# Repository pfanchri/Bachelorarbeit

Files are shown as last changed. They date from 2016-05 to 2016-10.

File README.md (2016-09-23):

# Bachelorarbeit

* DVD Basisstation
* |
* +-Altium										
* | +-Box\
* | +-Libraries\
* | +-mobile Basisstation\
* | | +-Project Outputs for mobile Basisstation\
* | | +-Basisstation.SchDoc
* | | +-TDA5340.SchDoc
* | | +-XMC4500.SchDoc
* | | +-Ethernet.SchDoc
* | | +-Power Supply.SchDoc
* | | +-mobile Basisstation.PrjPcb
* | | +-mobile Basisstation.pdf
* | | +-PCB_Testplatine.PcbDoc
* | | +-PCB_Testplatine - GND mit Tracks.PcbDoc
* | | +-…
* | |
* | +-PCB\
* | +-TDA Layout von Stefan Erhard\
* | 
* |
* +-Datenblätter
* | +-allgemein\
* |
* |
* +Dave
* | +-Basisstation\
* | | +-Basisstation
* | | +-Simple_Main_Projekt
* | | +-TDA_XMC4500_PMA_testtrans
* | | +-USBLIB_VIRTUALSERIAL_XMC45
* | | +…
* | | 
* | +-Hilfen\
* | +-Libraries\
* | +-Registerberechnungen\
* | +-Treiber\
* | +-Seriennummer verwendete TDAs.txt
* |
* |
* +Latex
* | +-Bachelorarbeit\
* | | +-Abbildungen\
* | | | +-Aufnahmen\
* | | | | +-Bilder\
* | | | | +-Empfangene Daten\
* | | | | +-Logic Analyser\
* | | | | +-SmartPDF\
* | | | +-…
* | | |
* | | +-Abschnitte\
* | | +-Quellen\
* | | +-bibliography.bib
* | | +-Thesis.pdf
* | | +-Thesis.tex
* | | +-…
* | |
* | +-circuitikz-master\
* | +-auszug_din_1338.pdf
* | +-Latex Vorlage.zip
* 
*

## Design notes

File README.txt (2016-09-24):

#################### Lehrstuhl für Technische Elektronik ####################
 Prof. Dr.-Ing. Dr.-Ing. habil. Robert Weigel, Prof. Dr.-Ing. Georg Fischer
####################### Bachelorarbeit im Studiengang #######################
          „Elektrotechnik, Elektronik und Informationstechnik (EEI)“
#################### von Christof Pfannenmüller zum Thema ###################
Aufbau und Inbetriebnahme einer mobilen Basisstation für feldstärkebasierte
Lokalisierung

                  Betreuer: Dipl.-Ing. Felix Pflaum
                  Beginn: 25.04.2016 Abgabe: 26.09.2016
#############################################################################
Die folgende Übersicht zeigt die enthaltenen Dateien und Verzeichnisse:

* DVD Basisstation
* |
* +-Altium										
* | +-Box\						-Daten zum erstellten Gehäuse in SolidWorks
* | +-Libraries\					-importierte und eigene Altium Bibliotheken
* | +-mobile Basisstation\				-Projektordner Altium
* | | +-Project Outputs for mobile Basisstation\	-enthält Output-Jobfiles (Gerber, Schaltplan etc.)
* | | +-Basisstation.SchDoc				-Schaltplan Modulübersicht Basisstation
* | | +-TDA5340.SchDoc					-Schaltplan Transceiver TDA5340
* | | +-XMC4500.SchDoc					-Schaltplan Mikrocontroller XMC4500
* | | +-Ethernet.SchDoc					-Schaltplan Ethernet
* | | +-Power Supply.SchDoc				-Schaltplan für Power Supply
* | | +-mobile Basisstation.PrjPcb			-Hauptdatei für Altium Designer
* | | +-mobile Basisstation.pdf				-Layout als PDF
* | | +-PCB_Testplatine.PcbDoc				-PCB-Datei Altium Original
* | | +-PCB_Testplatine - GND mit Tracks.PcbDoc		-PCB-Datei Altium vor eingefügten Masseflächen
* | | +-…
* | |
* | +-PCB\						-Dateien über den Platinenhersteller
* | +-TDA Layout von Stefan Erhard\			-Layout des Aufsteckboards für den „XMC 2Go“
* | 
* |
* +-Datenblätter					-Datenblätter der verwendeten Bauteile
* | +-allgemein\					-Application Notes und Informationen zu Infineon
* |
* |
* +Dave
* | +-Basisstation\
* | | +-Basisstation\					-DAVE Projektordner
* | | +-Simple_Main_Projekt\				-Testprojekt zur Einführung in DAVE
* | | +-TDA_XMC4500_PMA_testtrans\			-Projekt für das im Feldtest verwendete Relax Kit
* | | +-USBLIB_VIRTUALSERIAL_XMC45\			-Beispielprojekt für virtuellen seriellen Port
* | | +…
* | | 
* | +-Hilfen\						-Hilfen zur Programmiersprache C
* | +-Libraries\					-verwendete Bibliotheken (Originale ohne Änderungen)
* | +-Registerberechnungen\				-enthält Berechnungen für Sende-/Empfangsfrequenzen
* | +-Treiber\						-Treiber für virtuellen COM-Port am Hostcomputer
* | +-Seriennummer verwendete TDAs.txt			-Seriennummern der verwendeten Transceiver
* |
* |
* +Latex
* | +-Bachelorarbeit\					-Latex Hauptordner
* | | +-Abbildungen\					-Bilder/Daten für Latex (enthält auch nicht verwendete)
* | | | +-Aufnahmen\					
* | | | | +-Bilder\					-Screenshots der verwendeten Programme
* | | | | +-Empfangene Daten\				-Aufgezeichnete Daten der Übertragungen
* | | | | +-Logic Analyser\				-Daten Logic Analyser
* | | | | +-SmartPDF\					-PDFs der Altium-Projekte mit Verlinkungen
* | | | +-…
* | | |
* | | +-Abschnitte\					-Kapitel des Latex-Dokuments
* | | +-Quellen\					-gespeicherte verwendete Quellen
* | | +-bibliography.bib				-Bibliografie-Datei für Latex
* | | +-Thesis.pdf					-erstellte Ausarbeitung als PDF-Datei
* | | +-Thesis.tex					-Latex-Date der erstellten Ausarbeitung
* | | +-…
* | |
* | +-circuitikz-master\				-Dateien für circuitikz
* | +-auszug_din_1338.pdf				-Auszug DIN 1338 zur Formatierung
* | +-Latex Vorlage.zip					-Latex-Vorlage LTE
* |
* |
* +Bilder						-aufgenommene Bilder der Bestückung/des Feldtests
* | 
* | 
*
*

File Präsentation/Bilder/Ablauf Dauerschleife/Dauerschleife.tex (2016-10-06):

% EPC flow charts
% Author: Fabian Schuh
\documentclass{minimal}

\usepackage{pgf}
\usepackage{tikz}
\usepackage[utf8]{inputenc}
\usetikzlibrary{arrows,automata}
\usetikzlibrary{positioning}

\tikzset{
    state/.style={
           rectangle,
           rounded corners,
           draw=black, very thick,
           minimum height=2em,
           inner sep=2pt,
           text centered,
           },
}

\begin{document}

\begin{tikzpicture}[->,>=stealth']

 \node[state, text width=4.5cm] (Init1) 
 {Interrupt-Flagge gesetzt?};

  \node[state,    	% layout (defined above)
  text width=2.5cm, 	% max text width
  yshift=2.5cm, 		% move 2cm in y
  left of=Init1, 	% Position is to the right of QUERY
  node distance=1.5cm, 	% distance to QUERY
  anchor=center] (Start) 	% posistion relative to the center of the 'box'
  {Initialisierung};

 \node[state,    	% layout (defined above)
  text width=3cm, 	% max text width
  yshift=2cm, 		% move 2cm in y
  right of=Init1, 	% Position is to the right of QUERY
  node distance=1.7cm, 	% distance to QUERY
  anchor=center] (Wait) 	% posistion relative to the center of the 'box'
 {Warte auf Eingabe des Benutzers};

  \node[state,    	% layout (defined above)
  text width=4.5cm, 	% max text width
  yshift=-2cm, 		% move 2cm in y
  right of=Wait, 	% Position is to the right of QUERY
  node distance=3cm, 	% distance to QUERY
  anchor=center] (Init2) 	% posistion relative to the center of the 'box'
  {Schalte alle Transceiver an,\\
  	Initialisiere XMC-Pins für Interrupts,\\
  	Initialisiere SPI-Modul};
  
%  warte, bestätige durch LED Blinken
 
  \node[state,    	% layout (defined above)
  text width=2cm, 	% max text width
  yshift=2cm, 		% move 2cm in y
  right of=Init2, 	% Position is to the right of QUERY
  node distance=2.5cm, 	% distance to QUERY
  anchor=center] (InitTDA) 	% posistion relative to the center of the 'box'
  {Initialisiere Transceiver};
  
   \node[state,    	% layout (defined above)
   text width=3cm, 	% max text width
   yshift=-2cm, 		% move 2cm in y
   right of=InitTDA, 	% Position is to the right of QUERY
   node distance=2.5cm, 	% distance to QUERY
   anchor=center] (setvariables) 	% posistion relative to the center of the 'box'
   {Löschen der Datenspeicher,\\
   	Interrupt-Status-Flaggen zu Null setzen};

 %ausgabe Warte auf Übertragungen

  \node[state,    	% layout (defined above)
  text width=2.3cm, 	% max text width
  yshift=2cm, 		% move 2cm in y
  right of=setvariables, 	% Position is to the right of QUERY
  node distance=1.7cm, 	% distance to QUERY
  anchor=center] (Dauer) 	% posistion relative to the center of the 'box'
  {Dauerschleife};

 % draw the paths and and print some Text below/above the graph

 \path 
 (Start)     	edge[bend right=20] node[anchor=south,above]{} (Init1)
 (Init1)     	edge[bend right=20] node[anchor=south,above]{} (Wait)
  (Wait)     	edge[bend right=20] node[anchor=south,above]{} (Init2)
   (Init2)     	edge[bend left=20] node[anchor=north,above]{Warten~~~~~~~~~} (InitTDA)
 (InitTDA)  	edge[loop above]    node[anchor=north,above]{für alle Transceiver} (InitTDA)
   (InitTDA)     	edge[bend right=20] node[anchor=south,above]{} (setvariables)   
   (setvariables)     	edge[bend right=20] node[anchor=south,above]{} (Dauer);

\end{tikzpicture}

\end{document}

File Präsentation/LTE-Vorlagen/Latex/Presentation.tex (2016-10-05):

% -----------------------------------------------------------------------------
% LaTeX 4Beamer Slide Template Institute for technical electrics
% -----------------------------------------------------------------------------

% -------------Preamble--------------------------------------------------------

\documentclass{beamer}
% include usepackages
\input{input/use}

% set the path for figures (save Pictures in /graphics and call it directly
\graphicspath{{graphics/}}

% ---------Data for Titlepage--------------------------------------------------

% Title of Presentation
\title[Kurzform Titel]{Hier steht der Titel}
% Subtitle of Presentation
\subtitle{Untertitel}
% Authors
\author[Kurzform der Autoren]{Hier die Autoren}
% Affiliation
\institute[Kurzform]{Zugehörigkeit}
% Date (not in use)
%\date{13. April 2016}

% Titlepage at the beginning and end of the presentation
\AtBeginDocument{\titleframe}
\AtEndDocument{\titleframe}

% -----------------------------------------------------------------------------
% Beginn Document
% -----------------------------------------------------------------------------

\begin{document}

% Table of Contents
\begin{frame}
	\frametitle{Übersicht/Content}
	\tableofcontents[pausesections]
\end{frame}

% -------------Section 1------------------------------------------------------

\section{First Section}

\begin{frame}
\frametitle{Page with Title}
\end{frame}

\begin{frame}
Page without Title
\end{frame}

% -------------Section 2------------------------------------------------------

\section{Second Section}

% Subsection
\subsection{Minipage}

\begin{frame}
\frametitle{Minipage}
\begin{minipage}{0.45\textwidth}
	Left side
\end{minipage}	
\hfill
\begin{minipage}{0.49\textwidth}
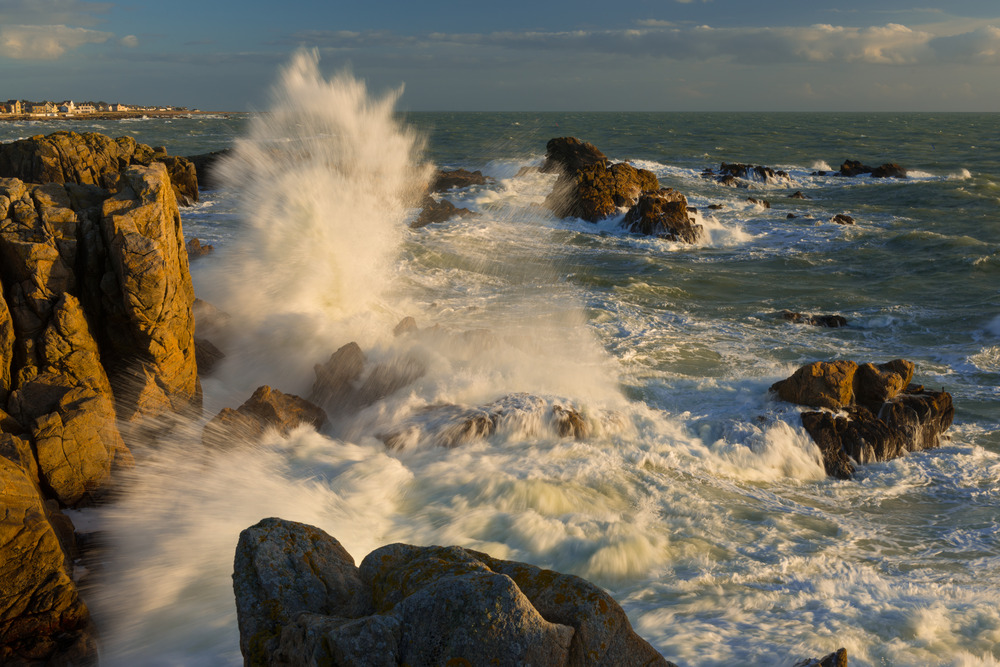
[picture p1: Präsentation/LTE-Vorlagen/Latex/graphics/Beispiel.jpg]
	
\end{minipage}
\end{frame}

% Subsection
\subsection{Columns}

\begin{frame}
\frametitle{Columns}
\begin{columns}	
	\begin{column}[c]{0.6\textwidth}

		\Large\textbf{Left side}\\
	
	\end{column}

	\begin{column}[c]{0.4\textwidth}

		\Large\textbf{Right side}\\
		
	\end{column}
\end{columns}
\vspace{1.5cm}
Below

Listing:
\begin{itemize}
	\item First item
	\item second item
\end{itemize}
\end{frame}

% -------------Section 3------------------------------------------------------

\section{Third Section}

\begin{frame}
	\begin{minipage}{0.45\textwidth}
	\textbf{Auflistung}
	\begin{enumerate}
		\item Punkt 1
		\item Punkt 2
		\item Punkt 3
	\end{enumerate}
\end{minipage}	
\hfill
\begin{minipage}{0.49\textwidth}
	
\end{minipage}
\end{frame}

\begin{frame}[plain]
\centering
\hfill
\hfill\\

\centering
\huge Vielen Dank für Ihre Aufmerksamkeit!
\end{frame}

\end{document}

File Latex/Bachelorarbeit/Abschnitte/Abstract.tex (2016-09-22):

% Abstract
\newpage
\chapter*{Abstract}
\label{sec:abstract}
\pagestyle{scrheadings}

Current localization measurements by magnitude and phase of electromagnetic waves have been complex and consume plenty of energy. However, almost every receiver has knowledge of the electrical field strength, correlating to distance from transmitter, this information is nearly unused. A multi transceiver base station should start communication with a mobile wireless sensor. The relative positioning to the base could be calculated by the received signal strength (RSSI) already provided from transceivers without additional components. Due to the permeability of walls, the possible range and the wavelength, associated to resolution of localization,   Sub-GHz frequency range is used.  Therefore six identical transceiver-ICs were arranged over all horizontal directions in space. By detachable design of the transceiver-modules a rearranging of the antennas was made feasible to provide different distances for best resolution of localization. The ICs were controlled by a XMC4500 microcontroller connected to the transceivers with SPI and IRQ line for finished transmission. Distribution of received data and signal strength measurements to a host computer is accomplished by the XMC4500 over Ethernet and USB.

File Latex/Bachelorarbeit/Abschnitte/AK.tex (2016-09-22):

%Abkürzungsverzeichnis
\newpage
\chapter*{Abkürzungsverzeichnis}
\label{sec:ak}
\pagestyle{scrheadings}

\begin{acronym}[CMSIS] %statt Bash die Längste Abkürzung einfügen
	\acro{PCB}{Printed Circuit Board}
	\acro{EDA}{Electronic Design Automation}
	\acro{CAD}{Computer-aided design}
	\acro{SMD}{Surface-mounted device}
	\acro{SPI}{Serial Peripheral Interface}
	\acro{DRC}{Design-Rule-Check}
	\acro{FIFO}{First In – First Out}
	\acro{NCS}{Non-Chip-Select}
	\acro{IC}{Integrierter Schaltkreis \acroextra{(integrated circuit)}}
	\acro{SMA}{Sub-Miniature-A}
	\acro{LQFP}{Low Profile Quad Flat Package}
	\acro{BGA}{Ball Grid Array}
	\acro{JTAG}{Joint Test Action Group}
	\acro{TVS}{Transient Voltage Suppressor}
	\acro{LDO}{Low Drop-Out}
	\acro{SOT}{Small Outline Transistor}
	\acro{STEP}{Standard for the Exchange of Product Model Data}
	\acro{NC}{Numerical Control}
	\acro{IDE}{Integrated Development Environment}
	\acro{GUI}{Graphical User Interface}
	\acro{SDK}{Software development kit}
	\acro{CPU}{Central Processing Unit}
	\acro{ETH}{Ethernet MAC \acroextra{(Ethernet Medium Access Control)}}
	\acro{USB}{Universal Serial Bus}
	\acro{GPIO}{General Purpose Input/Output}
	\acro{USIC}{Universal Serial Interface Channel}
	\acro{ISR}{Interrupt Service Routine}
	\acro{ERU}{Event Request Unit}
	\acro{ERS}{Event Request Select}
	\acro{ETL}{Event Trigger Logic}
	\acro{OGU}{Output Gating Unit}
	\acro{NVIC}{Nested Vectored Interrupt Controller}
	\acro{CMSIS}{Cortex Microcontroller Software Interface Standard}
	\acro{GND}{Masse \acroextra{(Ground)}}
	\acro{MISO}{Master-In Slave-Out}
	\acro{MOSI}{Master-Out Slave-In}
	\acro{ASCII}{American Standard Code for Information Interchange}
	\acro{IRQ}{Interrupt Request}
	\acro{PLL}{Phasenregelschleife \acroextra{(phase-locked loop)}}
	\acro{AGC}{Automatic Gain Control}
	\acro{RSSI}{Received Signal Strength Indication}

	%todo: ordnen nach auftrten
%	miso Mosi hinzufügen; GND??
\end{acronym}

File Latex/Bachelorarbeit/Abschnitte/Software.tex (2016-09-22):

\chapter{Software}
\label{sec:Software}
\pagestyle{scrheadings}
\section{DAVE Entwicklungsumgebung}

Das Programm DAVE (Digital Application Virtual Engineer) wird von Infineon Technologies AG entwickelt. Es basiert auf der Entwicklungsumgebung oder \ac{IDE} \enquote{eclipse}, die von der Eclipse Foundation entwickelt wird. Eine \ac{IDE} beschreibt dabei allgemein ein Programm zur Softwareentwicklung, welches die einzelnen dazu notwendigen Tools gesammelt zur Verfügung stellt. Dies sind vor allem der Compiler, der Linker, und der Debugger, auf die im folgenden noch eingegangen werden soll. DAVE stellt eine Möglichkeit zum Editieren von Quelltexten und Anordnen der einzelnen Programmdateien bereit. Über den enthaltenen GNU C-Compiler wird der erstellte Quellcode in vom XMC lesbare Maschinensprache übersetzt und anschließend durch den Linker zu einem ausführbaren Programm vereint. Durch den enthaltenen Debugger kann das Programm in den Speicher des XMC geladen werden. Dort kann der Programmablauf gestartet und gestoppt werden, außerdem können Werte einzelner Register und Variablen ausgelesen werden \cite{dausmann2011c}. 

DAVE greift bei der Programmierung von Mikrocontrollern der XMC-Serie auf die so genannten XMC Libraries zurück, die von Infineon ebenfalls zur Verfügung gestellt werden.  Auf diese soll ebenfalls im weiteren Verlauf  eingegangen werden. Ein weiteres Feature in der \ac{IDE} sind die sogenannten DAVE APPs. Mit diesen soll die Programmierung des Mikrocontrollers durch ein \ac{GUI} ermöglicht werden. Dazu werden für  mögliche von der Hardware zu verrichtende Teilaufgaben APPs von Infineon bereitgestellt. Durch das Einfügen der entsprechenden APPs in das Projekt können diese angepasst und miteinander grafisch verschalten werden. So wird der spätere Programmablauf im Mikrocontroller und dessen Aufgaben festgelegt. Nachdem vom Programmierer noch die Pins ebenfalls grafisch den Aufgaben zugeordnet werden, generiert  DAVE  den Programmcode mit den in den APPs enthaltenen Informationen \cite{DAVEQuickStart}.
Mithilfe des DAVE \ac{SDK} können nicht nur die Parameter der APPs beim Programmieren, sondern auch diese selbst grundlegend angepasst werden und das Entwickeln eigener APPs ist möglich \cite{DAVE-Version-4}.

Im Verlauf dieser Arbeit wurden DAVE  APPs jedoch nur in einem bereits existierenden Softwareprojekt für ein Relax Kit genutzt, mit welchem  Signale zum Testen der Empfänger an die Basisstation gesendet wurden. In der Basisstation selbst wurden die APPs nicht benutzt.

\section{Verwendete Peripherie des XMC4500}

Der XMC4500-Baustein enthält diverse funktionelle Blöcke, die mit einer Bus Matrix an die ARM Cortex-M4 \ac{CPU} angebunden sind. Dieser Aufbau soll den Prozessor entlasten und im Programmablauf Ressourcen für andere Operationen freihalten.
Für die Basisstation waren vor allem der \acs{USIC}, der \ac{USB} sowie der \ac{ETH} die bedeutenden Peripherien. Von besonderer Bedeutung sind jedoch die \acp{GPIO}.
\begin{figure}[h]
\centering

\caption{Blockdiagramm zur Peripherie des XMC4500 Mikrocontroller und die Anbindung an den Cortex-M4 Kern \cite{XMC-DataSheet}}
\label{fig:xmcblockdiagram}
\end{figure}

\subsection{GPIO}
Die \acp{GPIO} werden im sogenannten PORTS-Modul der XMC-Architektur gesteuert. In dieser lassen sich die Treiberstufen für die entsprechenden Pins des Mikrocontrollers regeln. Dieses Modul ist über die Peripheriebrücke PBA1 ebenfalls an die Bus Matrix \index{Bus Matrix} und somit an den Cortex-M4 Kern angebunden.  %Programmable port driver control module (PORTS) Abkürzung richtg?dann einfügen
%Bild StructureDigitalPin einbinden
%beschreiben wie pins belegt sind, wann GPIO bzw wann module (s. Pinbelegung) auf Pins liegen ( bei POSIF Kapitel beschreiben

Das Modul stellt für jeden Pin die erste Funktionsauswahl bereit und legt so die Datenrichtung fest. Im \enquote{Port Input/Output Control Register} des Moduls wird für jeden Pin festgelegt, ob er als Eingang oder Ausgang verwendet wird. Das momentane elektrische Potential am Eingang wird bei letzterer Konfiguration mit einem Schmitt-Trigger in ein binäres logisches Signal übersetzt. Ist der Pin ein Eingang, so kann das logische Eingangssignal dort zusätzlich invertiert werden. Wird ein Pin des XMC als Ausgang konfiguriert, so kann gesteuert werden, ob es sich um einen \ac{GPIO}-Pin handelt, dessen Status von der Software direkt festgelegt wird. Dabei kann ausgewählt werden, ob das logische Ausgangssignal durch einen Treiber in Open-Drain-Konfiguration oder durch Push-Pull erzeugt werden soll. 

Zur Nutzung eines Ausgangs durch die im Mikrocontroller verfügbare Peripherie sind diese direkt mit den entsprechenden Modulen verbunden. Dadurch kann das Modul selbst den elektrischen Zustand am Eingang auslesen und verwerten oder festlegen, ob es sich um einen Ausgang handelt \cite{XMC-Reference}. 
Auch das weitere Verhalten von Pins, wie etwa  beim Anschalten, bevor die Versorgungsspannung ein gültiges Level erreicht hat, lässt sich im PORTS-Modul anpassen.
\begin{figure}[h]
	\centering
	
	\caption{Struktur eines Digitalpins des XMC Mikrocontrollers \cite{XMC-Reference}}
	\label{fig:structuredigitalpin}
\end{figure}

\subsection{USIC}
Die \acp{IC} der XMC-Familie verfügen über ein Modul zur Kommunikation über diverse serielle Protokolle, den \acf{USIC}. Dieses ist programmierbar und erlaubt damit eine individuelle Verwendung, kann aber gleichzeitig die notwendigen Arbeiten für den Prozessor übernehmen. Der XMC4500 verfügt über insgesamt sechs \ac{USIC}-Kanäle und kann somit mehrere Protokolle gleichzeitig verwenden. Die Mikrocontroller unterstützen die  Protokolle UART, I$^{2}$C, IIS, LIN und das für die Basisstation verwendete SPI in einfacher, doppelter und quad-Ausführung. Für diese Arbeit wurde die gesamte Kommunikation mit einem gemeinsamen \acs{USIC}-Kanal umgesetzt. Da die einzelnen \acp{USIC} und deren Kanäle verschieden viele Slave-Select-Leitungen besitzen, wurde der Kanal $0$ des \ac{USIC} $0$ ausgewählt. Den nur dieser verfügt über die benötigten sechs Select-Leitungen. Eine Umsetzung mit einem anderen USIC wäre ebenfalls möglich gewesen. Die Wahl des Transceivers hätte dann aber manuell erfolgen müssen und hätte nicht vom Modul geregelt werden können.
%beschreiben Funktion
%wo SPI allgmein beschreiben
\begin{table}
	\centering
	\begin{tabular}{cc}
		
		Signal & Port/Pin des XMC \\ 
		\hline 
		MISO & 1.5 \\  
		MOSI &  1.7\\ 
		SCK (Clock) & 1.6 \\ 
		Select TDA1 & 1.11 \\  
		Select TDA2 &1.8  \\ 
		Select TDA3& 4.6 \\  
		Select TDA4& 4.5 \\  
		Select TDA5& 4.4 \\ 
		Select TDA6& 4.3 \\ 
	\end{tabular} 
	\caption[Zuordnung der SPI-Signale an die Pins des Mikrocontrollers]{Zuordnung der für die SPI-Kommunikation notwendigen Signale an die Pins des Mikrocontrollers. Alle Leitungen sind mit dem Kanal $0$ der USIC $0$ verbunden}
	\label{tab:SPI}
\end{table}

\subsection{ERU}
Von zentraler Bedeutung für die Funktion der Basisstation war die Behandlung von Interrupts durch den  \ac{IC}. Der XMC4500 besitzt dafür zwei entsprechende \ac{ERU}-Module, die einen solchen erkennen können und den Prozessor zum Aufrufen einer \ac{ISR} auffordern können. Jedes Modul verfügt über vier Kanäle, auf denen  bei einem Interrupt ein vierstufiger Prozess durchlaufen wird: In der ersten Stufe der \ac{ERU}, der sogenannten \ac{ERS}, lassen sich aus zwei Eingängen mit jeweils vier Signalen die gewünschten Eingänge wählen. In der \ac{ETL} generiert der \ac{IC} aus dem Signalstatus ein Trigger-Event, indem Veränderungen erkannt werden. So kann eine fallende oder steigende Flanke, die einen Interrupt auslösen soll, erkannt werden. In der Cross Connection Matrix können Signale der verschiedenen \acp{ETL} zu den vier \acp{OGU} weitergeleitet und somit dort untereinander und mit Triggersignalen von anderen Peripherie-Modulen des XMC kombiniert werden.  In der \ac{OGU} wird durch Vergleich der verschiedenen aufgetretenen Trigger und Muster entschieden, ob ein kompletter Interrupt aufgetreten ist, worauf diese Information entsprechend weitergeleitet wird, oder ob etwa nur ein gewähltes Muster erkannt wurde, was für andere Module wichtig sein kann. Auch diese Informationen werden entsprechend an die Peripherie weitergeleitet, sind aber für die Funktion der Basisstation nicht weiter von Bedeutung. 
Bei Vorliegen aller Bedingungen für einen Interrupt wird diese Information an den \ac{NVIC} im Cortex-M4 weitergeleitet. Dieser Teil des Prozessorkerns erkennt die Interruptaufforderung und sorgt dafür, dass der aktuelle Prozessorstatus gespeichert wird. Nach Ablauf der \ac{ISR} wird der Prozessorstatus wieder hergestellt.
%wo falsche wahl der Pins einbringen?
%Interrupt Request, IRQ im gegensatz zu isr https://de.wikipedia.org/wiki/Interrupt

\subsection{USB}
Das \ac{USB}-Modul des XMC4500 arbeitet nach den  Spezifikationen für USB 2.0 und den \enquote{On-The-Go}-Spezifikationen der Version 1.3. Der Mikrocontroller könnte durch das \ac{USB}-Modul entweder als Host oder als USB-Slave  arbeiten. In diesem Fall wurde der \ac{IC} als Slave betrieben. Das \ac{USB}-Modul verfügt über eine eigene Interruptsteuerung und ist damit eine der oben erwähnten Peripherien des XMC, deren Steuerung auch über Interrupts gelöst ist. Die gesamte Übertragung wird durch den \ac{USB}-Kern gesteuert und empfangene oder zu sendende Pakete werden in einem \ac{FIFO}-Puffer gespeichert. Für die Kommunikation der Basisstation mit dem Host-Computer wird ein virtueller COM-Port durch das \ac{USB}-Interface emuliert.

\subsection{Ethernet} 
Im XMC4500 werden Netzwerkverbindungen durch das  Ethernet-Modul behandelt. Dieses unterstützt Datenübertragungen mit Geräten über IPv4 und IPv6 sowie Übertragungsraten von \unit[10/100]{MBit/s}.  Dazu werden zunächst die Daten von der CPU über ein Bus-Interface übertragen. Im \enquote{MAC Transaction Layer} werden die vom Prozessor bzw. über Ethernet empfangenen Datenpakete zwischengespeichert. Der Ethernet-Kern formatiert die zu sendenden Daten und stellt sie einem \enquote{Physical Layer} zu, welches die Daten für den Kanal moduliert.

\section{Verwendete Bibliotheken}
\subsection{XMC Library (XMC Lib)}
Infineon stellt für seine \acp{IC} der XMC4000 Serie, zu der auch der XMC4500 gehört, die \enquote{XMC Peripheral Library} bereit. Diese erlaubt einen vereinfachten Zugriff auf alle Module und die entsprechenden Register und soll dadurch den Modulzugang übersichtlich gestalten und den Programmcode vereinfachen und leichter lesbar machen. Die Software baut auf dem \ac{CMSIS} auf, erlaubt die Verwendung verschiedener Compiler und kann kann mit oder ohne DAVE bzw. mit oder ohne DAVE APPs verwendet werden. %C99 usage +  weiter beschreiben etc
Für die Programmierung wurde mit der Software \enquote{doxygen} eine Dokumentation zur Bibliothek als HTML generiert.

\subsection{SPI Library}
Die verwendete Bibliothek zur Steuerung des \ac{SPI}-Interfaces basiert auf dem \ac{SPI}-Modul der XMC Library. Die von Infineons XMC Library zur \ac{SPI}-Kommunikation zur Verfügung gestellten Funktionen steuern das \ac{USIC}-Modul des Mikrocontrollers an. Die Bibliothek zur \ac{SPI}-Kommunikation muss somit nur noch die Funktion
\begin{lstlisting}
XMC_SPI_CH_Transmit(channel, data, XMC_SPI_CH_MODE_STANDARD);
\end{lstlisting} der XMC Library aufrufen, um eine Übertragung über das serielle Interface durchzuführen. Daneben liegt die Hauptaufgabe der Bibliothek vor allem in der Auswahl des entsprechenden Transceivers über das Slave-Select-Signal. Dazu initalisiert die Bibliothek zuerst den \ac{USIC} entsprechend den in der Headerdatei vorgegebenen Pins für MISO, MOSI und den Pins zur Auswahl des jeweiligen Slaves.

\subsubsection*{SPI Übertragung}
%todo: verschieben?
Die durch die Software umgesetzte serielle Übertragung zwischen den \acp{IC} entspricht dem \ac{SPI}-Protokoll, das ursprünglich von Motorola entwickelt wurde \cite{BuchSPI}. Durch das Chip-Select–Signal wählt der XMC den entsprechenden Transceiver aus. Da der TDA5340 active-low arbeitet, also bei anliegendem \ac{GND}-Potential als ausgewählt gilt, wird dieser Eingang im Datenblatt auch als \acf{NCS} bezeichnet. 

Der \ac{USIC} des XMC beginnt nun die Clockleitung des Busses zu treiben. Eine Periode dieser zyklischen Rechteckspannung begrenzt dabei die Zeit, in der auf den \ac{MOSI} und \ac{MISO}-Leitungen ein Bit übertragen wird. Hierbei existieren verschiedene Konfigurationen: so kann die Clock-Leitung im Ruhezustand einen High- oder einen Low-Pegel aufweisen, was durch die Polarität (CPOL) festgelegt wird. Das Auslesen der Spannungswerte auf den Datenleitungen kann bei fallender und steigender Taktflanke (CKPHA) durchgeführt werden, woraus sich insgesamt vier Kombinationsmöglichkeiten ergeben. Im vorliegenden Fall war sowohl das CPOL- als auch das CKPHA-Bit $1$, es wurde also bei jeder fallenden Flanke ein Bit übernommen und das Clocksignal wies zum Ruhezeitpunkt einen High-Pegel auf.

Bei der Übertragung stellt nach der Definition aus dem Datenblatt des Transceivers ein  Spannungspegel von \unit[0]{V} auch eine logische $0$ dar. In der Kommunikation mit den TDA5340 werden jeweils acht Bit zu einem Datenwort zusammengefasst. Der Transceiver erwartet mit dem ersten Datenwort eine Instruktion und je nach Art dieser noch einen Parameter durch die Übertragung des folgenden Wortes. Mögliche Anweisungen sind dabei das Lesen oder Schreiben eines Registers, dessen Adresse als Parameter übertragen wird, das Auslesen oder Beschreiben der \ac{FIFO}-Speicher oder das Setzen des TDA5340 in den so genannten \enquote{Transparent Mode}, auf den nicht weiter eingegangen werden soll. Nach Übertragung von Instruktion und Parameter werden entweder vom Master oder vom Slave, also vom Transceiver, die gewünschten Daten übertragen.

\begin{table}[tbh]
	\centering
	\begin{tabular}{lcl}
		
		Instruktion & Datenwort & übergebener Parameter  \\
		\hline
		Register Schreiben (schnell) & 0x01 & Adresse erstes zu schreibendes Register   \\
		Register Schreiben & 0x02 & Adresse zu schreibendes Registers   \\  
		Register Lesen & 0x03 & Adresse  zu lesendes Registers  \\  
		FIFO Lesen & 0x04 &  $kein Parameter$ \\  
		Register Lesen (schnell) & 0x05 & Adresse erstes zu lesendes Register   \\  
		FIFO Schreiben & 0x06 & Länge der Übertragung -1   \\  
	\end{tabular}
	\caption[SPI-Instruktionen des Transceivers und die entsprechenden Datenwörter]{SPI-Instruktionen des Transceivers und die entsprechenden auf der MOSI-Leitung übertragenen Datenwörter und Parameter. Die beiden Instruktionen zum transparenten Senden sind nicht enthalten}
	\label{tab:SPIcommands}
\end{table}

Beim Schreibzugriff auf den TDA kann durch geeignete Instruktion gewählt werden ob, nur auf ein Register geschrieben wird oder ob der Transceiver nachfolgende Datenwörter als Werte in die folgenden Register übernehmen soll. 
Beim Lesezugriff besteht dieselbe Auswahlmöglichkeit. Bild \ref{fig:spistart} zeigt den Start einer solchen \ac{SPI}-Kommunikation zwischen dem Transceiver TDA1 und dem Mikrocontroller. Die Dauer der Übertragung betrug etwa \unit[0,26]{ms}. Bei dieser wurde die Instruktion \enquote{Read from Chip}, dargestellt durch den Hexadezimalwert 0x03, und die Registeradresse 0xD3, als Parameter vom Mikrocontroller zum Transceiver übertragen. Dieser teilt durch das folgende Datenwort auf der \ac{MISO}-Leitung, in diesem Fall 0xFF, den aktuellen Wert des Registers mit. Der Master beendet daraufhin die Kommunikation durch einen High-Pegel an der Select-Leitung.

\begin{figure}[h]
\centering

\caption{Start einer SPI-Übertragung zwischen dem Mikrocontroller und dem Transceiver}
\label{fig:spistart}
\end{figure}

\subsection{TDA5340 Library}
Die Hauptaufgabe in der Kommunikation mit den Transceiver-\acp{IC} wurde durch die vorgegebene Bibliothek für den TDA5340 übernommen. Diese stellte Funktionen zum Senden und Empfangen von Daten mit dem Transceiver zur Verfügung. Die Bibliothek liest dazu den Empfangs-\ac{FIFO} aus oder schreibt in den Puffer für zu sendende Daten. Auch der Lese- und Schreibzugriff auf die Steuerregister der Transceiver kann über die Bibliothek geregelt werden. Dazu stellt die Bibliothek auch entsprechende Makros bereit, welche die Namen der Register in die hexadezimale entsprechende Adresse umwandeln, um so die Lesbarkeit erheblich zu erhöhen. Daneben wurden über die Bibliothek auch die notwendigen  Einstellungen für das Erkennen von Interrupt im XMC4500 vorgenommen. In diesem Bereich waren die notwendigen Anpassungen der Library am tiefgreifendsten, da diese nur für die Interruptbehandlung mit einem Transceiver ausgelegt war. Bei anderen Funktionen der Bibliothek waren nur kleinere Anpassungen notwendig, sodass etwa sichergestellt wurde, für welchen Transceiver die aufgerufene Funktion ausgeführt werden sollte, etwa bei welchem das entsprechende Register ausgelesen wurde.
Zur Verbindung mit den TDA5340 verwendete die Bibliothek die bereits erwähnte SPI Library. Dieser Bibliothek für die SPI-Verbindung wird daher die Nummer des Transceivers als Chip-Select übergeben um sicherzustellen, dass mit dem Richtigen  kommuniziert wird.

\subsection{Virtueller COM Port}
Die Kommunikation der Basisstation mit dem Hostcomputer zum Übertragen der gemessenen Werte wurde nach dem Vorbild eines Beispielprojektes für DAVE umgesetzt. Die Bereitstellung des virtuellen seriellen Ports erfolgt auf Seiten des XMC über die LUFA (Lightweight USB Framework for AVRs)-Bibliothek. Mit dieser beschränkt sich die Ausgabe über den COM-Port auf das Übergeben der zu sendenden Zeichen an eine entsprechende Funktion. Eine Steuerung des XMC durch Empfangen von Daten über den COM-Port wäre mit der Bibliothek ebenfalls möglich, dies war jedoch nicht notwendig.
Die Bibliothek und das Beispielprojekt wurden dahingehend angepasst, dass ganze Zeichenketten statt nur einzelner Zeichen der Funktion zum Senden übergeben werden konnten. Auch wurde das Senden von Integer-Variablen ermöglicht, indem diese zu Zeichen umgewandelt wurden. Dabei wurde der \ac{ASCII} beachtet, nach dem die Übertragung funktioniert. So benötigt der COM-Port zur Ausgabe und Darstellung der Ziffer $1$ den dezimalen Wert $49$ nach der Vorgabe durch den \ac{ASCII}-Code.

\section{Programmablauf}
\begin{figure}[h]
\centering

\caption{Programmablauf der Basisstation}
\label{fig:initialisierung}
\end{figure}

Im Programmablauf des XMC wurde zunächst eine Warteschleife umgesetzt, in welcher der Mikrocontroller auf eine erste Eingabe durch den Benutzer am Hostcomputer wartet. Bereits hier wurde die Übertragung über den seriellen COM-Port initialisiert. Nachdem diese Bestätigung über den COM-Port vom Mikrocontroller empfangen wurde setzt dieser zunächst alle Transceiver in den Schlafmodus, von welchem aus eine Kommunikation möglich ist. Daraufhin beginnt der XMC4500 mit der Konfiguration der für die Interrupts notwendigen Pins und ermöglicht somit das Empfangen von \acp{IRQ} durch die TDA5430. Anschließend initialisiert er zunächst das SPI-Modul, um im Folgenden die Transceiver darüber konfigurieren zu können. Bevor das dazu notwendige Schreiben in die Register der TDAs jedoch möglich ist, wird eine gewisse Verzögerung benötigt. Diese resultiert daher, dass der Wechsel des TDA vom ausgeschalteten Zustand in den Schlafmodus eine gewisse Zeitspanne benötigt. 
Im folgenden werden alle Transceiver initialisiert und anschließend in den Receiver-Modus gefahren.  
Daraufhin setzt der \ac{IC} noch alle für die Übertragung notwendigen Variablen  und alle Felder zum Speichern von Daten zu Null. 
Nun beginnt der Prozessor mit einer Dauerschleife, in der dieser auf das Ankommen von Übertragungen wartet und teilt dies auch dem Benutzer am Hostcomputer über eine Ausgabe mit. In dieser Endlosschleife wechselt sich die interruptbasierte Datenerfassung mit der Weiterleitung der erfassten Daten zyklisch ab, wobei nur bei erfolgreichem Empfang ein Senden an den steuernden Computer erfolgt. 
%todo: einfügen eines ablaufdiagramms?
%TODO:genauer alles?!; wo beschreiben? 

Bei der Programmierung wurde darauf geachtet, möglichst alle Konstanten wie Adressen von Pins und Ports durch Makros für den Präprozessor auszulagern. Dadurch konnte einerseits die Lesbarkeit des Quellcodes erhöht werden, andererseits sind so aber Änderungen durch Vertauschen von Pins sowohl in der Hardware als auch nur in der Software leichter möglich. Da es sich beim XMC4500 um einen Mikrocontroller mit einer 32-Bit-Architektur handelt, wurden Integervariablen ausschließlich vom Typ \textit{uint32\_t} oder \textit{int32\_t} verwendet. So konnte eine genaue Anpassung der Software an die Registergrößen im XMC vorgenommen werden.

\subsection{Konfiguration der Funkmodule}
Bei der Initialisierung erhalten die Transceiver die gewünschten Werte für die Sende- und Empfangsfrequenzen. Diese werden über die Teilerrate für die  \ac{PLL} übergeben und ermittelt. Der TDA5340 stellt dafür mehrere Konfigurationssätze zur Verfügung, in denen unterschiedliche Frequenzen eingestellt werden können. In diesem Fall wird zum Empfangen die Konfiguration A und Konfiguration B zum Senden eingestellt. Die entsprechenden Werte wurden zuvor aus der Zwischenfrequenz  $f_{IF2}=\unit[274]{kHz}$ und der gewünschten Übertragungsfrequenz errechnet.

Über die entsprechenden Register wird auch das Verhalten bei ankommenden Übertragungen eingestellt. Im \enquote{Interrupt Mask}-Register wurde eingestellt, bei welchen Ereignissen der Transceiver einen solchen auslösen wird. Zur Ausgabe der Interruptsignale wurde der standardmäßige PP2-Pin des Transceivers verwendet. PP1 und PP0 wurden in einen hochohmigen Zustand versetzt, da sie zum aktuellen Zeitpunkt nicht genutzt wurden.

%und rechnung aus exekl sheet einfügen

%TODO hier  fehlt etwas

\subsection{Interruptbasierte Datenerfassung}

Die Erfassung der Daten erfolgt im Programmablauf innerhalb der dauerhaften Ablaufschleife.
In der \acf{ISR}, in welche der Prozessor beim Auftreten eines Interrupts springt, wird lediglich einer globalen Variable der Wert $1$ zugeordnet. Für jeden der möglichen Transceiver existiert eine solche Flagge, die einen aufgetretenen Interrupt anzeigt. Nach dem Setzen in der \ac{ISR} kehrt der Prozessor zum Ablauf in die Dauerschleife zurück. Innerhalb dieser wird nun zyklisch abgefragt, ob diese Flagge gesetzt wurde. Beim Auftreten einer solchen Flagge, also nach dem aufgetretenen Interrupt, liest der XMC4500 die  Interrupt Status Register des entsprechenden Transceivers aus. 

Da davon auszugehen ist, dass alle sechs Transceiver-\acp{IC} zeitgleich eine Übertragung erhalten, wurde diese mehrstufige Abfrage gewählt. So wird zuerst nur in der \ac{ISR} die Flagge gesetzt, um die dadurch verstreichende Zeit möglichst kurz zu halten und zu ermöglichen, dass eine solche Flagge auch jederzeit im Programmablauf gesetzt werden kann. In der zweiten Stufe liest der Mikrocontroller nun die drei Interrupt Status Register aus. Dies ist notwendig, da es sich dabei um sogenannte \enquote{Read-Clear}-Register handelt, welche  nach dem Auslesen über SPI automatisch zurückgesetzt werden.
In den Interrupt-Registern sind die Ereignisse kodiert, die einen Interrupt ausgelöst haben. Bei der Konfiguration der Funkmodule wurde eingestellt, bei welchen Ereignissen der Transceiver einen Interrupt auslöst. Typische Ereignisse sind ein fast gefüllter Empfangs-\ac{FIFO}, was eine angekommene Übertragung anzeigt, oder auch ein leerer \ac{FIFO}, was anzeigt, dass dieser ausgelesen wurde. 

Die dritte Stufe  der Datenerfassung ist nun die Abfrage der Daten vom Transceiver. Da diese \ac{SPI}-Datenübertragung deutlich mehr Zeit in Anspruch nimmt, muss diese getrennt vom Erkennen der Interrupts und dem Auslesen der Interrupt-Register erfolgen. Da die gewünschten Werte in den Registern gespeichert sind, ist das Auslesen zeitkritisch, denn eine erneute Übertragung würde diese Messwerte überschreiben. Jedoch ist das Auslesen der Werte bei weitem nicht so zeitkritisch wie die ankommenden Interrupts, da diese im Verlauf einer Übertragung auch mehrfach ankommen können. Das Abfragen der empfangenen Daten aus dem \ac{FIFO}-Speicher hat eine noch geringere Priorität, da dieser die Datenpakete bis zum Auslesen behält. 

Eine Abfrage der Messwerte und ein Auslesen des \ac{FIFO} wird bei abgeschlossener Übertragung durchgeführt, diesen Zeitpunkt erkennt der Mikrocontroller durch das entsprechend gesetzte Bit des Interrupt-Register. Der XMC4500 speichert alle abgefragten Werte wie Feldstärke, die Einstellungen der \ac{AGC} und die angekommenen Daten in den vorbereiteten dedizierten Speichern. Abschließend werden die Transceiver wieder in den Empfangsmodus gesetzt. 

Beim Setzen der Flaggen durch den Interrupt fiel auf, dass die Interrupteingänge für Transceiver 3 und Transceiver 6 sich überlagern. So ist der PP2-Anschluss des dritten TDA5340 mit der \ac{ETL}3 der \ac{ERU}0 verbunden, ebenso wie der entsprechende Pin des TDA6. Grund dafür ist, dass die entsprechenden Pins des Mikrocontrollers auf den Kanal B3 bzw. A0 der genannten \ac{ERU}-\ac{ETL}-Kombination führen. Bei den ersten Tests von Interrupts auf diesen Kanälen stellte sich heraus, das der XMC, entgegen den Erwartungen, somit nicht in der Lage ist, ankommende Interrupts der beiden Transceiver zu unterscheiden. Durch entsprechende Einstellungen in der \ac{ERU}0 war ein Sprung des Prozessors in die entsprechende \acl{ISR} nur für jeweils einen der beiden Transceiver möglich. Um trotzdem ein Auslesen der beiden Transceiver zu bewirken, wurden beide Flaggen in der Service Routine gesetzt.
\begin{table}[h]
	\centering
\begin{tabular}{ccccc}
	Transceiver & Port/Pin am XMC & ERU & ETL & Kanal \\ 
	\hline
	TDA1 & 0.3 & 1 & 3 & B0 \\ 
	TDA2 & 1.0 & 0 & 3 & B0 \\ 
	TDA3 & 2.6 & 0 & 1 & B3 \\ 
	TDA4 & 2.1 & 1 & 0 & B0 \\ 
	TDA5 & 3.2 & 0 & 0 & A1 \\ 
	TDA5 & 0.10 & 0 & 1 & A0 \\ 
\end{tabular} 
\caption{PP2-Pins der Transceiver mit den entsprechenden Anschlüssen am XMC4500 und die Verbindung zur ERU}
\label{tab:PP2ERU}
\end{table}
Der Versuch, den PP2-Pin des TDA6 mittels eines kurzen Drahtes auf den Pin 142 des XMC4500 zu legen, schlug ebenfalls fehl. Dazu wurde der PP1-Pin des TDA1, welcher mit diesem Pin des Mikrocontrollers verbunden ist, im Transceiver 1 in einen hochohmigen Zustand geschaltet. Dieser Pin des XMC ist intern mit der \ac{ETL}2 der \ac{ERU}0 auf dem Kanal B3 verbunden. Da diese Kombination noch nicht verwendet wurde, hätte hier eine Interrupterkennung funktionieren müssen. Warum durch diese Veränderung kein Interrupt ausgelöst werden konnte, ist nicht klar. Da in der Betrachtung mit dem Logic-Analyser keine Flanke auf dem Netz festgestellt wurde, ist zu vermuten, dass das Problem aus der Verbindung mit dem Draht resultiert.
%unterscheidung der zwei interruptabfragen
%was steht in den registern drinnen und wird abgefragt

\subsection{Weiterleitung der erfassten Daten}
Dass eine Übertragung über den COM-Port bereits weit vor der Dauerschleife vom Mikrocontroller gestartet wurde, diente dazu, dem Benutzer  die Bereitschaft zum Empfangen mitzuteilen, sobald sämtliche Initialisierungen abgeschlossen waren. Somit musste der COM-Port auch nun nicht mehr selbst initialisiert werden.
Im zweiten Teil der Ablaufschleife des Programmes wurde nun die Weitergabe der empfangenen Daten und der gemessenen Werte behandelt. Dazu wurde nach dem Abholen der empfangenen Daten von den Transceivern eine Statusflagge in Form einer Integer-Variable gesetzt. Nur beim Auftreten dieser Flagge wurde der Programmteil zum Senden über den COM-Port ausgeführt.
Dort wurde nun jeweils abwechselnd ein Wert des Speichers und ein String mit einer Beschreibung oder dem Namen des Wertes über den COM-Port ausgegeben. Ein Ausschnitt des Quellcodes ist im Quellcode \ref{listing:COMsend} zu erkennen. Die Zeichenfolge $\backslash r\backslash n$ stellt dabei den Übergang in eine neue Zeile in der Ausgabekonsole dar. Wie in C üblich werden Strings in doppelten Anführungszeichen im Quelltext eingefügt. Eine entsprechende Ausgabe ist in Bild \ref{fig:ConsolePutty} zu erkennen. 
\begin{lstlisting}[caption={Ausschnitt aus dem Senden der Daten über den COM-Port},label={listing:COMsend},captionpos=b,language=C]
COM_send_string("#################### Übertragung erkannt ####################\r\n");
COM_send_string("Übertragung Nummer ");
COM_send_int_as_string(transfernumber);
COM_send_string("\r\n\r\n");
COM_send_string("TDA1:");
COM_send_string("\r\nPMF:");
COM_send_int_as_string(rssiTDA1.pmf);
COM_send_string("\r\nPRX:");
COM_send_int_as_string(rssiTDA1.prx);
COM_send_string("\r\nRX:");
COM_send_int_as_string(rssiTDA1.rx);
COM_send_string("\r\nPPL:");
COM_send_int_as_string(rssiTDA1.ppl);
COM_send_string("\r\nAGC:");
\end{lstlisting}
Am Hostcomputer wurden die Daten mit der Software \enquote{PuTTY} entgegengenommen und dem Benutzer in einer Konsole angezeigt. Dazu wurde der von Infineon zur Verfügung gestellte Treiber verwendet, um dem XMC4500 als COM-Port zu erkennen. %im Anhang/auf CD
Die Einstellungen der seriellen Übertragung wurden vom Beispielprojekt übernommen, sodass am Computer mit einer Baudrate von \unit[115200]{Bd} und acht Daten Bits pro Zeichen empfangen wurde,  was im Programm eingestellt werden musste. Nach der bereits erwähnten anfänglichen Bestätigung der Kommunikation durch den Nutzer wurden bei jeder vom Mikrocontroller erkannten Übertragung die gemessenen Feldstärkewerte ausgegeben. Neben den PMF, PRX RX, PPL und AGC-Werten wurde noch die Empfangsleistung ausgegeben. Diese wurde zur Laufzeit aus dem PPL und dem AGC-Wert errechnet und in dBm angezeigt. Dazu diente eine vorgegebene Funktion, welche aus dem PPL-Wert und dem Wert der \ac{AGC} mittels kalibrierter Parameter eine Feldstärke berechnete. Die Werte wurden in einem Vorprojekt durch Messungen kalibriert und sind hier nicht weiter von Bedeutung. Die Abkürzungen der übertragenen Werte sind in Tabelle \ref{tab:RSSI} aufgeführt.
\begin{table}[tbh]
	\centering
	\begin{tabular}{ll}
		
		PMF			&Peak Memory Filter\\
		PRX			&Peak Detector\\
		RX			&\acf{RSSI}\\
		PPL			&RSSI Payload Peak Detector\\
		AGC			&Automatic Gain Control\\
		
	\end{tabular}
	\caption{Verwendete Abkürzungen der übertragenen Messwerte}
	\label{tab:RSSI}
\end{table}
Die empfangenen Daten wurden ebenfalls ausgegeben. 
Alle Werte und Daten wurden nach Transceiver getrennt ausgegeben, um eine Vergleichsmöglichkeit zu geben und um die Ausgabe möglichst übersichtlich zu gestalten.
Auch wurden die empfangenen Übertragungen durchnummeriert und die entsprechende Übertragungsnummer mit ausgegeben. So ließen sich einerseits die Sendepositionen den gemessenen Werte zuordnen. Andererseits waren so aber auch  verlorengegangene  Übertragungen sichtbar. Eine typische Ausgabe der Konsole ist im Bild \ref{fig:ConsolePutty} zu erkennen. Zur Darstellung einer eingegangenen Übertragung an der Basisstation sollte die LED Nummer 7 nach jedem Empfangen kurz rot aufblinken.
\begin{figure}[h]
\centering
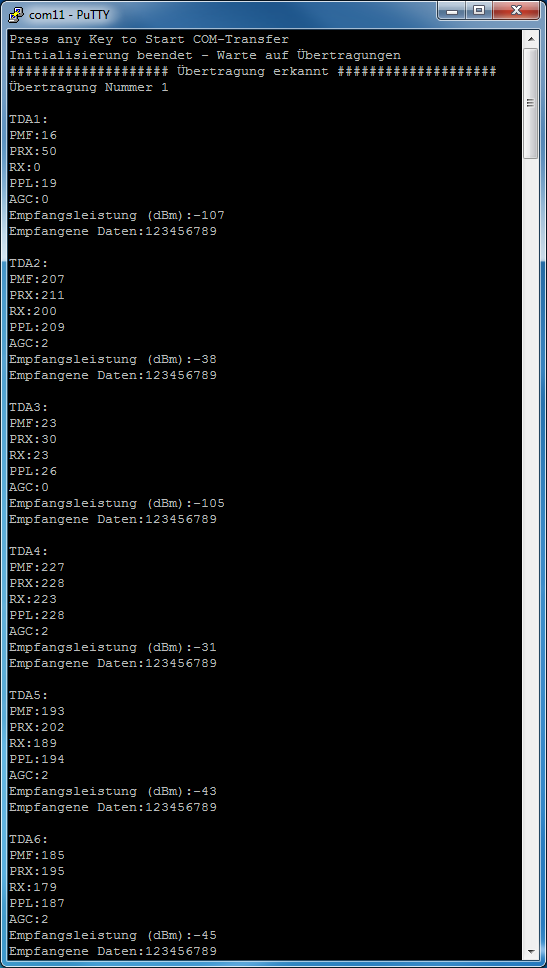
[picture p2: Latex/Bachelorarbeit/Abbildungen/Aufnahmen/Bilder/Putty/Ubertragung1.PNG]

\caption{Ausgabe des Mikrocontrollers über den COM-Port in der Konsole bei einer beispielhaften Übertragung}
\label{fig:ConsolePutty}
\end{figure}

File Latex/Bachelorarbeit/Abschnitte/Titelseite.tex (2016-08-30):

\begin{titlepage}
\ThisLRCornerWallPaper{0.66}{Abbildungen/Logo/Friedrich_logo_dunkel}
%\begin{center}
%\includegraphics[width=0.6\textwidth]{Abbildungen/Logo/FAUlogo.eps}
%\end{center}
\begin{figure}
\hfill

\end{figure}
%\newline
%\newline
\hspace{0.1cm}	
\center
\LARGE
	\textbf{Lehrstuhl für Technische Elektronik} \\
	Prof.~Dr.-Ing.~Dr.-Ing.~habil.~Robert~Weigel	\\
	Prof.~Dr.-Ing.~Georg~Fischer\\
\vspace{1cm}	

\LARGE
	\textbf{Bachelorarbeit}
\vspace{0.9cm}

\large
im Studiengang\\ \enquote{Elektrotechnik, Elektronik und Informationstechnik (EEI)}\\
\vspace{0.5cm}
von
\vspace{0.5cm}

\LARGE{
\authorname}
\vspace{0.7cm}

\large
zum Thema
\vspace{0.9cm}

\LARGE
\textbf{Aufbau und Inbetriebnahme einer mobilen Basisstation für 
feldstärkebasierte Lokalisierung}
\vspace{1.7cm}

\large
\begin{tabular}{ll}
Betreuer: & Dipl.-Ing. Felix Pflaum \\
 &\\
Beginn: & 25.04.2016\\
Abgabe: & 26.09.2016\\
\end{tabular}
\end{titlepage}

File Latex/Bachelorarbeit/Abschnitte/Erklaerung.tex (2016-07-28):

% Erklärung

\chapter*{Erklärung}
\label{sec:Erklärung}
%\newpage
%\thispagestyle{empty}
%\noindent
Ich versichere, dass ich die Arbeit ohne fremde Hilfe und ohne Benutzung anderer als der angegebenen Quellen angefertigt habe und dass die Arbeit in gleicher oder ähnlicher Form noch keiner anderen Prüfungsbehörde vorgelegen hat und von dieser als Teil einer Prüfungsleistung angenommen wurde. \\
\\
Alle Ausführungen, die wörtlich oder sinngemäß übernommen wurden, sind als solche gekennzeichnet. \\
\vspace{1.0cm}
\\
Erlangen, den 26. September 2016
\vspace{2.5cm}
\\
Christof Pfannenmüller

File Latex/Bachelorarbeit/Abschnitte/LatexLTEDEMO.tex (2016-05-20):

% Motivation

\chapter{Einleitung}\label{Einleitung}
Hier gehört die Einleitung/Motivation hin. Auf Kapitel \ref{Einleitung} kann so verwiesen werden.

\section{Nötige Programme}
Für die Arbeit mit Latex benötig man eine Tex-Distribution, verbreitet sind hier Miktex und TExlive, empfohlen wird Texlive(\url{https://www.tug.org/texlive/}) in der aktuellsten Version(Upgraden!).

Außerdem benötig man einen Editor, verbreitet sind hier Texniccenter, Texmaker, TexmakerX und Texstudio. Empfohlen wird Texstudio(\url{http://www.texstudio.org/}).

Für die Literaturverwaltung (Erstellen der Bibfiles )kann ein einfacher Texteditor(Notepad++) Texstudio oder (für poweruser) jabref  verwendet werden.

\section{Einige tex Kommandos}\label{sec:texkommandos}
\markboth{Einige tex Kommands}{Einige tex Kommands} %für die kopfzeile

Auf eine Überschrift \ref{sec:texkommandos} kann so verwiesen werden. Unter jedem Kapitel und jeder Überschrift sollte zumindest ein Satz Text stehen.

\subsection{Unterüberschrift}
Je kleiner, desto mehr "`sub"'s kommen davor.

\subsection{Bilder und Quellen}

Auf ein Bild kann mit Abb. \ref{fig:textreferenz} verwiesen werden. Dies sollte immer passieren, bevor es im erscheint. Einige Beispielplots finden sich außerdem im Anhang.

%empfänger
\begin{figure}[h] %h(ere), t(op), b(ottom) stehen für den ort an dem das bild wenn möglich erscheint. ! und großschreibung sind strikter. bei htb wird zuerst das h beachtet, dann das t usw
\centering
 %Größe, Ort, am besten als vektorgraphik (pdf), Photos als jpg
\caption{Beschreibung (Quellen dahinter) \cite{BibDEMO1}\cite{BibDEMO2}}
\label{fig:textreferenz}
\end{figure}

Eine Quelle wird direkt hinter dem Satz vor dem Punkt angegeben mit \cite{BibDEMO1}, oder aber hinter einem kompletten Absatz. Auch Formeln (im Text) und Bilder (in der caption) müssen eine Quellenangabe enthalten.

Schöne Schaltpläne lassen sich auch direkt in Latex mi tikz/circuitikz malen, siehe \ref{tikz}.

\begin{figure}
	\centering
	\tikzsetnextfilename{XX_DEMO_tikz} %Dateiname, unter der die datei im ordner tikz-ext-out angelegt wird
	\tikzset{external/remake next} %uncomment to force remake figure
	\begin{tikzpicture}[scale=.8,transform shape]
	
	\draw  (0,0)coordinate[rground](start) to [vsourcesin,v<=$u_e$]++(0,3)to[R,l=$R_1$]++(4,0)coordinate[circ](knoten1)
			to [R,l=$R_3$]++(4,0) coordinate[circ](knoten2) --++(1,0) node[op amp,anchor=-](opv){};
			\draw (knoten1) to[C,l=$C_2$](knoten1|-start) coordinate[rground];
			\draw (knoten2) to[C,l=$C_1$]++(0,3) coordinate[circ](knoten3);
			\draw (knoten1) to[R,l=$R_2$]++(0,3)--(knoten3);
			\draw (opv.out)--++(1,0)|-(knoten3);
			\draw (opv.+)--++(-1,0)--++(0,-1)coordinate[rground];
			\draw (opv.out)++(1,0)to[short,*-o]++(1,0) coordinate(out);
			\draw  [->,shorten >=1ex,shorten <=1ex,thick] (out) -- (out|-start) node[left,midway] {\Large$u_a$};
			\draw (out|-start) coordinate[rground] coordinate[ocirc];
			
			\draw (knoten1) node[above left]{$\varphi_1$};
			\draw (knoten2) node[above left]{$\varphi_2$};
	\end{tikzpicture}
	\caption{Toller Schaltplan mit circuitikz (\url{https://github.com/lte-fau/circuitikz})}
	\label{tikz}
\end{figure}

\subsection{Formeln}

Auf Formeln kann mit \ref{eqn:tc} verwiesen werden. Konstanten und mathematische Funktionen (z.B. ln), sowie Einheiten sollten dabei nicht kursiv geschrieben werden. Zwischen einer Zahl und der Einheit ist ein halbes Leerzeichen mit 1,0\,\textmu V zu setzen. Das Komma ist bei der Zahl kein Punkt, die für Spannung steht das deutsche "`U"' und nicht "`V"'.

\begin{eqnarray}\label{eqn:tc}
X_{Strom}=\text{Konstante} \cdot 1,0\,\text{mV} \cdot \frac{1}{I} \cdot \frac{\partial I}{\partial T}
\end{eqnarray}

\subsection{Häufige Fehler}
Es sollten alle Dokumente im Format "utf8" gespeichert werden.

%Kommentare sind jederzeit mit einem %-Zeichen möglich

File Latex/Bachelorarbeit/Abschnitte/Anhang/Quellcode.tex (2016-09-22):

\section{Quellcode}
\label{app:Quellcode}
Im Folgenden sind die Main-Datei des Softwareentwurfs sowie die Interrupt Service Routinen dargestellt.
\subsection{Main.c}
\lstinputlisting[caption={Hauptdatei des Softwareentwurfs},label={listing:Main},captionpos=t,language=C]{../../Dave/Basisstation/Basisstation/Main.c}
\subsection{ISRs.c}
\lstinputlisting[caption={Interrupt Service Routinen des Softwareentwurfs},label={listing:ISR},captionpos=t,language=C]{../../Dave/Basisstation/Basisstation/ISRs.c}
%\subsection{Init.c}
%\lstinputlisting[caption={Initialisierung des Softwareentwurfs},label={listing:Init},captionpos=t,language=C]{../../Dave/Basisstation/Basisstation/Init.c}

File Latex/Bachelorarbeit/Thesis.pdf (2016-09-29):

## Lehrstuhl für Technische Elektronik

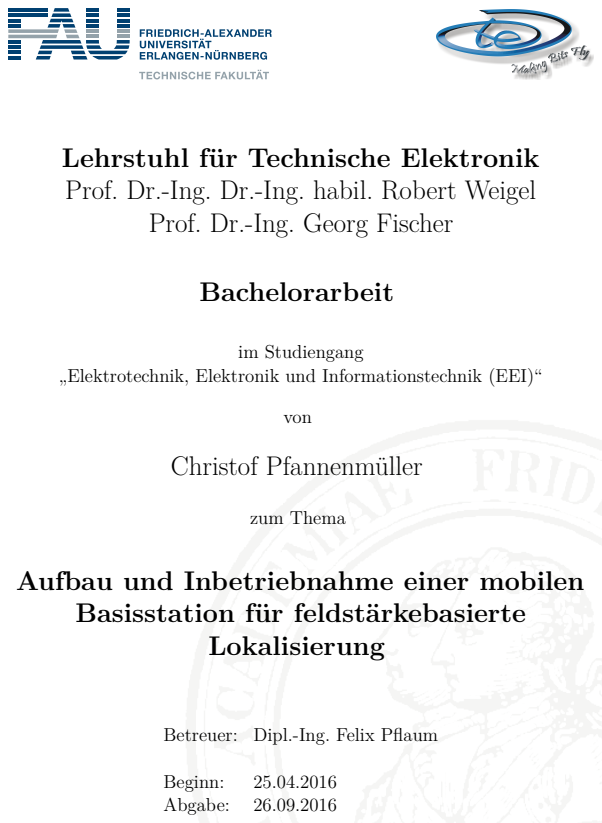
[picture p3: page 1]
Bachelorarbeit; im Studiengang; von; Christof Pfannenmüller; zum Thema; Lokalisierung; Beginn:; Abgabe:

Prof. Dr.-Ing. Dr.-Ing. habil. Robert Weigel

Prof. Dr.-Ing. Georg Fischer

„Elektrotechnik, Elektronik und Informationstechnik (EEI)“

Aufbau und Inbetriebnahme einer mobilen
Basisstation für feldstärkebasierte

Betreuer: Dipl.-Ing. Felix Pflaum

# Erklärung

Ich versichere, dass ich die Arbeit ohne fremde Hilfe und ohne Benutzung anderer als der angegebenen Quellen angefertigt habe und dass die Arbeit in gleicher oder ähnlicher Form noch keiner anderen Prüfungsbehörde vorgelegen hat und von dieser als Teil einer Prüfungsleistung angenommen wurde.

Alle Ausführungen, die wörtlich oder sinngemäß übernommen wurden, sind als solche gekennzeichnet.

Erlangen, den 26. September 2016

Christof Pfannenmüller

iii

# Kurzfassung

Ziel der vorliegenden Arbeit war der Aufbau einer Basisstation mit sechs unabhängigen Transceivern. Der Einsatz dieses Aufbaus diente der späteren Lokalisierung von Sensoren oder anderen Sendern im Sub-GHz-Frequenzbereich um 868 MHz. Die relative Ortsbestimmung zur Basis sollte energieeffizient sein und gleichzeitig eine hohe Auflösung bieten.
Die genaue Position des Senders wurde dazu auf Basis der unterschiedlichen Feldstärken an den Transceivern eruiert. Ausgenutzt wurde dabei, dass typische integrierte Transceiver die Empfangsfeldstärke selbst auswerten und bereitstellen, sodass diese ausgelesen werden kann. Das Erkennen von Übertragungen und das anschließende Auslesen der anfallenden Daten wurde dabei von einem Mikrocontroller übernommen. Zur weiteren Verarbeitung der Daten sollten diese anschließend einem Computer zur Verfügung gestellt werden. Dazu wurde sowohl eine USB- als auch eine Netzwerk-Schnittstelle vorgesehen. Die beim Aufbau der Platine verwendete Hardware basierte zum Großteil auf Bauteilen des Herstellers Infineon. Beim Layout der Platine wurden die sechs Transceiver sternförmig und regelmäßig um den Mikrocontroller und dessen Peripherie angeordnet, um ein gleichmäßiges Empfangsverhalten aus allen Raumrichtungen zu gewährleisten. Die Funksegmente der Platine wurden so gestaltet, dass diese bei Bedarf abgetrennt und mit einer Kabelverbindung weiter voneinander entfernt werden konnten. Antennen zum Senden wurden über Steckverbinder an die Basisstation angeschlossen.
Der anschließende Softwareentwurf für die Basisstation nutzte zu einem Großteil bereits bestehende Bibliotheken und hatte zur Aufgabe, ankommende Übertragungen zu erkennen, die zur Ortung notwendigen gemessenen Werte abzufragen und an den Hostcomputer weiterzuleiten.

v

# Abstract

Current localization measurements by magnitude and phase of electromagnetic waves have been complex and consume plenty of energy. However, almost every receiver has knowledge of the electrical field strength, correlating to distance from transmitter, this information is nearly unused. A multi transceiver base station should start communication with a mobile wireless sensor. The relative positioning to the base could be calculated by the received signal strength (RSSI) already provided from transceivers without additional components. Due to the permeability of walls, the possible range and the wavelength, associated to resolution of localization, Sub-GHz frequency range is used. Therefore six identical transceiver-ICs were arranged over all horizontal directions in space. By detachable design of the transceiver-modules a rearranging of the antennas was made feasible to provide different distances for best resolution of localization. The ICs were controlled by a XMC4500 microcontroller connected to the transceivers with SPI and IRQ line for finished transmission. Distribution of received data and signal strength measurements to a host computer is accomplished by the XMC4500 over Ethernet and USB.

vii

# Abkürzungsverzeichnis

PCB | Printed Circuit Board | 3
EDA | Electronic Design Automation | 3
CAD | Computer-aided design | 3
SMD | Surface-mounted device | 4
SPI | Serial Peripheral Interface | 5
DRC | Design-Rule-Check | 5
FIFO | First In – First Out | 6
NCS | Non-Chip-Select | 6
IC | Integrierter Schaltkreis (integrated circuit) | 7
SMA | Sub-Miniature-A | 7
LQFP Low Profile Quad Flat Package | 10
BGA Ball Grid Array | 10
JTAG Joint Test Action Group | 10
TVS | Transient Voltage Suppressor | 11
LDO | Low Drop-Out | 13
SOT | Small Outline Transistor | 13
STEP | Standard for the Exchange of Product Model Data | 15
NC | Numerical Control | 16
IDE | Integrated Development Environment | 17
GUI | Graphical User Interface | 17
SDK | Software development kit | 17
CPU | Central Processing Unit | 18
ETH | Ethernet MAC (Ethernet Medium Access Control) | 18
USB | Universal Serial Bus | 18
GPIO | General Purpose Input/Output | 18
USIC | Universal Serial Interface Channel | 19
| ix

Bachelorarbeit

ISR | Interrupt Service Routine | 20
ERU | Event Request Unit | 20
ERS | Event Request Select | 20
ETL | Event Trigger Logic | 20
OGU | Output Gating Unit | 20
NVIC | Nested Vectored Interrupt Controller | 20
CMSIS Cortex Microcontroller Software Interface Standard | 21
GND | Masse (Ground) | 22
MISO | Master-In Slave-Out | 22
MOSI | Master-Out Slave-In | 22
ASCII American Standard Code for Information Interchange | 23
IRQ | Interrupt Request | 24
PLL | Phasenregelschleife (phase-locked loop) | 25
AGC | Automatic Gain Control | 26
RSSI | Received Signal Strength Indication | 27

x

# Inhaltsverzeichnis

1 Einleitung | 1
2 Platinenaufbau | 3
3 Software | 17

xi

4 Feldtest | 31
5 Zusammenfassung und Ausblick | 35
Abbildungsverzeichnis | 37
Tabellenverzeichnis | 39
Quellcodeverzeichnis | 41
6 Anhang | 43

## Kapitel 1

# Einleitung

## 1.1 Motivation

Die Lokalisierung von Objekten bildet in der Sicherheits- und Automatisierungstechnik eine immer größere Basisdisziplin. Sie ist daher seit Anbeginn des Informationszeitalters eine zentrale Aufgabe der Elektronik. Im Zeitalter von Industrie 4.0 und allgegenwärtigen autonomen Systemen wird die Ortung von Objekten unersetzlich und gewinnt weiter an Bedeutung.
Bisherige Ansätze zur elektronischen Ortsbestimmung sind meist aufwändig, mit einem hohen Energieverbrauch verbunden und benötigen viele Teilkomponenten. Dies macht die elektronische Ortsbestimmung teuer, was sich vor allem im Betrieb von Systemen wie GPS oder Galileo zeigt. Daneben haben diese Systeme vor allem den Nachteil, dass die verwendeten Frequenzen Wände kaum durchdringen und somit innerhalb von Gebäuden nicht verwendet werden können. Genau dieses Anwendungsszenario stellt jedoch in der Industrie 4.0 eine typische Fabrik dar. Dies führt dazu, dass für das am häufigsten verwendete Beispiel, einen autonom agierenden Roboter in einer Lagerhalle, andere Techniken zur Ortsbestimmung eingesetzt werden müssen.
Ortungsansätze für ein solches autonomes bewegliches System existieren bereits und werden, wie bei der WLAN-basierten Ortung, auch eingesetzt. Diese Systeme haben jedoch den Nachteil, dass sie viele Sender mit bekanntem Ort benötigen. Dies erfordert eine aufwändige Kalibrierung des Systems und führt vor allem zu einem großen Energieverbrauch des Gesamtsystems, da alle stationären Einheiten dauerhaft senden müssen, um eine Ortung zu ermöglichen. Ein weiterer Nachteil der Systeme ist, dass nur der zu ortende Client die Informationen über seinen Standort hat. Für ein außenstehendes System, wie den steuernden Hauptrechner einer Industrieanlage, ist nicht festzustellen, wo das Objekt sich befindet. Durch diese Probleme ließe sich das Anwendungsszenario eines einzelnen autarken Funksensors, dessen Messwert vom Hauptrechner abgefragt wird, nur schwer realisieren. Der Sensor müsste über eine große Energiereserve verfügen und ständig aktiv sein, um zu erkennen, dass er aufgefordert wird, seine Position zu ermitteln und mitzuteilen.

1 Einleitung | Bachelorarbeit

Durch das Verlagern der Ortungsaufgabe auf das stationäre System müsste der Sensor nur beim Vorliegen eines neuen Messwertes eine Funkverbindung aufbauen. Die Basisstation könnte aus dem empfangenen Signal sowohl den Messwert extrahieren als auch eine Lokalisierung durchführen. Sollte der stationäre Teil aus nur einer Einheit bestehen, wäre auch eine Änderung am Gesamtsystem, wie eine Ortsänderung der stationären Einheit, einfach möglich, da nur die relative Position zu dieser ermittelt wird, weshalb eine Neukalibrierung des Systems entfällt. Der Sensor selbst benötigt im Normalfall keine Information über seinen Aufenthaltsort. Dies erlaubt eine mobile Ortung, da die Basis unkompliziert bewegt werden kann.
Es bietet sich hierfür eine Nutzung des Sub-GHz-Frequenzbandes an, welches deutlich weniger belegt ist, in dem meist nur kurze Funkdauern verwendet werden und in welchem eine Übertragung vor allem energieeffizienter möglich ist [1]. Ein weiterer Vorteil des verwendeten Frequenzbandes sind die besseren Penetrationseigenschaften durch Wände und Personen im Vergleich zu Ansätzen, die etwa auf WLAN basieren.

## 1.2 Zieldefinition

Zum Umsetzen einer solchen oben beschriebenen Ortung sollte eine Basisstation aufgebaut werden, welche als stationäre Einheit einen Sender orten könnte. Die Aufgabenstellung dieser Bachelorarbeit bestand im Einarbeiten in den vorgegeben Transceiver TDA5340 und den Mikrocontroller XMC4500. Bei der Gestaltung des Layouts für die Platine mit Altium Designer wurden diese über einen SPI-Bus verbunden. Die Platine sollte zusätzlich ein Konzept zur Bereitstellung der Versorgungsspannung enthalten. Um die Weiterverarbeitung der bezogenen Messwerte sicherzustellen, war eine LAN-Schnittstelle sowie eine Möglichkeit für einen USB-Anschluss zu einem PC zu integrieren.
Das ursprünglich geplante Design von PCB-Antennen an den Transceivern auf der Platine wurde wegen des Umfangs der dazu notwendigen Simulationen zu Beginn aus der Aufgabenstellung entfernt. Stattdessen wurden zugekaufte Antennen mit der Basisstation verwendet, welche über Steckverbinder angeschlossen wurden.
Eine funktionierende Firmware für das Initialisieren und Betreiben der Basisstation war ebenfalls mit der dazu notwendigen Entwicklungsumgebung zu erstellen. Dabei musste der Mikrocontroller auf, vom Transceiver ausgelöste, Interrupts für ankommende Übertragungen reagieren und Messwerte erfassen. Beides wurde anschließend entsprechend weitergeleitet. Durch die Verwendung von Makros beim Softwareentwurf sollte eine spätere Anpassung, wie das Tauschen von Pins, leichter möglich sein.

## 1.3 Projektmanagement

Die vorliegende Arbeit wurde innerhalb von fünf Monaten am Lehrstuhl für Technische Elektronik der Universität Erlangen-Nürnberg angefertigt. Dabei lag der Fokus in den ersten beiden Monaten auf dem Layout der Platine und dem anschließenden Bestücken. In der folgenden Zeit wurde vermehrt auf die Software für den Betrieb der Basisstation eingegangen. Außerdem wurde in den letzten zwei Monaten die Dokumentation mit Latex erstellt. Als Versionskontrolle für das gesamte Projekt wurde Github eingesetzt.

## Kapitel 2

# Platinenaufbau

## 2.1 Vorüberlegungen

Die Zielsetzung im Aufbau der Platine war eine kompakte Basisstation mit sechs Transceivern und einer zentralen Steuereinheit. Um sicherzustellen, dass alle Antennen gleichmäßig in die sechs vorgegebenen Raumrichtungen abstrahlen, sollte bereits die Platine symmetrisch aufgebaut werden. Dazu wurde zuerst das Layout der sechs identischen Transceiver-Einheiten mit dem TDA5340-Baustein und den Antennenanschlüssen erstellt und anschließend gleichmäßig um die weiteren für die Schaltung notwendigen funktionellen Segmente angeordnet.

## 2.2 Layoutprogramm Altium Designer

Bei dem Entwicklungswerkzeug „Altium Designer“ des Entwicklers Altium Limited handelt es sich um ein System zum Entwurf von gedruckten Schaltungen oder Printed Circuit Boards (PCBs). Ein solches Programm wird auch als Electronic Design Automation (EDA) oder ECAD für electronic Computer-aided design (CAD) bezeichnet, da es den Entwickler bei der Umsetzung der Anforderungen in einen Schaltplan und später eine Platine unterstützen soll. Wie viele andere EDA-Programme ist auch Altium Designer so aufgebaut, dass sich der Entwickler zuerst mit dem allgemeinen symbolisierten Schaltplan befassen kann und erst zu einem späteren Zeitpunkt die tatsächliche Anordnung der Bauteile auf dem PCB-Substrat festgelegt wird. Somit können zuerst im Schematic Editor die Funktionen der Schaltung umgesetzt werden. Dazu werden die verwendeten Bauteile aus zuvor angelegten Bibliotheken verwendet oder es werden bestehende Libraries genutzt, die etwa vom Hersteller der Bauteile zur Verfügung gestellt werden. Altium selbst bietet hierfür auch diverse Möglichkeiten an und stellt Bauteile nach Hersteller und Art geordnet bereit. In den Bibliotheken sind alle im weiteren Verlauf benötigten Informationen über die einzelnen Bauteile enthalten. So liegen dort etwa entsprechende Abbildungen für das Bauteil im Schaltplan vor. In den so genannten „Footprints“ zu jedem Bauteil, welche ebenfalls in den Bibliotheken enthalten sind, wurden zuvor die für das physikalische

2 Platinenaufbau | Bachelorarbeit

Gehäuse notwendigen Abmessungen, Lötpads und Ausmaße für Lötstopplack um das Bauteil festgelegt. Da es Bauteile, wie den verwendeten Mikrocontroller in verschiedenen Gehäusen geben kann, besteht somit auch die Möglichkeit, hier zwischen verschiedenen Footprints zu wählen. Da viele Gehäuse herstellerübergreifend genormt sind, konnten teilweise bestehende Footprints genutzt oder diese mehrfach verwendet werden.
Wie bereits erwähnt wird im EDA-Programm zuerst der symbolische Schaltplan erstellt. Dieser wird anschließend in ein Layout für eine Platine umgewandelt. Die zu den Schaltplansymbolen korrespondierenden Footprints werden dazu auf dem Layout der Platine angeordnet und durch das „Routing“ werden die Leiterbahnen definiert. Altium Designer ist dabei in drei Teilbereiche unterteilt: Im „Board Planning Mode“ liegt der Fokus auf dem Anordnen der einzelnen Bauteile und Komponenten auf der Leiterplatte, außerdem wird in diesem Bereich die Form und das Ausmaß der Leiterplatte festgelegt. Im 2D-Modus des PCB-Editor lassen sich anschließend die aus der Definition im Schaltplan ergebenden elektrischen Verbindungen örtlich auf den verschiedenen Kupferebenen (Layern) anordnen. Die Hauptarbeit findet also in diesem Teil des PCB-Editors statt. Der 3D-Modus dient anschließend zur Evaluation des Designs und zur Anpassung an Gehäuse oder andere Komponenten. In den verschiedenen Ebenen oder „Layern“ sind die Kupferebenen und andere Schichten der späteren Platine wie der Bestückungsdruck oder der Lötstopplack gesammelt. Jede Ebene entspricht daher einer zu fertigenden Schicht und existiert für die Vorder- und Rückseite der Platine. Beim Bewegen eines Bauteils wird nicht nur die markierte Abmessung, sondern etwa auch die Anschluss-Pads und der Lötstopplack der Komponente auf den entsprechenden Ebenen bewegt. Durch Vias sind elektrische Verbindungen zwischen den Kupferschichten möglich.
Für die Basisstation wurden zwei Kupferebenen und ausschließlich sogenannte Surface-mounted device (SMD)-Bauelemente verwendet. Diese liegen nur auf der Oberfläche der Platine auf und sind durch ihre Lötverbindungen befestigt. Die Vorteile dieser Bauteile sind der geringe Preis und die kleinen Abmessungen.
Wegen der Größe des Projekts wurde zur besseren Übersicht ein so genanntes „Multi-Sheet-Design“ erstellt. Dadurch war es möglich, die verschiedenen funktionellen Blöcke der Basisstation auf getrennte Blätter des Schaltplans zu verteilen. Der Mikrocontroller, die Spannungsversorgung und der Transceiver sowie die für eine Netzwerkkommunikation notwendigen Bauteile wurden dabei auf unabhängigen Seiten angeordnet und dort die elektrischen Verbindungen erstellt.
Da der Transceiver und die entsprechende Peripherie sechsmal in identischer Anordnung und Beschaltung verwendet wurden und auch auf dem PCB-Substrat mehrfach mit Leiterbahnen verbunden und angeordnet werden mussten, wurde hierfür ein so genanntes „Multi-Channel“-Design gewählt. In Altium Designer können mit diesem Feature identische Schaltungsteile einmal angeordnet, mit Leiterbahnen verbunden und dieses Design auf alle anderen entsprechenden Schaltungsteile angewendet werden. Somit muss das aufwändige Anordnen der Bauteile und die Führung der Leiterbahnen nur bei einem der Kanäle durchgeführt werden. Dazu wurde mit Hilfe eines übergeordneten Sheet-Symbols der Schaltplan des Transceivers in den Schaltplan des Mikrocontrollers eingefügt und diesem somit untergeordnet. Über Ports, welche zum Schaltplansymbol hinzugefügt werden, lassen sich elektrische Verbindungen zwischen Netzen innerhalb der Schaltpläne für Transceiver und Mikrocontroller erstellen. Dabei wird im Transceiver-Schaltplan ein Port

Bachelorarbeit | 2.2 Layoutprogramm Altium Designer

hinzugefügt, der mit dem gewünschten elektrischen Netz verbunden werden kann. Auf dem Schaltplansymbol im Mikrocontroller-Schaltplan wird ein entsprechender gleichnamiger Port erstellt, der mit Netzen am Mikrocontroller verbunden werden kann. Da die drei Verbindungen der Serial Peripheral Interface (SPI)-Kommunikation jeweils aus einem Netz bestehen und etwa alle MISO-Leitungen an demselben Pin des XMC4500 und demselben Anschluss bei allen TDAs angebunden sind, konnte hierfür ein einfacher Port verwendet werden. Alle anderen Anschlüsse, wie etwa die Auswahlleitung für das SPI-Interface, welche für jede der sechs verschiedenen Transceiver-Einheiten mit einem anderen Anschluss des Mikrocontrollers verbunden sein musste, wurden deswegen mit dem Repeat-Kommando erstellt. So wird im untergeordneten Schaltplan, in diesem Fall dem des TDA, der Port beliebig benannt, etwa als „NCS“. Der auf dem Schaltplansymbol erstellte korrespondierende Port wird dagegen in „Repeat(NCS)“ umbenannt. Eine Verbindung mit dem Port auf dem Schaltplansymbol wird dadurch zu einem Bus. Dieser kann aufgetrennt werden und die Verbindungen von jedem Kanal als einzelnes Signal an den Mikrocontroller angeschlossen werden. Globale Netze wie die Versorgungsspannung von 3,3 Volt oder die Masse müssen dabei nicht als Port hinzugefügt werden. Altium Designer stellt deren Verbindungen automatisch her.
Wird nun noch der Name des Schaltplansymbols nach dem folgenden Muster angepasst, wird Altium Designer beim Kompilieren des Projektes ein Multi-Channel-Design erstellen, die Kanäle wie angegeben durchnummerieren und den Kanal im PCB-Editor entsprechend mehrfach erstellen. Dazu sollte der Name die Struktur „Repeat(<Name>,<Startnummer> ,<Endnummer>)“ aufweisen. Anschließend kann die Anordnung und das Routing des ersten Kanals erfolgen. Da für jeden Kanal ein eigener so genannter „Room“ erstellt wird, lassen sich, nach dem Erstellen der Leiterbahnen des ersten Kanals, die Anordnungen der Bauteile und Leiterbahnen mit dem „Copy Room Format“-Befehl auf alle anderen Kanäle erweitern. Ein Room bezeichnet dabei eine Gruppe an Elementen im PCB-Editor und einen Bereich der Platine, in dem diese angeordnet sind und erlaubt so das Verschieben ganzer Schaltungsteile auf der Platine. Der Schaltplan des Hauptkanals, welcher einen einzelnen der sechs Kanal darstellt, ist in Abbildung 2.1 zu erkennen.
Altium Designer nummeriert automatisch die verwendeten Bauelemente durch, um die genaue Identifikation eines Bauteiles zu erlauben und erstellt automatisch einen Aufdruck neben dem Lötpad mit dem Bauteilnamen in der entsprechenden Ebene. Ein solcher Bestückungsdruck zur leichteren Anordnung der Bauteile auf der fertig entwickelten Platine wurde nur auf der Hauptplatine erstellt. Auf den Teilplatinen für die Transceiver wurde dieser aus Platzgründen weggelassen.
Um sicherzustellen, dass die sich aus der Bauteilanordnung ergebenden Pads und die Leiterbahnen auch fertigbar sind, stellt Altium Designer zwei Design-Rule-Checks (DRCs) bereit. Im ersten Live-DRC werden „Violations“, also Bauteile mit Verstößen gegen die Designregeln, durch ein farbiges Overlay markiert. Im folgenden kompletten Test zeigt Altium alle weiteren Verstöße an. Als Verstoß gelten etwa Leiterbahnen unterschiedlicher Netze, die sich berühren und zu einem Kurzschluss führen würden oder auch Verletzungen der festgelegten Abstandsregeln (Clearance). Alle Regeln für Violations können im „PCB Rules Editor“ eingestellt werden und so an die Möglichkeiten des PCB-Herstellers angepasst werden. Da die Leiterplatte für die Basisstation von Multi Circuit Boards Ltd. hergestellt wurde, konnten die auf der Webseite dieses Herstellers angegebenen Designre-

2 Platinenaufbau | Bachelorarbeit

geln für den DRC übernommen werden. Da bei Altium Designer im DRC kurzgeschlossene und falsch verbundene Leitungen oder Pads angezeigt werden, muss kein extra „Layout vs. Schematic“-Test durchgeführt werden, der den vorher erstellten Schaltplan mit dem Layout abgleicht. Unterschiede zwischen Schaltplan und dem PCB-Layout würden durch den DRC bereits angezeigt.

## 2.3 Verwendete Hardware

### 2.3.1 TDA5340

Der verwendete Transceiver TDA5340 wird von Infineon Technologies AG entwickelt und vertrieben. Er ist Teil der SmartLEWIS Produktfamilie, die energiesparende Lösungen für Funkanwendungen im Frequenzspektrum unterhalb von einem Gigahertz bietet. Der Transceiver kommuniziert mit seinem Host über das SPI-Protokoll, der Mikrocontroller ist in diesem Fall sternförmig mit den einzelnen TDA-Bausteinen verbunden, die als Slaves fungieren. Die Daten werden mit drei gemeinsamen Leitungen übertragen, eine vierte Leitung dient dem XMC zur Auswahl des gewünschten Slaves für die Kommunikation. Diese Non-Chip-Select (NCS)-Leitung arbeitet active-low, sodass der jeweilige TDA5340 eine Interaktion akzeptiert, sobald diese vom XMC-Baustein auf Massepotential gezogen wird. Von den drei eigentlichen Datenleitungen fungiert eine als reiner Ausgang des Masters bzw. Dateneingang des TDA (MOSI), eine zweite als Eingang des Masters (MISO) und die dritte als ein vom Mikrocontroller getriebenes Clock-Signal. Bei dem auf MISO und MOSI anliegenden Signal handelt es sich um ein unipolar kodiertes non-return-to-zero Signal, welches einer logischen 0 bei Massepotential entspricht. Der TDA unterstützt acht verschiedene Instruktionen, die es erlauben einzelne Register des Bausteins zu lesen bzw. zu schreiben, auf mehrere hintereinander folgende Register zuzugreifen oder auf die beiden Puffer des Bausteins zuzugreifen. In den beiden Puffern, die als First In – First Out (FIFO)-Strukturen aufgebaut sind, werden die vom TDA erkannten und demodulierten bzw. die auf Übertragung wartenden Signalpakete zwischengespeichert. Diese Zwischenspeicherung soll den Mikrocontroller entlasten, so können entsprechende Datenpakete dem TDA5340 mitgeteilt werden und dieser übernimmt selbsttätig eine korrekte Modulation und Übertragung mit den eingestellten Parametern.
Der TDA5340 kann sowohl mit einer Versorgungsspannung von 5 V als auch bei 3,3 V arbeiten. Da aber der XMC nur bei letzterer betrieben werden kann, wurde der TDA-Baustein und die externe Beschaltung ebenfalls auf 3,3 V ausgelegt.
Um zu einem späterem Zeitpunkt eine größere Entfernung zwischen den einzelnen Antennen und somit auch den jeweiligen Transceivern zu erlauben, wurde eine Sollbruchstelle vorgesehen. Dadurch könnte die gesamte Baugruppe von der Mutterplatine entfernt werden, was unter Umständen notwendig gewesen wäre, um die Auswirkungen verschiedener Antennenabstände an der Basis zu evaluieren und somit eine bessere Auflösung in der Ortung zu erlauben. Dazu wurden Anschlussleisten im Rastermaß 2,54 mm an beiden Seiten der Sollbruchstelle vorgesehen. Die Verbindung der Transceiver-Einheiten mit der Hauptplatine wurde über diese Sollbruchstelle hinweg mit Leiterbahnen gewährleistet. Nach dem Abtrennen der TDA-Teilplatine an der durch Bohrungen vorgesehenen Bruchstelle wäre die elektrische Verbindung durch Kabel sichergestellt worden. Da es

Bachelorarbeit | 2.3 Verwendete Hardware

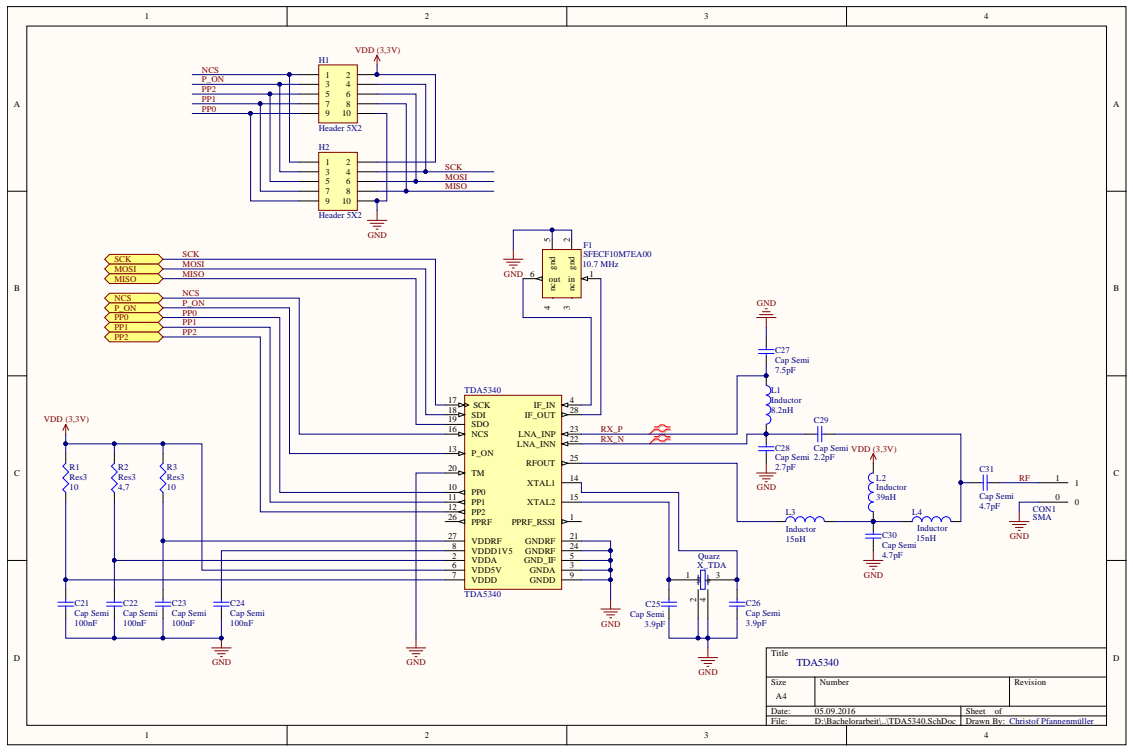
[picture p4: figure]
Title; Size; Number; Revision; Date:; Sheet of; File:; D:\Bachelorarbeit\..\TDA5340.SchDoc; Drawn By:; PPRF_RSSI; VDDA 2; GNDA; GND_IF; VDD5V 6 VDDD 7; VDDD1V5 8; GNDD; XTAL1; XTAL2; NCS 16; SCK 17 SDI 18 SDO 19; GNDRF; LNA_INN; 22 LNA_INP; RFOUT; PPRF 26; VDDRF 27; IF_OUT; TDA5340; C21 Cap Semi; C22 Cap Semi; C23 Cap Semi; C24 Cap Semi; R1 Res3; R2 Res3; R3 Res3; GND; VDD (3,3V); C25 Cap Semi; C26 Cap Semi; 1 out 6; gnd 2; gnd 5; 10.7 MHz; F1 SFECF10M7EA00; 4 4 X_TDA; Quarz; CON1 SMA; C27 Cap Semi; Cap Semi; C28 Cap Semi; L1 Inductor; L2 Inductor; Inductor; C30 Cap Semi; NCS; MISO; MOSI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

Abb. 2.1: Schaltplan der Transceiverbaugruppe

sich bei den zu übertragenden ausschließlich um digitale Signale geringerer Frequenzen im Bereich unter 1 MHz handelt, hätte dies unproblematisch mit ungeschirmten Flachbandkabeln realisiert werden können. Neben der Versorgungsspannung, der Masse und den vier für die SPI-Kommunikation notwendigen Signalen wurden noch die drei multifunktionalen Digitalausgänge und der Power-On Reset-Pin (P_ON) dem XMC4500 über die Buchsenleisten zur Verfügung gestellt.
Der TDA5340 ist ein Integrierter Schaltkreis (IC) der über drei multifunktionale Digitalausgänge PP0, PP1 und PP2 verfügt. Diese können durch entsprechende Kalibrierung von Registern mit verschiedenen Signalen belegt werden. So ist es etwa möglich mit diesen einen externen Antennenumschalter zu steuern oder andere Signale wie ein Clocksignal auszugeben. PP2 wird vom TDA standardmäßig als Interrupt Signal verwendet. Die nicht verwendeten PP1 und PP0 wurden bei der späteren Konfiguration in den hochohmigen Zustand geschaltet. Durch einen am P_ON-Pin anliegenden High-Pegel wechselt der Transceiver in den eingeschalteten Zustand. Anderenfalls ist dieser ausgeschaltet und verbraucht typischerweise weniger als 1 µA.
Die Antenne wurde am oberen Ende jeder TDA5340-Teilplatine vorgesehen. Als Anschluss für die Antenne wurde hier eine Koaxialbuchse in Sub-Miniature-A (SMA)-Ausführung verwendet, welche auf 50 Ω angepasst ist. Durch den Koaxialsteckverbinder konnte sichergestellt werden, dass alle notwendigen Frequenzen auch korrekt und ungedämpft passieren können. Das Anpassnetzwerk zwischen dem integrierten Transceiver und der verwendeten SMA-Buchse diente der Leistungsanpassung zwischen den Pins

2 Platinenaufbau | Bachelorarbeit

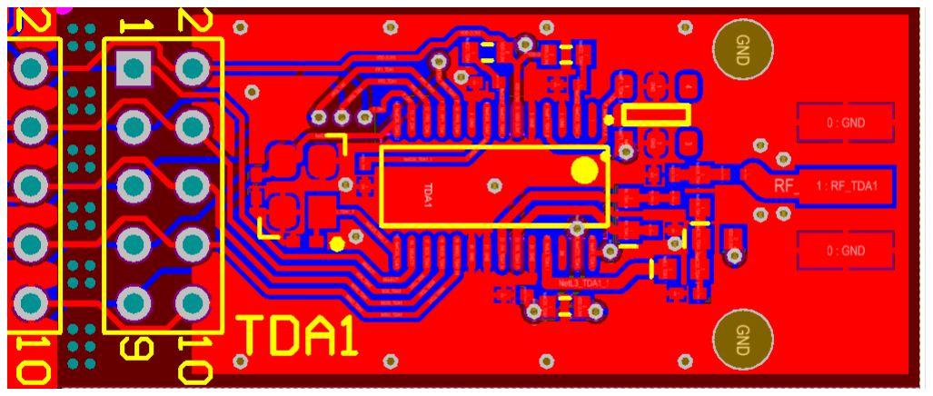
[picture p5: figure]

Abb. 2.2: Layout des Transceivers mit der Sollbruchstelle und der Steckerleiste (links) sowie dem Anpassnetzwerk. Die Lötflächen für die SMA-Buchse sind auf der rechten Seite erkennbar

des TDA5340 und der 50-Ω-Koaxialbuchse. Der Aufbau des Anpassnetzwerkes basiert auf einem von Stefan Erhard erstellten Schaltplan für eine Aufsteckplatine für das Evaluationsboard „XMC 2Go“ von Infineon. Das entsprechende Layout ist im Anhang 6.4 abgebildet. Durch die Verwendung von hoch abgestimmten Spulen und Kondensatoren mit Toleranzen von nur ±0,05 pF bei einem Nennwert von 2,5 pF wurde die korrekte Anpassung sichergestellt.
Zur Verbesserung der Hochfrequenzeigenschaften wurden die Freiräume zwischen den Leiterbahnen mit einer Kupferfläche gefüllt, die mit dem Masseanschluss verbunden war. Durch die Verwendung von Vias, vor allem im Bereich des Anpassnetzwerkes, sollte eine niederohmige Verbindung zwischen den beiden Masseflächen auf der Ober- bzw. Unterseite der Platine erreicht werden. Daneben dienten diese auf Nullpotential liegenden Vias jedoch vor allem der Abschirmung der Pfade für die HF-Signale gegen mögliche Einkoppelungen aus der Umgebung, welche ankommende Funksignale stören könnten. Obwohl der TDA5340 einen eingebauten Zwischenfrequenz-Filter hat, der über eine umschaltbare Bandbreite verfügt, wurde ein externer Keramikfilter verwendet. Der TDA stellt dafür zwei Pins bereit, zwischen denen ein solcher Filter mit einer Frequenz von 10,7 MHz angeschlossen werden kann. Ohne einen hier extern angeschlossenen Filter würde der TDA als einfacher heterodyner Mischer direkt auf die Zwischenfrequenz fIF2 = 274 kHz heruntermischen. Bei Verwendung eines externen Keramik- oder auch eines LC-π-Filters kann das ankommende HF-Signal jedoch in zwei Stufen gefiltert werden, ehe es in das Basisband demoduliert wird, was zu einer höheren Signalqualität führt. Die Umstellung zwischen einfacher und Double Down Conversion erfolgt durch das Setzen eines dafür vorgesehenen Bits [2][3].
Die elektrischen Verbindungen zwischen den beiden symmetrischen Eingängen des Low Noise Amplifier und dem Anpassnetzwerk wurden mit dem „Differential Pair Routing“-Feature von Altium Designer erstellt. Durch einen im Schaltplan auf die positive und negative elektrische Leitung zwischen dem TDA5340 und dem Anpassnetzwerk angewendeten Parameter wird das Leitungspaar als differentiell markiert. Anschließend kann mit dem interaktiven „Diffential Pair Routing“ einer der beiden Leitungen begonnen werden. Altium Designer wird dabei selbstständig versuchen, die zweite Leiterbahn des Paares so anzuordnen, das die beiden Leiterbahnen symmetrisch und parallel zueinander liegen,

Bachelorarbeit | 2.3 Verwendete Hardware

sodass Störeinflüsse möglichst gleichmäßig auf die beiden Leitungen einwirken. So sollen Störungen besser toleriert und durch die symmetrische Signalübertragung insgesamt ausgeglichen werden können [4]. Durch die Verwendung des „Diffential Pair Routing“ versucht Altium Designer auch die Länge der beiden Verbindungen anzugleichen. Durch die Anpassungen der differentiellen Leiterbahnen wird eine korrekte Übertragung durch gleiche Signallaufzeiten sichergestellt. Da diese Leitungen hochfrequente Signale führen, ist eine genaue Anpassung notwendig.
Um Einkopplungen auf die Pfade für hochfrequente Signale zu vermeiden, wurde das für den Transceiver benötigte Quarz möglichst weit vom Sende- bzw. von den Empfangsanschlüssen des TDA angeordnet. Aus diesem Grund wurde der für den Oszillator benötigte Quarz mit einer Frequenz fCrystal = 21,948717 MHz zwischen dem IC und der vorgesehenen Stiftleiste platziert. Die Frequenz des benötigten Quarzes ergibt sich aus dem Zusammenhang

fCrystal = fIF2 · 80 =

fIF1
39
- 80 =

10,7 MHz
39
- 80 = 21,948717 MHz , (2.1)

wobei die Zwischenfrequenz der ersten Stufe (fIF1) durch die internen funktionalen Blöcke des TDA und den Keramikfilter vorgegeben ist. Die weiteren Faktoren ergeben sich aus dem Aufbau des Empfängers und werden von Infineon bereitgestellt [3].

### 2.3.2 XMC4500

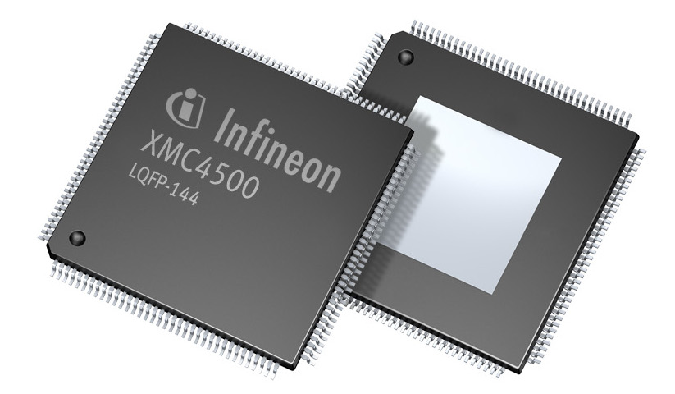
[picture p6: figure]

Abb. 2.3: Der XMC4500 Mikrocontroller von Infineon im LQFP-Gehäuse mit 144 Pins [5]

Die Hauptsteuerung der Basisstation übernimmt ein Mikrocontroller der Bauart XMC4500, welcher aus der Mikrocontroller-Familie XMC4000 von Infineon stammt. Diese Baureihe stellt energieeffiziente ICs bereit, welche für industrielle Steuerungen und „Sense & Control“ optimiert sind. Der XMC4500 basiert auf einem Cortex-M4 Kern des britischen Herstellers ARM. Daneben arbeitet der Mikrocontroller mit der von Infineon selbst entwickelten Entwicklungsumgebung DAVE zusammen. Im speziellen Anwendungsfall kommt die Variante des XMC mit 144 Pins und einem Flash-Speicher

2 Platinenaufbau | Bachelorarbeit

von 1024 Kilobit zum Einsatz. Der Chip ist dabei in einem Low Profile Quad Flat Package (LQFP)-Gehäuse verbaut. Durch die Wahl dieses Gehäuses konnte die elektrische Verbindung mit der Platine relativ leicht durch Löten erreicht werden. Im Gegensatz zum ebenfalls erhältlichen Ball Grid Array (BGA)-Gehäuse des XMC sind in diesem alle Kontakte direkt erreichbar und können leicht verlötet werden. Da beim BGA-Gehäuse die Anschlüsse auch in der Mitte unter dem Gehäuse sind, wäre hier ein Layout komplizierter und würde möglicherweise einen genaueren und somit teureren Prozess für die Herstellung der Platine fordern. Ein händisches Nachlöten von Kontakten oder Prüfen der Lötverbindung wäre ebenfalls nicht möglich.

Bei der Auswahl von Pins des XMC zur Verbindung mit den Transceivern wurde vor allem auf die Auswahl für die PP2 Pins geachtet. Um eine spätere Interruptsteuerung möglich zu machen, wurden hierfür nur solche Eingänge des Mikrocontrollers gewählt, die im Datenblatt mit der Möglichkeit zum Erkennen von Interrupts gekennzeichnet sind. Die Zuordnung der Transceiverausgänge an die Pins des Mikrocontrollers sind in Abbildung 2.4 erkennbar und in Tabelle 3.3 auf Seite 26 aufgeführt. Tabelle 3.1 der Seite 20 zeigt die Zuordnung der für die SPI-Kommunikation notwendigen Leitungen an die Pins des Mikrocontrollers.

Zur Verteilung der entstehenden Abwärme wurden auch in diesem Bereich der Platine frei gebliebene Abschnitte zwischen den Leiterbahnen mit geerdeten Kupferflächen gefüllt. Durch teilweise auch mehrfache Durchkontaktierungen wurde sowohl eine saubere Kontaktierung der Flächen durchgeführt, um Flächen schwimmenden Potentials zu vermeiden. Durch die Vias wurde aber auch die thermische Leitfähigkeit zwischen den beiden Kupferlagen erhöht und somit die Abgabe entstehender Wärme von den Bauteilen verbessert. Beim verwendeten LQFP-Gehäuse des XMC4500 liegt die Rückseite des Halbleiters offen und ist nicht im Gehäuse verschlossen. Im Bereich unter der offenliegenden Rückseite des Chips ist deswegen zur Wärmeableitung ein Feld von 6x6 Vias vorgesehen. Dieser Aufbau dient dazu, die Temperatur des Chips (junction temperature) auf den maximal erlaubten Wert TJ = 150 ◦C zu beschränken.

Um die Ausgabe von aktuellen Systemzuständen zu ermöglichen, wurden sieben Status-LEDs an freien Ausgängen des XMC4500 angeschlossen. Diese ermöglichten in active-low Ansteuerung eine Anzeige verschiedener im Mikrocontroller ablaufender Prozesse. Für vier der verwendeten Leuchtdioden wurde grün als Farbe gewählt, für die drei weiteren rot. Zur Vereinfachung eines Resets der Hardware wurde ein entsprechender Taster vorgesehen, mit dem der dafür vorgesehene PORST-Pin des Mikrocontrollers auf das 0V Potential gezogen wird und somit die Hardware zurückgesetzt wird. Die Programmierung des Mikrocontrollers erfolgt über das Joint Test Action Group (JTAG)-Interface, über welches auch das Debuggen möglich ist. Der XMC4500 stellt dafür ein JTAG-Modul bereit, welches mit den in IEEE 1149.1 festgelegten Standards übereinstimmt. Verwendet wird hierfür die achtpolige Variante des Debug-Steckers, bei dem der Platine vom JTAG-Adapter Versorgungsspannung und Masse sowie Signale für Reset, Systemtakt und die Steuerleitung übergeben werden [6].

Bachelorarbeit | 2.3 Verwendete Hardware

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
D | D
C | C
B | B
A | A

Title

Size | Number | Revision

A4

Date: | 05.09.2016 | Sheet of
File: | D:\Bachelorarbeit\..\XMC4500.SchDoc | Drawn By:

SELECT1

SELECT2

SELECT3

SELECT4

SELECT5

SELECT6

P0.1 1 | P0.0 2
P0.10 3 | P0.9 4
P3.2 | 5 P3.1 | 6 P3.0 | 7
P3.13 | 8 P3.12 | 9 P3.11 | 10 P3.10 | 11 P3.9 | 12 P3.8 | 13 P3.7 | 14
P15.7 25 | P15.6 26 | P15.5 27 | P15.4 28 | P15.3 29 | P15.2 30
P14.15 | 31 P14.14 | 32 P14.13 | 33 P14.12 | 34
P14.7 | 35 P14.6 | 36 P14.5 | 37 P14.4 | 38 P14.3 | 39 P14.2 | 40 P14.1 | 41 P14.0 | 42
P15.15 43 | P15.14 44 | P15.13 49 | P15.12 50
P14.9 | 51 P14.8 | 52
P15.9 53 | P15.8 54
P5.11 | 55 P5.10 | 56 P5.9 | 57 P5.8 | 58
P2.15 59 | P2.14 60 | P2.13 63 | P2.12 64 | P2.11 65 | P2.10 66 | P2.9 67 | P2.8 68
P2.5 69 | P2.4 70 | P2.3 71 | P2.2 72 | P2.1 73 | P2.0 74
P2.7 75 | P2.6 76
P5.7 | 77 P5.6 | 78 P5.5 | 79 P5.4 | 80 P5.3 | 81 P5.2 | 82 P5.1 | 83 P5.0 | 84
P1.15 | 94
P6.6 95 | P6.5 96 | P6.4 97 | P6.3 98 | P6.2 99 | P6.1 100 | P6.0 101
P1.14 | 102 P1.13 | 103 P1.12 | 104 P1.11 | 105 P1.10 | 106
P1.5 | 107 P1.4 | 108 P1.3 | 109 P1.2 | 110 P1.1 | 111 P1.0 | 112
P1.9 | 113 P1.8 | 114 P1.7 | 115 P1.6 | 116
P4.7 117 | P4.6 118 | P4.5 119 | P4.4 120 | P4.3 121 | P4.2 122 | P4.1 123 | P4.0 124
P0.8 127 | P0.7 128
P3.6 | 129 P3.5 | 130 P3.4 | 131 P3.3 | 132
P3.15 | 133 P3.14 | 134
P0.15 135 | P0.14 136 | P0.13 137 | P0.12 138 | P0.11 139
P0.6 140 | P0.5 141 | P0.4 142 | P0.3 143 | P0.2 144

XMC4500A

XMC4500-F144K1024 AB

ETH_CLK
ETH_CRS

ETH_MDC
ETH_MDIO
ETH_RXD0
ETH_RXD1
ETH_RXER
ETH_TXD0
ETH_TXD1
ETH_TXEN
INTRP
LED1
RESET#

Ethernet

Ethernet

MISO
MOSI

REPEAT(NCS)

REPEAT(P_ON)

REPEAT(PP2)

SCK

REPEAT(PP0)

REPEAT(PP1)

REPEAT(TDA,1,6)
TDA5340.SchDoc

PP0

PP1

PP2

PP0[1..6]

PP1[1..6]

PP2[1..6]

P_ON

SELECT[1..6SE] LECT

P_ON[1..6]

SELECT3
SELECT4
SELECT5
SELECT6

INTRP

INTRP

PP21

PP22

PP23

PP24
PP25

PP26

PP11

PP12

PP13

PP14

PP15

PP16

P_ON1

P_ON2

P_ON3

P_ON4

P_ON5

P_ON6

PP01

PP02

PP03

PP04

PP05

PP06

68

R23
Res3
68

R22
Res3
68

R21
Res3
68

R20
Res3

VDD (3,3V)

StatusLED1
StatusLED2
StatusLED3
StatusLED4

StatusLED1
StatusLED2
StatusLED3
StatusLED4

P_ON1
P_ON2
P_ON3
P_ON4
P_ON5
P_ON6

PP11
PP12
PP13
PP14
PP15
PP16

PP21
PP22
PP23
PP24
PP25
PP26

PP01
PP02
PP03
PP04
PP05
PP06

Christof Pfannenmüller

68

R25
Res3
68

R24
Res3

StatusLED5
StatusLED6

StatusLED5
StatusLED6
StatusLED7

StatusLED7

68

R26
Res3

1 2
D4
Green

1 2
D5
Green

1 2
D6
Green

1 2
D7
Green

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
XMC 4500

Abb. 2.4: Schaltplan des XMC4500 Mikrocontrollers

### 2.3.3 USB

Für die Kommunikation des Mikrocontrollers mit einem Computer wird die im XMC bereitgestellte Peripherie genutzt. Zur Verbindung mit einem anderen Gerät wurde deshalb eine kombinierte Micro-USB-Buchse verwendet, welche sowohl für Typ A- oder Typ B-Stecker geeignet ist. Um sowohl den Mikrocontroller als auch einen an die Basisstation angeschlossenen Computer gegen Fehlerströme über die USB-Leitung zu schützen wurden die Datenleitungen mit so genannten Transient Voltage Suppressor (TVS)-Dioden, welche gegen Masse geklemmt sind, geschützt. Sowohl positive als auch negative Spannungsspitzen werden dadurch gegen Masse kurzgeschlossen, was dem Schutz des XMC bzw. des angeschlossenen Computer dient. Um eine Verpolung bei Stromversorgung über die USB-Buchse und somit eine Zerstörung von Bauteilen zu vermeiden wurde eine Schottky-Diode im Strompfad zum Spannungsregler vorgesehen. Diese soll einen Stromfluss im Verpolungsfall unterbinden. Für den Fall, dass zeitgleich ein Netzteil sowie eine stromversorgende USB-Verbindung angeschlossen sind, dienen die Schottky-Dioden ebenfalls dem Schutz der Bauteile. Da der Mikrocontroller für die Kommunikation über das USB-Interface die aktuelle Busspannung auf der USB-Leitung benötigt, muss der extra dafür vorgesehene Pin des XMC direkt und ohne schützende Schottky-Diode mit der 5-V-Leitung der USB-Buchse verbunden werden. Die umgesetzte Beschaltung ist in Abbildung 2.7 auf Seite 2.7 zu erkennen.

2 Platinenaufbau | Bachelorarbeit

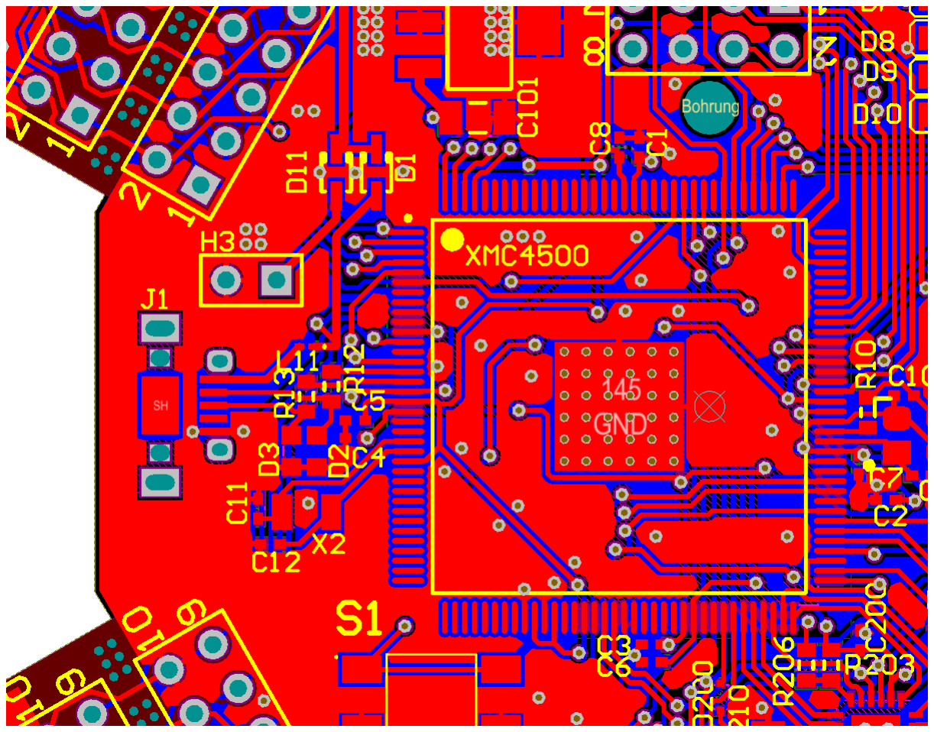
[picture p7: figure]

Abb. 2.5: Layout der USB-Buchse (links) auf der Basisstation mit der entsprechenden Schutzbeschaltung. In der Mitte des XMC sind die Thermal Vias zum Abführen der Wärme zu erkennen

### 2.3.4 Ethernet

Die Ethernetschnittstelle der Basisstation basiert auf dem Relax Kit von Infineon. Genau wie im Evaluations Board des Herstellers Infineon wurde der Ethernet-Controller KSZ8031RNL von Mircel Inc. verwendet. Dieser stellt alle wichtigen Peripherien selbst zur Verfügung und muss somit nur noch durch ein Schwingquarz und diverse Kapazitäten und Induktivitäten an den Versorgungsleitungen ergänzt werden. Da die im Controller verbaute Stufe zur Interruptgenerierung nur über einen schwachen Pull-Up Widerstand verfügt, musste ein externer Widerstand von 1 kΩ verbaut werden. Am Reset-Eingang wurde ebenfalls ein Pull-Up Widerstand verbaut. Dieser wurde um zwei Dioden sowie einen Kondensator zu der im Datenblatt empfohlenen Verschaltung erweitert. So kann sichergestellt werden, das sowohl beim Anlegen einer Spannung an das Gesamtsystem als auch bei einem Reset des Ethernetbausteins durch den steuernden Mikrocontroller alle Spannungen im sicheren Bereich liegen und die Funktion gewährleistet ist. Die dreizehn zum XMC4500 notwendigen Verbindungen wurden zur besseren Übersicht im Schaltplan in einem Signal-Kabelbaum zusammengefasst. Wegen der Gefahr von Rissen in Lötstellen durch die Platinenbelastung beim Ein- und Ausstecken wurde im Bereich um den Netzwerkstecker die Anordnung von Bauteilen vermieden. Da der KSZ8031RNL nicht lieferbar war und die anfallende Datenmenge nur von geringem Umfang ist, wurden der Controller und die entsprechende Netzwerkbuchse von Würth Electronics zunächst nicht bestückt. Somit wurde eine Verwendung des Ethernet-Controllers auch in der Software des XMC-Mikrocontrollers nicht umgesetzt. Da jedoch ein entsprechendes Softwareprojekt für das Relax Kit von Infineon zur Verfügung gestellt wird, wäre eine Netzwerkkommunikation

Bachelorarbeit | 2.3 Verwendete Hardware

vermutlich mit wenigen Anpassungen schnell umzusetzen [7].

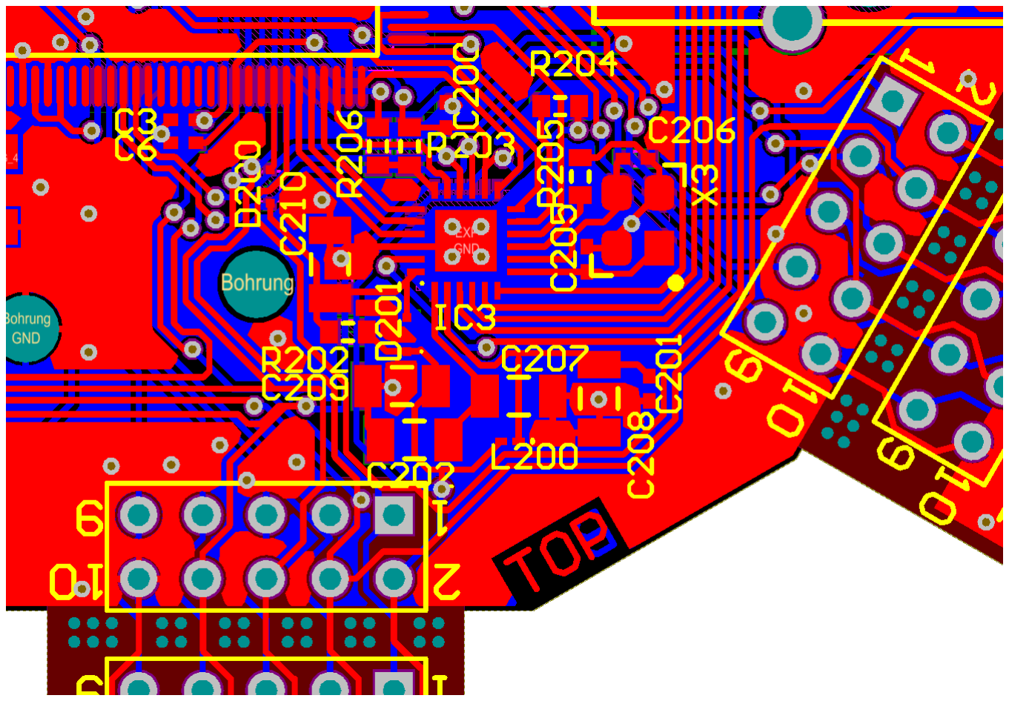
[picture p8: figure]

Abb. 2.6: Layout für den Ethernetcontroller von Mircel und die Anbindung an den XMC4500 Mikrocontroller

### 2.3.5 Spannungsversorgung

Die Bereitstellung der notwendigen Spannung sollte wahlweise über den zur Datenerfassung angeschlossenen Computer oder über ein externes Netzteil erfolgen. Zum Anschluss eines externen Netzteils wurden Lötanschlüsse für eine Steckerleiste im Rastermaß 2,54 mm vorgesehen. Genau wie bei der Stromversorgung über die USB-Buchse wurde auch hier eine Schottky-Diode zum Verpolungsschutz der Schaltung integriert. Ausgelegt ist die Basisstation für ein Gleichspannungsnetzteil mit einer Ausgangsspannung von 5 V, durch den Aufbau mit den beiden verwendeten Schottky-Dioden und die mögliche Eingangsspannung des nachfolgenden Reglers wäre jedoch auch eine angeschlossene 6-V-Versorgungsspannung (bei vernachlässigtem Spannungsabfall an der Diode) unproblematisch. Wegen der bereits erwähnten notwendigen Versorgungsspannung von 3,3 V für den XMC4500 und die Transceiver wurde diese mit einem Low Drop-Out (LDO)-Regler aus der externen, angeschlossenen Spannungsversorgung generiert. Dieser verwendete Spannungsregler der Bauart MCP1826S von Microchip Technology Inc. sollte die Eingangsspannung auf das gewünschte Niveau herunterregeln. Als Gehäusetyp wurde das dreibeinige Small Outline Transistor (SOT)-Package gewählt, da keine Variante des LDO mit einstellbarer Ausgangsspannung und somit keine Variante des ICs mit mehr Anschlusspins benötigt wurde.

Statt des LDO von Microchip war zunächst ein gleichwertiger Spannungsregler von Infineon, der IFX1117MEV33, vorgesehen. Die beiden LDOs unterscheiden sich in der elektrischen Belegung der Kühlfahne des SOT-223: beim Spannungsregler von Infineon ist diese mit dem 3,3-V-Output kontaktiert, beim verwendeten LDO mit Ground. Da es sich bei dem Spannungsregler um ein SMD-Bauteil handelt, ist die Verwendung

2 Platinenaufbau | Bachelorarbeit

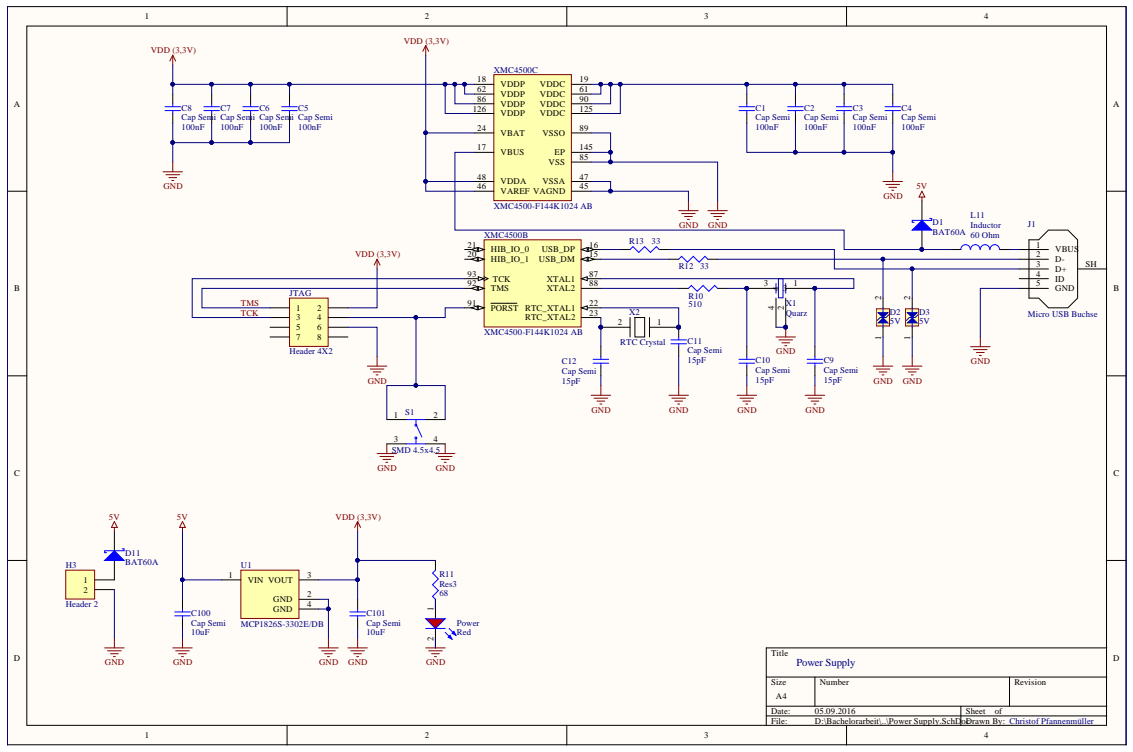
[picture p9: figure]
Title; Size; Number; Revision; Date:; Sheet of; File:; D:\Bachelorarbeit\..\Power Supply.SchDoDc rawn By:; C1 Cap Semi; C2 Cap Semi; C3 Cap Semi; C4 Cap Semi; GND; C5 Cap Semi; C6 Cap Semi; C7 Cap Semi; C8 Cap Semi; VDD (3,3V); C9 Cap Semi; C10 Cap Semi; C11 Cap Semi; C12 Cap Semi; JTAG; Header 4X2; TMS TCK; C100 Cap Semi; C101 Cap Semi; R11 Res3; USB_DM; 15 USB_DP; HIB_IO_1 20; HIB_IO_0 21; RTC_XTAL1; RTC_XTAL2; XTAL1; XTAL2; PORST 91; TMS 92; TCK 93; XMC4500B; XMC4500-F144K1024 AB; VDDP 18; VDDC; VAGND; 45 VSSA; 47 VDDA 48; 61 VDDP 62; VSS; VDDP 86; VSSO; 125 VDDP 126; 145 VBUS 17; VBAT 24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

Abb. 2.7: Schaltplan der Spannungsversorgung und der USB-Verbindung des Mikrocontrollers

von Kühlkörpern schwer möglich. Die Abführung der im Spannungsregler erzeugten Verlustwärme erfolgt deshalb üblicherweise durch das Anlöten der Kühlfahne an eine genügend große Kupferfläche, die als Wärmesenke dient. So wird die erzeugte Wärme gespreizt und kann gut an die Umgebung abgegeben werden.
Die im Spannungsregler umgesetzte Verlustleistung ergibt sich aus der vernichteten Spannungsdifferenz mal dem Strom zu
PV = (UEingang − UAusgang) · IBasisstation , | (2.2)

wobei für den Gesamtstrom der Basisstation IBasisstation eine maximale Stromaufnahme des Mikrocontrollers von 122 mA sowie bei den Transceivern eine Stromaufnahme von 26 mA angenommen werden kann [2][6]. Mit einem Spannungsabfall von 0,37 V an der Diode ergibt sich die Verlustleistung im LDO zu

PV = ((5 V − 0,37 V) − 3,3 V) · (122 mA + 6 · 26 mA) ≈ 370 mW . | (2.3)

Beide Spannungsregler dürfen nur bis zu einer Temperatur des Halbleiters von 125 ◦C betrieben werden. Bei der Verwendung des SOT-223-Gehäuses ohne eine Kupferfläche zum Abführen der Wärme würde die Chip-Temperatur Tj sogar bei einer Umgebungstemperatur von 25 ◦C schnell Werte erreichen, die kritisch werden können, wie Gleichung 2.4 zeigt. Der dabei zugrundeliegende Wärmewiderstand Rth,j−amb = 164 K/W zwischen dem

Bachelorarbeit | 2.4 Generierte Dokumente

Halbleiter und der Umgebung wird durch das Gehäuse bestimmt und ist dem Datenblatt des Infineon Spannungsreglers entnommen.

Tj = Tamb + ∆Tj−amb = Tamb + PV · Rth,j−amb = 85,68 ◦C | (2.4)

Bei Verwendung des zuerst eingeplanten IFX1117MEV33 wäre wegen der elektrischen Belegung der Kühlfinne eine Kupferfläche auf 3,3 V Potential zum Kühlen notwendig, welche elektrisch isoliert sein müsste. Wegen des Platzbedarfs durch den XMC4500 und andere Bauteile wäre somit nur eine Kupferfläche mit Abmessungen von etwa 15 mm auf 16 mm möglich, da die elektrischen Verbindungen bestehender Bauteile des Bereiches nicht unterbrochen werden sollten. Auf diese Weise wäre nicht einmal die im Datenblatt empfohlene Kühlfläche von 300 mm²
erreichbar.
Durch die Verwendung des entsprechenden Bauteils von Microchip konnte auf eine abgetrennte Kupferinsel verzichtet werden und somit die bereits erwähnte GND-Kupferfläche um den Mikrocontroller als gemeinsame Masse- und Kühlfäche verwendet werden. Wegen der vorderseitigen Bauteilbestückung war die verfügbare Kupferfläche auf der Platinenrückseite größer. Um dies beim Ableiten der Wärme vom Bauteil zu nutzen, wurden vor allem im Bereich um die Kühlfinne des SOT-223-Gehäuses Durchkontaktierungen angebracht. Diese parallelen „Thermal Vias“ konnten als Wärmepfad zur unteren Kupferfläche dienen. Außerdem wurde der JTAG-Stecker des XMC absichtlich im Bereich neben dem Spannungsregler angebracht. Durch die große Oberfläche stellt auch dieser eine gute Wärmesenke dar.

## 2.4 Generierte Dokumente

Altium Designer kann aus den erstellten PCB-Daten die für die weitere Verarbeitung benötigten Dateien generieren. Im dazu vorgesehenen Output-Job-Manager können entsprechende Outputs gewählt werden und einem Output-Container zugeordnet werden. Dies ist vor allem zum Erstellen gewünschter Dateistrukturen bei größeren Projekten notwendig um diese übersichtlich zu halten. In der vorliegenden Arbeit wurde dies jedoch nur bedingt benötigt. Für die Bestückung der Basisstation wurde zunächst eine „Bill of materials“, also eine Materialliste, exportiert, mit deren Hilfe die entsprechenden Bestellnummern des Lieferanten Digi-Key herausgesucht und sortiert werden konnten. Mit Hilfe der ebenfalls generierten „Assembly Drawings“ war die Ausgabe aller Bauteile und deren Platzierung auf der Platine möglich. Ebenfalls wurden in diesem Menü die strukturierten Schaltpläne ausgegeben.
Zur dreidimensionalen Visualisierung wurde die fertige Platine mit den in den Footprints enthaltenen Bauteilabmessungen und Höhen als 3D-Modell im Standard for the Exchange of Product Model Data (STEP)-Format ausgegeben. Mithilfe des CAD-Programms „SolidWorks“ wurde daraus ein Gehäuse mit Deckel für die Basisstation erstellt. Dieses wurde anschließend mit einem 3D-Drucker ausgedruckt und dient dazu, die Platine zu schützen. In Anhang 6.2 ist dieses Gehäuse abgebildet, das in Altium Designer erstellte 3D-Modell ist in Abbildung 2.8 zu erkennen.
Die Fertigung der Platine durch den Hersteller erfolgte durch sogenannte Gerber Daten, die ebenfalls aus dem Output-Job-Manager generiert wurden. Dabei wird für jedes Layer

2 Platinenaufbau | Bachelorarbeit

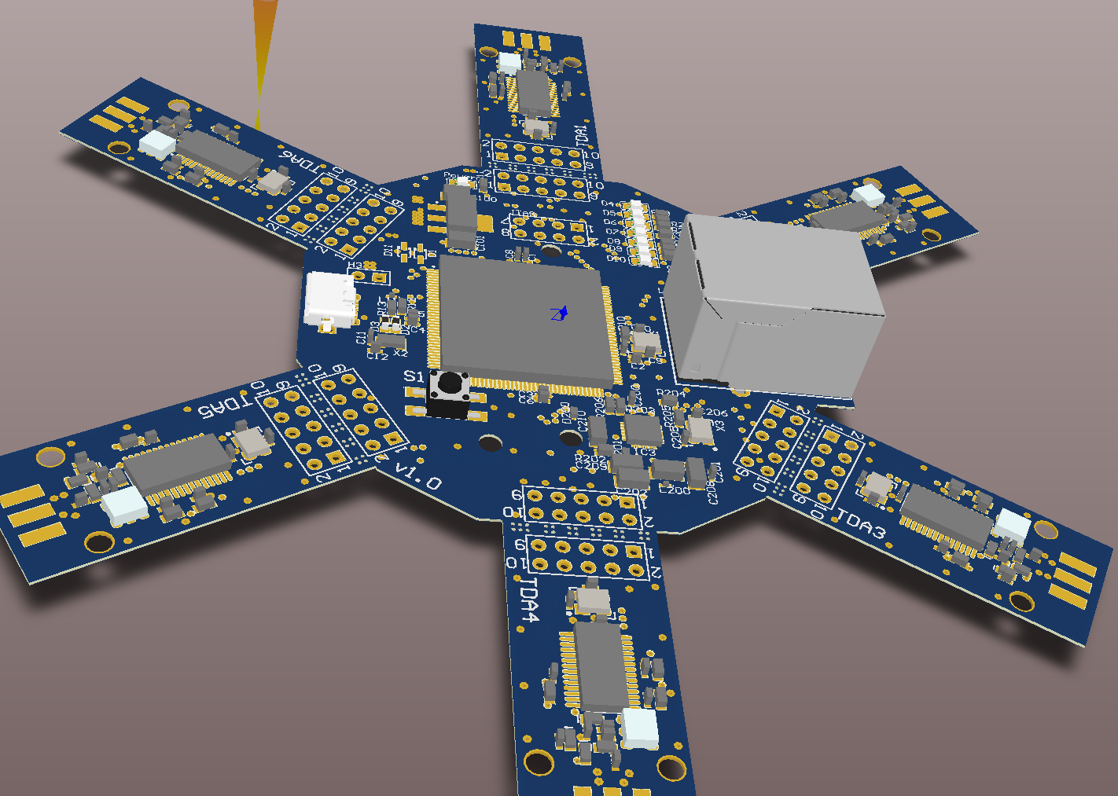
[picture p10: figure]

Abb. 2.8: 3D-Modell der Basisstation in Altium Designer

des PCB-Editors eine Gerberdatei erstellt, in der die Geometrie der entsprechenden Lage angegeben ist. Jede Lage entspricht dabei in der Herstellung einem Fertigungsschritt. Um Bohrungen in der Platine zu setzen, werden zusätzliche „NC Drill-Files“, also Daten für die Numerical Control (NC) der automatischen Maschinen zum Setzen von Bohrungen, generiert. Diese enthalten den Bohrdurchmesser, die Art der Bohrung sowie den Ort auf der Platine und müssen zusätzlich aus Altium Designer exportiert werden. Solche Bohrungen sind sowohl für Vias als auch für Befestigungsbohrungen notwendig.

## 2.5 Bestückung

Die gefertigte Platine wurde vor der Programmierung mit den notwendigen Bauteilen bestückt. Dabei wurde zuerst der XMC4500 mit einer Bestückungsmaschine auf dem vorgesehenen Footprint der Platine verlötet. Im Folgenden wurden alle weiteren Bauteile sowie die sechs Transceiver mit Lötpaste auf der Platine befestigt und anschließend durch Erhitzen der Platine auf der Heizplatte verlötet. Das Kontaktieren durch die Heizplatte wurde in mehreren Schritten durchgeführt. Dabei wurden zunächst Bauteile einer guten Toleranz hoher Temperaturen wie Stecker und Widerstände bestückt. Temperaturanfällige Bauteile wie Leuchtdioden und integrierte Schaltkreise wurden nach Möglichkeit zu einem späteren Zeitpunkt befestigt. Wie bereits erwähnt wurde der Ethernet-Controller nicht bestückt.

## Kapitel 3

# Software
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

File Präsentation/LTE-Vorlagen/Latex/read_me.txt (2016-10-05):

Erläuterung Vorlage Präsentation:

Erläuterung Latex:

	Ausführende Datei: 			Presentation.tex
	Ordner für Bilder: 			graphics
	Ordner für Zusatzdateien: 	input
	Ordner für Themebilder: 	graphics/theme
	Bild Kooperationspartner:	logoCOOP 
	
	Resentation.tex: Der erste Input Befehl, öffnet die Datei use.tex
	aus dem Ordner input. In dieser TEX-Datei sind alle nötigen 
	\usepackage Befehle enthalten. 
	Im Abschnitt "Data for Titlepage" müssen der Titel der Arbeit, der
	Untertitel, die Autoren und die Zugehörigkeit eingetragen werden. 
	Diese werden dann auf der Titelseite entsprechend eingetragen. Die 
	Kurzformen können ignoriert werden.
	
	Bilder: Bilder können im Ordner graphics gespeichert werden und 
	dann direkt aufgerufen werden, da ein entsprechender Pfad gesetzt 
	ist.
	
	Kooperationspartner/Konferenz: Das Logo des Kooperationspartners
	bzw. der Konferenz kann unter graphics/theme eingefügt werden.
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

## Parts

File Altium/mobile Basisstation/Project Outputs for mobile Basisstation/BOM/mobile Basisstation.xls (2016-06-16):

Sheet: Daten Bestellung Digi Key
Quantity | Value | Digi-Key Teilenummer | Beschreibung
34 | 100nF | 1276-1001-1-ND | Kondensator 0402
4 | 15pF | 490-6200-1-ND | Kondensator 0402
12 | 3.9pF | 490-11216-1-ND | Kondensator 0402 | geringe Toleranz
6 | 4.0pF | 490-8209-1-ND | Kondensator 0402 | geringe Toleranz
6 | 2.4pF | 490-8195-1-ND | Kondensator 0402 | geringe Toleranz
6 | 2.7pF | 490-8197-1-ND | Kondensator 0402 | geringe Toleranz
6 | 6.2pF | 490-12665-1-ND | Kondensator 0402 | geringe Toleranz
6 | 12pF | 399-7768-1-ND | Kondensator 0402 | mittlere Tolernaz
3 | 10uF | 490-5525-1-ND | Kondensator 1206
3 | 100nF | 490-3542-1-ND | Kondensator 1206
2 | 22pF | 490-8589-1-ND | Kondensator 0402
3 | 22uF | 490-6510-1-ND | Kondensator 1206
6 |  | A118077CT-ND | SMA Anschluss
2 |  | BAT60AE6327HTSA1CT-ND | Schottky-Diode
2 |  |  | evtl Alternative: | 732-3040-1-ND
4 |  | 732-4986-1-ND | LED Grün
4 |  | 732-4984-1-ND | LED Rot
2 |  |  | evtl Alternative: | BAT54-02V-V-G-08GICT-ND (http://www.digikey.de/product-detail/de/vishay-semiconductor-diodes-division/BAT54-02V-V-G-08/BAT54-02V-V-G-08GICT-ND/4810685)
6 |  | 490-4679-1-ND | Filter für TDA
12 |  | 609-3243-ND | Anschlussleiste TDA
1 |  | 609-4434-ND | Anschlussleiste für 5V
1 |  | 576-3741-5-ND | Ethernetcontroller
1 |  | WM17144CT-ND | Micro USB Buchs
1 |  | 609-3391-ND | ISP Connector
18 | 10nH | PCD2002CT-ND | Spule 0603
6 | 150nH | PCD2016CT-ND | Spule 0603
3 | 60 Ohm | 490-7820-1-ND | Spule 0603
12 | 10 | 1276-3481-1-ND | Widerstand 0603
6 | 4,7 | 1276-4486-1-ND | Widerstand 0603
1 | 510 | 1276-4621-1-ND | Widerstand 0603
8 | 68 | 1276-4550-1-ND | Widerstand 0603
2 | 33 | 1276-4524-1-ND | Widerstand 0603
2 | 120 | 1276-4566-1-ND | Widerstand 0603
1 | 10K | 1276-3485-1-ND | Widerstand 0603
2 | 1K | 1276-3484-1-ND | Widerstand 0603
1 | 6.49K | 1276-4726-1-ND | Widerstand 0603
1 | 0 | 1276-3510-1-ND | Widerstand 0603
1 |  | 732-4506-5-ND | LAN Buchse
6
1 |  | MCP1826S-3302E/DB-ND | Spannungsregler
6 | 21.948717 MHz |  | Quarz TDA
1 | 32.768KHz | 535-9542-1-ND | Quarz RTC
1 | 25MHz | 535-9568-1-ND | Quarz Ethernetcontroller
1 |  | XMC4500F144K1024ACXQMA1-ND | XMC4500
1 | Quarz XMC4500 | 535-9561-1-ND | Quarz XMC4500

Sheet: aus_Altium
Comment | Description | Designator | Footprint | LibRef | Manufacturer | Quantity | Value | Anzahl | Digi-Key Teilenummer | Beschreibung
Cap Semi | Capacitor (Semiconductor SIM Model) | C1, C2, C3, C4, C5, C6, C7, C8, C21_TDA1, C21_TDA2, C21_TDA3, C21_TDA4, C21_TDA5, C21_TDA6, C22_TDA1, C22_TDA2, C22_TDA3, C22_TDA4, C22_TDA5, C22_TDA6, C23_TDA1, C23_TDA2, C23_TDA3, C23_TDA4, C23_TDA5, C23_TDA6, C24_TDA1, C24_TDA2, C24_TDA3, C24_TDA4, C24_TDA5, C24_TDA6, C200, C201 | 0402 | Cap Semi |  | 34 | 100nF | 34 | 1276-1001-1-ND | Kondensator 0402
Cap Semi | Capacitor (Semiconductor SIM Model) | C9, C10, C11, C12 | 0402 | Cap Semi |  | 4 | 15pF | 4 | 490-6200-1-ND | Kondensator 0402
Cap Semi | Capacitor (Semiconductor SIM Model) | C25_TDA1, C25_TDA2, C25_TDA3, C25_TDA4, C25_TDA5, C25_TDA6, C26_TDA1, C26_TDA2, C26_TDA3, C26_TDA4, C26_TDA5, C26_TDA6 | 0402 | Cap Semi |  | 12 | 3.9pF | 12 | 490-11216-1-ND | Kondensator 0402 | geringe Toleranz
Cap Semi | Capacitor (Semiconductor SIM Model) | C27_TDA1, C27_TDA2, C27_TDA3, C27_TDA4, C27_TDA5, C27_TDA6 | 0402 | Cap Semi |  | 6 | 4.0pF | 6 | 490-8209-1-ND | Kondensator 0402 | geringe Toleranz
Cap Semi | Capacitor (Semiconductor SIM Model) | C28_TDA1, C28_TDA2, C28_TDA3, C28_TDA4, C28_TDA5, C28_TDA6 | 0402 | Cap Semi |  | 6 | 2.4pF | 6 | 490-8195-1-ND | Kondensator 0402 | geringe Toleranz
Cap Semi | Capacitor (Semiconductor SIM Model) | C29_TDA1, C29_TDA2, C29_TDA3, C29_TDA4, C29_TDA5, C29_TDA6 | 0402 | Cap Semi |  | 6 | 2.7pF | 6 | 490-8197-1-ND | Kondensator 0402 | geringe Toleranz
Cap Semi | Capacitor (Semiconductor SIM Model) | C30_TDA1, C30_TDA2, C30_TDA3, C30_TDA4, C30_TDA5, C30_TDA6 | 0402 | Cap Semi |  | 6 | 6.2pF | 6 | 490-12665-1-ND | Kondensator 0402 | geringe Toleranz
Cap Semi | Capacitor (Semiconductor SIM Model) | C31_TDA1, C31_TDA2, C31_TDA3, C31_TDA4, C31_TDA5, C31_TDA6 | 0402 | Cap Semi |  | 6 | 12pF | 6 | 399-7768-1-ND | Kondensator 0402 | mittlere Tolernaz
Cap Semi | Capacitor (Semiconductor SIM Model) | C100, C101, C210 | C1206 | Cap Semi |  | 3 | 10uF | 3 | 490-5525-1-ND | Kondensator 1206
Cap Semi | Capacitor (Semiconductor SIM Model) | C202, C203, C204 | C1206 | Cap Semi |  | 3 | 100nF | 3 | 490-3542-1-ND | Kondensator 1206
Cap Semi | Capacitor (Semiconductor SIM Model) | C205, C206 | 0402 | Cap Semi |  | 2 | 22pF | 2 | 490-8589-1-ND | Kondensator 0402
Cap Semi | Capacitor (Semiconductor SIM Model) | C207, C208, C209 | C1206 | Cap Semi |  | 3 | 22uF | 3 | 490-6510-1-ND | Kondensator 1206
SMA |  | CON1_TDA1, CON1_TDA2, CON1_TDA3, CON1_TDA4, CON1_TDA5, CON1_TDA6 | SMA | SMA |  | 6 |  | 6 | A118077CT-ND | SMA Anschluss
BAT60A | Silicon AF Schottky Rectifier Diode with Extreme Low VF Drop | D1, D11 | SOD-323 | BAT60A |  | 2 |  | 2 | BAT60AE6327HTSA1CT-ND | Schottky-Diode
82356050560 | WE-VE ESD Suppressor, 0603, VDC=5V | D2, D3 | WE-VE_0603 | WE-VE 0603, 82356050560 | Wurth Elektronik | 2 |  | 2 |  | evtl Alternative: | 732-3040-1-ND
Green | SMD mono-color Chip LED, WL-SMCW, Green | D4, D5, D6, D7 | LED_0805_Green | WL-SMCW 0805 150080GS75000 | W黵th Elektronik eiSos GmbH | 4 |  | 4 | 732-4986-1-ND | LED Grün
Red | SMD mono-color Chip LED, WL-SMCW, Red | D8, D9, D10, Power | LED_0805_Red | WL-SMCW 0805 150080RS75000 | W黵th Elektronik eiSos GmbH | 4 |  | 4 | 732-4984-1-ND | LED Rot
BAT54-02V | Silicon Schottky Diode, SC79, Reel, Green | D200, D201 | INF-SC79_V | BAT54-02V | Infineon | 2 |  | 2 |  | evtl Alternative: | BAT54-02V-V-G-08GICT-ND (http://www.digikey.de/product-detail/de/vishay-semiconductor-diodes-division/BAT54-02V-V-G-08/BAT54-02V-V-G-08GICT-ND/4810685)
SFECF10M7EA00 |  | F1_TDA1, F1_TDA2, F1_TDA3, F1_TDA4, F1_TDA5, F1_TDA6 | SOP6 | SFECF10M7EA00 |  | 6 |  | 6 | 490-4679-1-ND | Filter für TDA
Header 5X2 | Header, 5-Pin, Dual row | H1_TDA1, H1_TDA2, H1_TDA3, H1_TDA4, H1_TDA5, H1_TDA6, H2_TDA1, H2_TDA2, H2_TDA3, H2_TDA4, H2_TDA5, H2_TDA6 | HDR2X5 | Header 5X2 |  | 12 |  | 12 | 609-3243-ND | Anschlussleiste TDA
Header 2 | Header, 2-Pin | H3 | HDR1X2 | Header 2 |  | 1 |  | 1 | 609-4434-ND | Anschlussleiste für 5V
KSZ8031RNL |  | IC3 | QFN /MLF 24pin | KSZ8031RNL |  | 1 |  | 1 | 576-3741-5-ND | Ethernetcontroller
Micro USB Buchse |  | J1 | Micro USB Buchse - Molex | Micro USB Buchse - Molex |  | 1 |  | 1 | WM17144CT-ND | Micro USB Buchs
Header 4X2 | Header, 4-Pin, Dual row | JTAG | HDR2X4 | Header 4X2 |  | 1 |  | 1 | 609-3391-ND | ISP Connector
Inductor | Inductor | L1_TDA1, L1_TDA2, L1_TDA3, L1_TDA4, L1_TDA5, L1_TDA6, L3_TDA1, L3_TDA2, L3_TDA3, L3_TDA4, L3_TDA5, L3_TDA6, L4_TDA1, L4_TDA2, L4_TDA3, L4_TDA4, L4_TDA5, L4_TDA6 | INDC1608L | Inductor |  | 18 | 10nH | 18 | PCD2002CT-ND | Spule 0603
Inductor | Inductor | L2_TDA1, L2_TDA2, L2_TDA3, L2_TDA4, L2_TDA5, L2_TDA6 | INDC1608L | Inductor |  | 6 | 150nH | 6 | PCD2016CT-ND | Spule 0603
Inductor | Inductor | L11, L200, L201 | 0603 | Inductor |  | 3 | 60 Ohm | 3 | 490-7820-1-ND | Spule 0603
Res3 | Resistor | R1_TDA1, R1_TDA2, R1_TDA3, R1_TDA4, R1_TDA5, R1_TDA6, R3_TDA1, R3_TDA2, R3_TDA3, R3_TDA4, R3_TDA5, R3_TDA6 | J1-0603 | Res3 |  | 12 | 10 | 12 | 1276-3481-1-ND | Widerstand 0603
Res3 | Resistor | R2_TDA1, R2_TDA2, R2_TDA3, R2_TDA4, R2_TDA5, R2_TDA6 | J1-0603 | Res3 |  | 6 | 4,7 | 6 | 1276-4486-1-ND | Widerstand 0603
Res3 | Resistor | R10 | J1-0603 | Res3 |  | 1 | 510 | 1 | 1276-4621-1-ND | Widerstand 0603
Res3 | Resistor | R11, R20, R21, R22, R23, R24, R25, R26 | J1-0603 | Res3 |  | 8 | 68 | 8 | 1276-4550-1-ND | Widerstand 0603
Res3 | Resistor | R12, R13 | J1-0603 | Res3 |  | 2 | 33 | 2 | 1276-4524-1-ND | Widerstand 0603
Res3 | Resistor | R200, R201 | J1-0603 | Res3 |  | 2 | 120 | 2 | 1276-4566-1-ND | Widerstand 0603
Res3 | Resistor | R202 | J1-0603 | Res3 |  | 1 | 10K | 1 | 1276-3485-1-ND | Widerstand 0603
Res3 | Resistor | R203, R204 | J1-0603 | Res3 |  | 2 | 1K | 2 | 1276-3484-1-ND | Widerstand 0603
Res3 | Resistor | R205 | J1-0603 | Res3 |  | 1 | 6.49K | 1 | 1276-4726-1-ND | Widerstand 0603
Res3 | Resistor | R206 | J1-0603 | Res3 |  | 1 | 0 | 1 | 1276-3510-1-ND | Widerstand 0603
7499010211A | RJ45 LAN Transformer, 10/100 Base-T | T1 | 7499010211A | 7499010211A | Wurth Elektronik | 1 |  | 1 | 732-4506-5-ND | LAN Buchse
TDA5340 | High Sensitivity Multi-Channel Transceiver, -40 to 110 degC, PG-TSSOP-28, Green | TDA5340_TDA1, TDA5340_TDA2, TDA5340_TDA3, TDA5340_TDA4, TDA5340_TDA5, TDA5340_TDA6 | INF-PG-TSSOP-28_N | TDA5340 | Infineon | 6 |  | 6
MCP1826S-3302E/DB | 1000 mA, Low Voltage, Low Quiescent Current LDO Regulator, 3-Pin SOT-223, Extended Temperature | U1 | SOT-223-DB3_N | MCP1826S-3302E/DB | Microchip | 1 |  | 1 | MCP1826S-3302E/DB-ND | Spannungsregler
Quarz |  | X1, X_TDA_TDA1, X_TDA_TDA2, X_TDA_TDA3, X_TDA_TDA4, X_TDA_TDA5, X_TDA_TDA6 | Quarz | Quarz |  | 7 |  | 7 |  | Quarz TDA
RTC Crystal |  | X2 | RTC Uhrenquarz 1.5x3.2 SMD | RTC Crystal |  | 1 | 32.768KHz | 1 | 535-9542-1-ND | Quarz RTC
25MHz |  | X3 | Quarz | Quarz |  | 1 | 25MHz | 1 | 535-9568-1-ND | Quarz Ethernetcontroller
XMC4500-F144K1024 AB | 120 MHz XMC4500 MCU with 1,024 KByte Program Memory, 160 KByte SRAM, 3.3 V, -40 to 125 degC, PG-LQFP-144, Green | XMC4500 | INF-PG-LQFP-144-18-6500X6500TP_N | XMC4500-F144K1024 AB | Infineon | 1 |  | 1 | XMC4500F144K1024ACXQMA1-ND | XMC4500
 |  |  |  |  |  |  | Quarz XMC4500 | 1 | 535-9561-1-ND | Quarz XMC4500

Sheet: für Bestückung
Comment | Description | Designator | Footprint | LibRef | Quantity | Value | Anzahl | Digi-Key Teilenummer | Beschreibung
Cap Semi | Capacitor (Semiconductor SIM Model) | C1, C2, C3, C4, C5, C6, C7, C8, C21_TDA1, C22_TDA1,C23_TDA1, C24_TDA1, C200, C201 | 0402 | Cap Semi | 34 | 100nF | 34 | 1276-1001-1-ND | Kondensator 0402
Cap Semi | Capacitor (Semiconductor SIM Model) | C9, C10, C11, C12 | 0402 | Cap Semi | 4 | 15pF | 4 | 490-6200-1-ND | Kondensator 0402
Cap Semi | Capacitor (Semiconductor SIM Model) | C25_TDA1, C26_TDA1, | 0402 | Cap Semi | 12 | 3.9pF | 12 | 490-11216-1-ND | Kondensator 0402 | geringe Toleranz
Cap Semi | Capacitor (Semiconductor SIM Model) | C27_TDA1, C27_TDA2, C27_TDA3, C27_TDA4, C27_TDA5, C27_TDA6 | 0402 | Cap Semi | 6 | 4.0pF | 6 | 490-8209-1-ND | Kondensator 0402 | geringe Toleranz
Cap Semi | Capacitor (Semiconductor SIM Model) | C28_TDA1, C28_TDA2, C28_TDA3, C28_TDA4, C28_TDA5, C28_TDA6 | 0402 | Cap Semi | 6 | 2.4pF | 6 | 490-8195-1-ND | Kondensator 0402 | geringe Toleranz
Cap Semi | Capacitor (Semiconductor SIM Model) | C29_TDA1, C29_TDA2, C29_TDA3, C29_TDA4, C29_TDA5, C29_TDA6 | 0402 | Cap Semi | 6 | 2.7pF | 6 | 490-8197-1-ND | Kondensator 0402 | geringe Toleranz
Cap Semi | Capacitor (Semiconductor SIM Model) | C30_TDA1, C30_TDA2, C30_TDA3, C30_TDA4, C30_TDA5, C30_TDA6 | 0402 | Cap Semi | 6 | 6.2pF | 6 | 490-12665-1-ND | Kondensator 0402 | geringe Toleranz
Cap Semi | Capacitor (Semiconductor SIM Model) | C31_TDA1, C31_TDA2, C31_TDA3, C31_TDA4, C31_TDA5, C31_TDA6 | 0402 | Cap Semi | 6 | 12pF | 6 | 399-7768-1-ND | Kondensator 0402 | mittlere Tolernaz
Cap Semi | Capacitor (Semiconductor SIM Model) | C100, C101, C210 | C1206 | Cap Semi | 3 | 10uF | 3 | 490-5525-1-ND | Kondensator 1206
Cap Semi | Capacitor (Semiconductor SIM Model) | C202, C203, C204 | C1206 | Cap Semi | 3 | 100nF | 3 | 490-3542-1-ND | Kondensator 1206
Cap Semi | Capacitor (Semiconductor SIM Model) | C205, C206 | 0402 | Cap Semi | 2 | 22pF | 2 | 490-8589-1-ND | Kondensator 0402
Cap Semi | Capacitor (Semiconductor SIM Model) | C207, C208, C209 | C1206 | Cap Semi | 3 | 22uF | 3 | 490-6510-1-ND | Kondensator 1206
SMA |  | CON1_TDA1, CON1_TDA2, CON1_TDA3, CON1_TDA4, CON1_TDA5, CON1_TDA6 | SMA | SMA | 6 |  | 6 | A118077CT-ND | SMA Anschluss
BAT60A | Silicon AF Schottky Rectifier Diode with Extreme Low VF Drop | D1, D11 | SOD-323 | BAT60A | 2 |  | 2 | BAT60AE6327HTSA1CT-ND | Schottky-Diode
82356050560 | WE-VE ESD Suppressor, 0603, VDC=5V | D2, D3 | WE-VE_0603 | WE-VE 0603, 82356050560 | 2 |  | 2 |  | evtl Alternative: | 732-3040-1-ND
Green | SMD mono-color Chip LED, WL-SMCW, Green | D4, D5, D6, D7 | LED_0805_Green | WL-SMCW 0805 150080GS75000 | 4 |  | 4 | 732-4986-1-ND | LED Grün
Red | SMD mono-color Chip LED, WL-SMCW, Red | D8, D9, D10, Power | LED_0805_Red | WL-SMCW 0805 150080RS75000 | 4 |  | 4 | 732-4984-1-ND | LED Rot
BAT54-02V | Silicon Schottky Diode, SC79, Reel, Green | D200, D201 | INF-SC79_V | BAT54-02V | 2 |  | 2 |  | evtl Alternative: | BAT54-02V-V-G-08GICT-ND (http://www.digikey.de/product-detail/de/vishay-semiconductor-diodes-division/BAT54-02V-V-G-08/BAT54-02V-V-G-08GICT-ND/4810685)
SFECF10M7EA00 |  | F1_TDA1, F1_TDA2, F1_TDA3, F1_TDA4, F1_TDA5, F1_TDA6 | SOP6 | SFECF10M7EA00 | 6 |  | 6 | 490-4679-1-ND | Filter für TDA
Header 5X2 | Header, 5-Pin, Dual row | H1_TDA1, H1_TDA2, H1_TDA3, H1_TDA4, H1_TDA5, H1_TDA6, H2_TDA1, | HDR2X5 | Header 5X2 | 12 |  | 12 | 609-3243-ND | Anschlussleiste TDA
Header 2 | Header, 2-Pin | H3 | HDR1X2 | Header 2 | 1 |  | 1 | 609-4434-ND | Anschlussleiste für 5V
KSZ8031RNL |  | IC3 | QFN /MLF 24pin | KSZ8031RNL | 1 |  | 1 | 576-3741-5-ND | Ethernetcontroller
Micro USB Buchse |  | J1 | Micro USB Buchse - Molex | Micro USB Buchse - Molex | 1 |  | 1 | WM17144CT-ND | Micro USB Buchs
Header 4X2 | Header, 4-Pin, Dual row | JTAG | HDR2X4 | Header 4X2 | 1 |  | 1 | 609-3391-ND | ISP Connector
Inductor | Inductor | L1_TDA1, L3_TDA1, L4_TDA1, | INDC1608L | Inductor | 18 | 10nH | 18 | PCD2002CT-ND | Spule 0603
Inductor | Inductor | L2_TDA1, L2_TDA2, L2_TDA3, L2_TDA4, L2_TDA5, L2_TDA6 | INDC1608L | Inductor | 6 | 150nH | 6 | PCD2016CT-ND | Spule 0603
Inductor | Inductor | L11, L200, L201 | 0603 | Inductor | 3 | 60 Ohm | 3 | 490-7820-1-ND | Spule 0603
Res3 | Resistor | R1_TDA1, R1_TDA2, R1_TDA3, R1_TDA4, R1_TDA5, R1_TDA6, R3_TDA1 | J1-0603 | Res3 | 12 | 10 | 12 | 1276-3481-1-ND | Widerstand 0603
Res3 | Resistor | R2_TDA1, R2_TDA2, R2_TDA3, R2_TDA4, R2_TDA5, R2_TDA6 | J1-0603 | Res3 | 6 | 4,7 | 6 | 1276-4486-1-ND | Widerstand 0603
Res3 | Resistor | R10 | J1-0603 | Res3 | 1 | 510 | 1 | 1276-4621-1-ND | Widerstand 0603
Res3 | Resistor | R11, R20, R21, R22, R23, R24, R25, R26 | J1-0603 | Res3 | 8 | 68 | 8 | 1276-4550-1-ND | Widerstand 0603
Res3 | Resistor | R12, R13 | J1-0603 | Res3 | 2 | 33 | 2 | 1276-4524-1-ND | Widerstand 0603
Res3 | Resistor | R200, R201 | J1-0603 | Res3 | 2 | 120 | 2 | 1276-4566-1-ND | Widerstand 0603
Res3 | Resistor | R202 | J1-0603 | Res3 | 1 | 10K | 1 | 1276-3485-1-ND | Widerstand 0603
Res3 | Resistor | R203, R204 | J1-0603 | Res3 | 2 | 1K | 2 | 1276-3484-1-ND | Widerstand 0603
Res3 | Resistor | R205 | J1-0603 | Res3 | 1 | 6.49K | 1 | 1276-4726-1-ND | Widerstand 0603
Res3 | Resistor | R206 | J1-0603 | Res3 | 1 | 0 | 1 | 1276-3510-1-ND | Widerstand 0603
7499010211A | RJ45 LAN Transformer, 10/100 Base-T | T1 | 7499010211A | 7499010211A | 1 |  | 1 | 732-4506-5-ND | LAN Buchse
TDA5340 | High Sensitivity Multi-Channel Transceiver, -40 to 110 degC, PG-TSSOP-28, Green | TDA5340_TDA1, TDA5340_TDA2, TDA5340_TDA3, TDA5340_TDA4, TDA5340_TDA5, TDA5340_TDA6 | INF-PG-TSSOP-28_N | TDA5340 | 6 |  | 6
MCP1826S-3302E/DB | 1000 mA, Low Voltage, Low Quiescent Current LDO Regulator, 3-Pin SOT-223, Extended Temperature | U1 | SOT-223-DB3_N | MCP1826S-3302E/DB | 1 |  | 1 | MCP1826S-3302E/DB-ND | Spannungsregler
Quarz |  | X1, X_TDA_TDA1, X_TDA_TDA2, X_TDA_TDA3, X_TDA_TDA4, X_TDA_TDA5, X_TDA_TDA6 | Quarz | Quarz | 7 |  | 7 |  | Quarz TDA
RTC Crystal |  | X2 | RTC Uhrenquarz 1.5x3.2 SMD | RTC Crystal | 1 | 32.768KHz | 1 | 535-9542-1-ND | Quarz RTC
25MHz |  | X3 | Quarz | Quarz | 1 | 25MHz | 1 | 535-9568-1-ND | Quarz Ethernetcontroller
XMC4500-F144K1024 AB | 120 MHz XMC4500 MCU with 1,024 KByte Program Memory, 160 KByte SRAM, 3.3 V, -40 to 125 degC, PG-LQFP-144, Green | XMC4500 | INF-PG-LQFP-144-18-6500X6500TP_N | XMC4500-F144K1024 AB | 1 |  | 1 | XMC4500F144K1024ACXQMA1-ND | XMC4500
 |  |  |  |  |  | Quarz XMC4500 | 1 | 535-9561-1-ND | Quarz XMC4500

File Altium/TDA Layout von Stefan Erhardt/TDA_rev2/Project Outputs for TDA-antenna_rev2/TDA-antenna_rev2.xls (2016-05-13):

Comment | Description | Designator | Footprint | LibRef | Quantity | Value
antenna |  | A1 | Chip Antenna | antenna | 1
0402 | Capacitor | C1, C2, C3, C4, C5, C8, C9, C10, C11, C12, C13 | C0402_M | Cap0402 | 11 | 4.0pF, 2.7pF, 2.4pF, 12pF, 3.9p, 3.9p, 6.2pF, 100n, 100n, 100n, 100n
SFECF10M7EA00 |  | F1 | SOP6 | SFECF10M7EA00 | 1
0603 | Inductor | L1, L2, L3, L4 | L0603_M | Ind0603 | 4 | 10nH, 150nH, 10nH, 10nH
Header 8 | Header, 8-Pin | P1, P2 | HDR1X8 | Header 8 | 2
0402 | Resistor | R1, R2, R3 | R0402_M | Res0402 | 3 | 10, 4.7, 10
TDA5340 | High Sensitivity Multi-Channel Transceiver, -40 to 110 degC, PG-TSSOP-28, Green | U1 | INF-PG-TSSOP-28_L | CMP-1173-00001-1 | 1
Quarz |  | X1 | Quarz | Quarz | 1

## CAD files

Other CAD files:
Altium/Box/ImportSW/L2_TDA5.sldasm
Altium/Box/ImportSW_alt/C28_TDA2.sldasm
Altium/Box/ImportSW/C1.sldasm
Altium/Box/ImportSW_alt/C27_TDA6.sldasm
Altium/Box/V2/C21_TDA6.sldasm
Altium/Box/ImportSW/C27_TDA2.sldasm
Altium/Box/ImportSW_alt/C29_TDA3.sldasm
Altium/Box/V2/L4_TDA4.sldasm
Altium/Box/ImportSW/R12.sldasm
Altium/Box/ImportSW_alt/C27_TDA4.sldasm
Altium/Box/V2/C207.sldasm
Altium/Box/ImportSW_alt/C22_TDA6.sldasm
Altium/Box/V2/D4.sldasm
Altium/Box/ImportSW/L4_TDA1.sldasm
Altium/Box/ImportSW_alt/X2.sldasm
Altium/Box/V2/C203.sldasm
Altium/Box/ImportSW/L201.sldasm
Altium/Box/ImportSW_alt/R1_TDA2.sldasm
Altium/Box/Deckel.STL
Altium/Box/Deckel.sldprt
Altium/Box/ImportSW/430181038816.sldasm
Altium/Box/ImportSW/475900001.sldasm
Altium/Box/ImportSW/7499010211A.sldasm
Altium/Box/ImportSW/885541288.sldasm
Altium/Box/ImportSW/885541424.sldasm
Altium/Box/ImportSW/885541560.sldasm
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

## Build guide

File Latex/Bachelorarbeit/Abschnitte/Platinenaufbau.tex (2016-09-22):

\chapter{Platinenaufbau}
\label{sec:Platinenaufbau}
\pagestyle{scrheadings}

\section{Vorüberlegungen} 
Die Zielsetzung im Aufbau der Platine war eine kompakte Basisstation mit sechs Transceivern und einer zentralen Steuereinheit. Um sicherzustellen, dass alle Antennen gleichmäßig in die sechs vorgegebenen Raumrichtungen abstrahlen, sollte bereits die Platine symmetrisch aufgebaut werden. Dazu wurde zuerst das Layout der sechs identischen Transceiver-Einheiten mit dem TDA5340-Baustein und den Antennenanschlüssen erstellt und anschließend gleichmäßig um die weiteren für die Schaltung notwendigen funktionellen Segmente angeordnet.

\section{Layoutprogramm Altium Designer}
Bei dem Entwicklungswerkzeug \enquote{Altium Designer} des Entwicklers Altium Limited handelt es sich um ein System zum Entwurf von  gedruckten  Schaltungen oder \acp{PCB}. Ein solches Programm wird auch als \ac{EDA} oder ECAD für electronic \ac{CAD} bezeichnet, da es den Entwickler bei der Umsetzung der Anforderungen in einen Schaltplan und später eine Platine unterstützen soll.
Wie viele andere \ac{EDA}-Programme ist auch Altium Designer so aufgebaut, dass sich der Entwickler zuerst mit dem allgemeinen symbolisierten Schaltplan befassen kann und erst zu einem späteren Zeitpunkt die tatsächliche Anordnung der Bauteile auf dem \ac{PCB}-Substrat festgelegt wird. Somit können zuerst im Schematic Editor die Funktionen der Schaltung umgesetzt werden. Dazu werden die verwendeten Bauteile aus zuvor angelegten Bibliotheken verwendet oder es werden bestehende Libraries genutzt, die etwa vom Hersteller der Bauteile zur Verfügung gestellt werden. Altium selbst bietet hierfür auch diverse Möglichkeiten an und stellt Bauteile nach Hersteller und Art geordnet bereit.
In den Bibliotheken sind alle im weiteren Verlauf benötigten Informationen über die einzelnen Bauteile enthalten. So liegen dort etwa  entsprechende Abbildungen für das Bauteil im  Schaltplan  vor. In den so genannten \enquote{Footprints} zu jedem Bauteil, welche ebenfalls in den Bibliotheken enthalten sind, wurden zuvor die für das physikalische Gehäuse notwendigen Abmessungen, Lötpads und Ausmaße für Lötstopplack um das Bauteil festgelegt. Da es Bauteile, wie den verwendeten  Mikrocontroller in verschiedenen Gehäusen geben kann, besteht somit auch die Möglichkeit, hier zwischen verschiedenen Footprints zu wählen. Da viele Gehäuse herstellerübergreifend genormt sind, konnten teilweise bestehende Footprints genutzt  oder diese mehrfach verwendet werden.

Wie bereits erwähnt wird im \ac{EDA}-Programm zuerst der symbolische Schaltplan erstellt. Dieser wird anschließend in ein Layout für eine Platine umgewandelt. Die zu den Schaltplansymbolen korrespondierenden Footprints werden dazu auf dem Layout der Platine angeordnet und durch das \enquote{Routing} werden die Leiterbahnen definiert.
Altium Designer ist dabei in drei Teilbereiche unterteilt: Im \enquote{Board Planning Mode}  liegt der Fokus auf dem Anordnen der einzelnen Bauteile und Komponenten auf der Leiterplatte, außerdem wird in diesem Bereich die Form und das Ausmaß der Leiterplatte festgelegt. Im 2D-Modus des \ac{PCB}-Editor lassen sich anschließend die aus der Definition im Schaltplan ergebenden elektrischen Verbindungen örtlich auf den verschiedenen Kupferebenen (Layern) anordnen. Die Hauptarbeit findet also in diesem Teil des \ac{PCB}-Editors statt. Der 3D-Modus dient anschließend zur Evaluation des Designs und zur Anpassung an Gehäuse oder andere Komponenten.
In den verschiedenen Ebenen oder \enquote{Layern} sind die Kupferebenen und andere Schichten der späteren Platine wie der Bestückungsdruck oder der Lötstopplack gesammelt. Jede Ebene entspricht daher einer zu fertigenden Schicht und existiert für die Vorder- und Rückseite der Platine. Beim Bewegen eines Bauteils wird nicht nur die markierte Abmessung, sondern etwa auch die Anschluss-Pads und der Lötstopplack der Komponente auf den entsprechenden Ebenen bewegt. Durch Vias sind elektrische Verbindungen zwischen den Kupferschichten möglich.

Für die Basisstation wurden zwei Kupferebenen und ausschließlich sogenannte \ac{SMD}-Bauelemente verwendet. Diese liegen nur auf der Oberfläche der Platine auf und sind durch ihre Lötverbindungen befestigt. Die Vorteile dieser Bauteile sind der geringe Preis und die kleinen Abmessungen. 

%Ebenfalls...    Layers/ebene, top, bot, bestückungsdruck, solderresin
%lagenanzahl 
%lötpad
%platinenmaterial (zb bezüglich wärmemangement)s. Übung LEKFZ
%welche Bauteile in eigener Lib?
%verwendung SMD Bauteile

%Bauteileingabe und schaltplan
%Multi channel - multi sheet
Wegen der Größe des Projekts wurde zur besseren Übersicht ein  so genanntes \enquote{Multi-Sheet-Design} erstellt. Dadurch war es möglich, die verschiedenen funktionellen Blöcke der Basisstation auf getrennte Blätter des Schaltplans zu verteilen. Der Mikrocontroller, die Spannungsversorgung und der Transceiver sowie die für eine Netzwerkkommunikation notwendigen Bauteile  wurden dabei auf unabhängigen Seiten angeordnet und dort die elektrischen Verbindungen erstellt.

Da der Transceiver und die entsprechende Peripherie sechsmal in identischer Anordnung und Beschaltung verwendet wurden und auch auf dem \ac{PCB}-Substrat mehrfach mit Leiterbahnen verbunden und angeordnet werden mussten, wurde hierfür ein so genanntes \enquote{Multi-Channel}-Design gewählt. In Altium Designer können mit diesem Feature identische Schaltungsteile einmal angeordnet, mit Leiterbahnen verbunden  und dieses Design auf alle anderen entsprechenden Schaltungsteile angewendet werden. Somit muss das aufwändige Anordnen der Bauteile und die Führung der Leiterbahnen nur bei einem der Kanäle durchgeführt werden.  Dazu wurde mit Hilfe eines übergeordneten Sheet-Symbols der Schaltplan des Transceivers in den Schaltplan des Mikrocontrollers eingefügt und diesem somit untergeordnet. Über Ports, welche zum  Schaltplansymbol hinzugefügt werden, lassen sich elektrische Verbindungen zwischen Netzen innerhalb der Schaltpläne für Transceiver  und Mikrocontroller erstellen. Dabei wird im Transceiver-Schaltplan ein Port hinzugefügt, der mit dem gewünschten elektrischen Netz  verbunden werden kann. Auf dem Schaltplansymbol im Mikrocontroller-Schaltplan wird ein entsprechender gleichnamiger Port erstellt, der mit Netzen am Mikrocontroller verbunden werden kann. Da die drei Verbindungen der \ac{SPI}-Kommunikation jeweils aus einem Netz bestehen und etwa alle \acs{MISO}-Leitungen an demselben Pin des XMC4500 und demselben Anschluss bei allen TDAs angebunden sind, konnte hierfür ein einfacher Port verwendet werden. Alle anderen Anschlüsse, wie etwa die Auswahlleitung für das \ac{SPI}-Interface, welche für jede der sechs verschiedenen Transceiver-Einheiten mit einem anderen Anschluss des Mikrocontrollers verbunden sein musste, wurden deswegen mit dem Repeat-Kommando erstellt. So wird im untergeordneten Schaltplan, in diesem Fall dem des TDA, der Port beliebig benannt, etwa als \enquote{NCS}. Der auf dem Schaltplansymbol erstellte korrespondierende Port wird dagegen in \enquote{Repeat(NCS)} umbenannt. Eine Verbindung mit dem Port auf dem Schaltplansymbol wird dadurch zu einem Bus. Dieser kann aufgetrennt werden und die Verbindungen von jedem Kanal als einzelnes Signal an den Mikrocontroller angeschlossen werden. Globale Netze wie die Versorgungsspannung von \unit[3,3]{Volt} oder die Masse müssen dabei nicht als Port hinzugefügt werden. Altium Designer stellt deren Verbindungen automatisch her. 

Wird nun noch der Name des Schaltplansymbols nach dem folgenden Muster angepasst, wird Altium Designer beim Kompilieren des Projektes ein Multi-Channel-Design erstellen, die Kanäle wie angegeben durchnummerieren und den Kanal im \ac{PCB}-Editor entsprechend mehrfach erstellen. Dazu sollte der Name die Struktur \enquote{Repeat(<Name>,<Startnummer> ,<Endnummer>)} aufweisen. Anschließend kann die Anordnung und das Routing des ersten Kanals erfolgen. Da für jeden Kanal ein eigener so genannter \enquote{Room} erstellt wird, lassen sich, nach dem Erstellen der Leiterbahnen des ersten Kanals, die Anordnungen der Bauteile und Leiterbahnen mit dem \enquote{Copy Room Format}-Befehl auf alle anderen Kanäle erweitern. Ein Room bezeichnet dabei eine Gruppe an Elementen im PCB-Editor und einen Bereich der Platine, in dem diese angeordnet sind und erlaubt so das Verschieben ganzer Schaltungsteile auf der Platine. Der Schaltplan des Hauptkanals, welcher einen einzelnen der sechs Kanal darstellt, ist in Abbildung \ref{fig:schemTDA} zu erkennen.

% Bestückungsdruck
Altium Designer nummeriert automatisch die verwendeten  Bauelemente durch, um die genaue Identifikation eines Bauteiles zu erlauben und erstellt automatisch einen Aufdruck neben dem Lötpad mit dem Bauteilnamen in der entsprechenden Ebene. Ein solcher Bestückungsdruck zur leichteren Anordnung der Bauteile auf der fertig entwickelten Platine wurde nur auf der Hauptplatine erstellt. Auf den Teilplatinen für die Transceiver wurde dieser aus Platzgründen weggelassen.

% Design Rule Check
Um sicherzustellen, dass die sich aus der Bauteilanordnung ergebenden Pads und die Leiterbahnen auch fertigbar sind, stellt Altium Designer zwei \acp{DRC}  bereit. Im ersten Live-\ac{DRC} werden \enquote{Violations}, also Bauteile mit Verstößen gegen die Designregeln, durch ein farbiges Overlay markiert. Im folgenden kompletten Test zeigt Altium alle weiteren Verstöße an. Als Verstoß gelten etwa Leiterbahnen unterschiedlicher Netze, die sich berühren und zu einem Kurzschluss führen würden oder auch  Verletzungen der festgelegten Abstandsregeln (Clearance). Alle Regeln für Violations können im \enquote{PCB Rules Editor} eingestellt werden und so an die Möglichkeiten des \ac{PCB}-Herstellers angepasst werden. Da die Leiterplatte für die Basisstation von \mbox{Multi Circuit Boards Ltd.} hergestellt wurde, konnten die auf der Webseite dieses Herstellers angegebenen Designregeln für den \ac{DRC} übernommen werden.
Da bei Altium Designer im \ac{DRC}  kurzgeschlossene und falsch verbundene Leitungen oder Pads angezeigt werden, muss kein extra \enquote{Layout vs. Schematic}-Test durchgeführt werden, der den vorher erstellten Schaltplan mit dem Layout abgleicht. Unterschiede zwischen Schaltplan und dem \ac{PCB}-Layout würden durch den \ac{DRC} bereits angezeigt.

\section{Verwendete Hardware}

\subsection{TDA5340}
Der verwendete Transceiver TDA5340 wird von Infineon Technologies AG  entwickelt und vertrieben. Er ist Teil der SmartLEWIS Produktfamilie, die  energiesparende Lösungen für Funkanwendungen im Frequenzspektrum unterhalb von einem Gigahertz bietet. 
Der Transceiver kommuniziert mit seinem Host über das \ac{SPI}-Protokoll, der Mikrocontroller ist in diesem Fall sternförmig mit den einzelnen TDA-Bausteinen verbunden, die als Slaves fungieren. Die Daten werden mit drei gemeinsamen Leitungen übertragen, eine vierte Leitung dient dem XMC zur Auswahl des gewünschten Slaves für die Kommunikation. Diese \ac{NCS}-Leitung arbeitet active-low, sodass der jeweilige TDA5340 eine Interaktion akzeptiert, sobald diese vom XMC-Baustein auf Massepotential gezogen wird. Von den drei eigentlichen Datenleitungen fungiert eine als reiner Ausgang des Masters bzw. Dateneingang des TDA (\acs{MOSI}), eine zweite als Eingang des Masters (\acs{MISO}) und die dritte als ein vom Mikrocontroller getriebenes Clock-Signal. Bei dem auf \acs{MISO} und \acs{MOSI} anliegenden Signal handelt es sich um ein unipolar kodiertes non-return-to-zero Signal, welches einer logischen $0$ bei Massepotential entspricht. Der TDA unterstützt acht verschiedene Instruktionen, die es erlauben einzelne Register des Bausteins zu lesen bzw. zu schreiben, auf mehrere hintereinander folgende Register zuzugreifen oder auf die beiden Puffer des Bausteins zuzugreifen. In den beiden Puffern, die als \mbox{\ac{FIFO}}-Strukturen  aufgebaut sind, werden die vom TDA erkannten und demodulierten bzw. die auf Übertragung wartenden Signalpakete zwischengespeichert. Diese Zwischenspeicherung soll den Mikrocontroller entlasten, so können entsprechende Datenpakete dem TDA5340 mitgeteilt werden und dieser übernimmt selbsttätig eine korrekte Modulation und Übertragung mit den eingestellten Parametern. 

Der TDA5340 kann sowohl mit einer Versorgungsspannung von \unit[5]{V} als auch bei \unit[3,3]{V} arbeiten. Da aber der XMC nur bei letzterer betrieben werden kann, wurde der TDA-Baustein und die externe Beschaltung ebenfalls auf  \unit[3,3]{V} ausgelegt. 
%interruptregister
%Package -transparent modes of tda (Des weiteren erlaubt der Baustein noc )

%zweiseitige platine, Top und Botom, zwei kupferflächen
%speichert feldstärkewert der letzten übertragung in eigenem register
%interrupt register

\begin{figure}[h]
\centering

\caption{Schaltplan der Transceiverbaugruppe}
\label{fig:schemTDA}
\end{figure}

Um zu einem späterem Zeitpunkt eine größere Entfernung zwischen den einzelnen Antennen und somit auch den jeweiligen Transceivern zu erlauben, wurde eine Sollbruchstelle vorgesehen. Dadurch könnte die gesamte Baugruppe von der Mutterplatine entfernt werden, was unter Umständen notwendig gewesen wäre, um die Auswirkungen verschiedener Antennenabstände an der Basis zu evaluieren und somit eine bessere Auflösung in der Ortung zu erlauben. Dazu wurden Anschlussleisten im Rastermaß \unit[2,54]{mm} an beiden Seiten der Sollbruchstelle vorgesehen. Die Verbindung der Transceiver-Einheiten mit der Hauptplatine wurde über diese Sollbruchstelle hinweg mit Leiterbahnen gewährleistet. Nach dem Abtrennen der TDA-Teilplatine an der durch Bohrungen vorgesehenen Bruchstelle wäre die elektrische Verbindung durch Kabel sichergestellt worden. Da es sich bei den zu übertragenden ausschließlich um digitale Signale  geringerer Frequenzen im Bereich unter \unit[1]{MHz} handelt, hätte dies unproblematisch mit ungeschirmten Flachbandkabeln realisiert werden können. Neben der Versorgungsspannung, der Masse und den vier für die \ac{SPI}-Kommunikation notwendigen Signalen wurden noch die drei multifunktionalen Digitalausgänge und der Power-On Reset-Pin (P\_ON) dem XMC4500 über die Buchsenleisten zur Verfügung gestellt.

Der TDA5340 ist ein \ac{IC} der über drei multifunktionale Digitalausgänge PP0, PP1 und PP2 verfügt. Diese können durch entsprechende Kalibrierung von Registern mit verschiedenen Signalen belegt werden. So ist es etwa möglich mit diesen einen externen Antennenumschalter zu steuern oder andere Signale wie ein Clocksignal auszugeben. PP2 wird vom TDA standardmäßig als Interrupt Signal verwendet. Die nicht verwendeten PP1 und PP0 wurden bei der späteren Konfiguration in den hochohmigen Zustand geschaltet. Durch einen am  P\_ON-Pin anliegenden High-Pegel wechselt der Transceiver in den eingeschalteten Zustand. Anderenfalls ist dieser ausgeschaltet und verbraucht typischerweise weniger als \unit[1]{\textmu A}.

\begin{figure}[h]
\centering

\caption[Layout des Transceivers]{Layout des Transceivers mit der Sollbruchstelle und der Steckerleiste (links) sowie dem Anpassnetzwerk. Die Lötflächen für die SMA-Buchse sind auf der rechten Seite erkennbar}
\label{fig:tdalayout}

\end{figure}

Die Antenne wurde am oberen Ende jeder TDA5340-Teilplatine vorgesehen. Als Anschluss für die Antenne wurde hier eine Koaxialbuchse in \ac{SMA}-Ausführung verwendet, welche auf \unit[50]{$\Omega$} angepasst ist. Durch den Koaxialsteckverbinder konnte sichergestellt werden, dass alle notwendigen Frequenzen auch korrekt und ungedämpft passieren können. 
Das Anpassnetzwerk zwischen dem  integrierten Transceiver und der verwendeten \ac{SMA}-Buchse diente der Leistungsanpassung zwischen den Pins des TDA5340 und der 50-$\Omega$-Koaxialbuchse. Der Aufbau des Anpassnetzwerkes basiert auf einem von Stefan Erhard erstellten Schaltplan für eine Aufsteckplatine für das Evaluationsboard \enquote{XMC 2Go} von Infineon. Das entsprechende Layout ist im Anhang \ref{app:Aufsteckboard} abgebildet. Durch die Verwendung von hoch abgestimmten Spulen und Kondensatoren mit Toleranzen von nur \unit[±0,05]{pF} bei einem Nennwert von \unit[2,5]{pF} wurde die korrekte Anpassung sichergestellt. 

Zur Verbesserung der Hochfrequenzeigenschaften wurden die Freiräume zwischen den Leiterbahnen mit einer Kupferfläche gefüllt, die mit dem Masseanschluss verbunden war. Durch die Verwendung von Vias, vor allem im Bereich des Anpassnetzwerkes, sollte eine niederohmige Verbindung zwischen den beiden Masseflächen auf der Ober- bzw. Unterseite der Platine erreicht werden. Daneben dienten diese auf Nullpotential liegenden Vias jedoch vor allem der Abschirmung der Pfade für die HF-Signale gegen mögliche Einkoppelungen aus der Umgebung, welche ankommende Funksignale stören könnten.

Obwohl der TDA5340 einen eingebauten Zwischenfrequenz-Filter hat, der über eine umschaltbare Bandbreite verfügt, wurde ein externer Keramikfilter verwendet. Der TDA stellt dafür zwei Pins bereit, zwischen denen ein solcher Filter mit einer Frequenz von \unit[10,7]{MHz} angeschlossen werden kann. Ohne einen hier extern angeschlossenen Filter würde der TDA als einfacher heterodyner Mischer direkt auf die Zwischenfrequenz $f_{IF2}=\unit[274]{kHz}$ heruntermischen. Bei Verwendung eines externen Keramik- oder auch eines LC-$\pi$-Filters kann das ankommende HF-Signal jedoch in zwei Stufen gefiltert werden, ehe es in das Basisband demoduliert wird, was zu einer höheren Signalqualität führt. Die Umstellung zwischen einfacher und Double Down Conversion erfolgt durch das Setzen eines dafür vorgesehenen Bits \cite{TDA-DataSheet}\cite{TDA-UserManual}.

Die elektrischen Verbindungen zwischen den beiden symmetrischen Eingängen des Low Noise Amplifier und dem Anpassnetzwerk wurden mit dem \enquote{Differential Pair Routing}-Feature von Altium Designer erstellt. Durch einen im Schaltplan auf die positive und negative elektrische Leitung zwischen dem TDA5340 und dem Anpassnetzwerk angewendeten Parameter wird das Leitungspaar als differentiell markiert. Anschließend kann mit dem interaktiven \enquote{Diffential Pair Routing} einer der beiden Leitungen begonnen werden. Altium Designer wird dabei selbstständig versuchen, die zweite Leiterbahn des Paares so anzuordnen, das die beiden Leiterbahnen symmetrisch und parallel zueinander liegen, sodass Störeinflüsse möglichst gleichmäßig auf die beiden Leitungen einwirken. So sollen Störungen besser toleriert und durch die symmetrische Signalübertragung insgesamt ausgeglichen werden können \cite{High-Speed-Guide}.
Durch die Verwendung des \enquote{Diffential Pair Routing} versucht Altium Designer auch die Länge der beiden Verbindungen anzugleichen. Durch die Anpassungen der differentiellen Leiterbahnen wird eine korrekte Übertragung durch gleiche Signallaufzeiten sichergestellt. Da diese Leitungen hochfrequente Signale führen, ist eine genaue Anpassung notwendig.

Um Einkopplungen auf die Pfade für hochfrequente Signale zu vermeiden, wurde das für den Transceiver benötigte Quarz möglichst weit vom Sende- bzw. von den Empfangsanschlüssen des TDA angeordnet. Aus diesem Grund wurde der für den Oszillator benötigte Quarz mit einer Frequenz $f_{Crystal}=\unit[21,948717]{MHz}$ zwischen dem \ac{IC} und der vorgesehenen Stiftleiste platziert.  Die Frequenz des benötigten Quarzes ergibt sich aus dem Zusammenhang
\begin{equation}\label{eq:fsys}
f_{Crystal} = f_{IF2} \cdot 80 = \frac{f_{IF1}}{39} \cdot 80  = \frac{\unit[10,7]{MHz}}{39} \cdot 80 = \unit[21,948717]{MHz}\, ,
\end{equation}
wobei die Zwischenfrequenz der ersten Stufe ($f_{IF1}$) durch die internen funktionalen Blöcke des TDA und den Keramikfilter vorgegeben ist. Die weiteren Faktoren ergeben sich aus dem Aufbau des Empfängers und werden von Infineon bereitgestellt \cite{TDA-UserManual}.

\subsection{XMC4500}
%\begin{figure}[h] %trim=16cm 8cm 16cm 26cm,   auf Computer daheim: 8cm 4cm 8cm 13cm
%	\centering
%	\includegraphics[width=0.7\linewidth,trim={16cm 8cm 16cm 26cm},clip=true]{"Quellen/New Infineon Controller Family/XMC4500_LQFP-100_LQFP-144_LFBGA-144"}
%	\caption{Der XMC4500 Mikrocontroller von Infineon im LQFP-Gehäuse mit 144 Pins \cite{Bauer2012New-Infineon-32}}
%	\label{fig:xmc4500}
%\end{figure}
\begin{figure}[h]
\centering

\caption{Der XMC4500 Mikrocontroller von Infineon im LQFP-Gehäuse mit 144 Pins \cite{Bauer2012New-Infineon-32}}
\label{fig:xmc4500}
\end{figure}

Die Hauptsteuerung der Basisstation übernimmt ein Mikrocontroller der Bauart XMC4500, welcher aus der Mikrocontroller-Familie XMC4000 von Infineon stammt. Diese Baureihe stellt energieeffiziente \acp{IC} bereit, welche für industrielle Steuerungen und \enquote{Sense \& Control} optimiert sind. 
Der XMC4500 basiert auf einem  Cortex-M4 Kern des britischen Herstellers ARM. Daneben arbeitet der Mikrocontroller mit der von Infineon selbst entwickelten Entwicklungsumgebung DAVE zusammen.
Im speziellen Anwendungsfall kommt die Variante des XMC mit 144 Pins und einem Flash-Speicher von 1024 Kilobit zum Einsatz. Der Chip ist dabei in einem \ac{LQFP}-Gehäuse verbaut. Durch die Wahl dieses Gehäuses konnte die elektrische Verbindung mit der Platine relativ leicht durch Löten erreicht werden. Im Gegensatz zum ebenfalls erhältlichen \ac{BGA}-Gehäuse des XMC sind in diesem alle Kontakte direkt erreichbar und können leicht verlötet werden. Da beim \ac{BGA}-Gehäuse die Anschlüsse auch in der Mitte unter dem Gehäuse sind, wäre hier ein Layout komplizierter und würde möglicherweise einen genaueren und somit teureren Prozess für die Herstellung der Platine fordern. Ein händisches Nachlöten von Kontakten oder Prüfen der Lötverbindung wäre ebenfalls nicht möglich.

%PP2 an INterrupeingang
Bei der Auswahl von Pins des XMC zur Verbindung mit den Transceivern wurde vor allem auf die Auswahl für die PP2 Pins geachtet. Um eine spätere Interruptsteuerung möglich zu machen, wurden hierfür nur solche Eingänge des Mikrocontrollers gewählt, die im Datenblatt mit der Möglichkeit zum Erkennen von Interrupts gekennzeichnet sind. Die Zuordnung der Transceiverausgänge an die Pins des Mikrocontrollers sind in \mbox{Abbildung \ref{fig:schemXMC}} erkennbar und in Tabelle \ref{tab:PP2ERU} auf Seite \pageref{tab:PP2ERU} aufgeführt. Tabelle \ref{tab:SPI} der Seite \pageref{tab:SPI} zeigt die Zuordnung der für die \ac{SPI}-Kommunikation notwendigen Leitungen an die Pins des Mikrocontrollers. 

Zur Verteilung der entstehenden Abwärme wurden auch in diesem Bereich der Platine  frei gebliebene Abschnitte zwischen den Leiterbahnen mit geerdeten Kupferflächen gefüllt. Durch teilweise auch mehrfache Durchkontaktierungen wurde sowohl eine saubere Kontaktierung der Flächen durchgeführt, um Flächen schwimmenden Potentials zu vermeiden. Durch die Vias wurde aber auch die thermische Leitfähigkeit zwischen den beiden Kupferlagen erhöht und somit die Abgabe entstehender Wärme von den Bauteilen verbessert. Beim verwendeten \ac{LQFP}-Gehäuse des XMC4500 liegt die Rückseite des Halbleiters offen und ist nicht im Gehäuse verschlossen. Im Bereich unter der offenliegenden Rückseite des Chips ist deswegen zur Wärmeableitung ein Feld von 6x6 Vias vorgesehen. Dieser Aufbau dient dazu, die Temperatur des Chips (junction temperature) auf den maximal erlaubten Wert $T_J = \unit[150]{^\circ C}$ zu beschränken.%Rechnung mit Therm wiederst. ??

\begin{figure}[h]
	\centering
	
	\caption{Schaltplan des XMC4500 Mikrocontrollers}
	\label{fig:schemXMC}
\end{figure}

%Quarz (dämpfungswiderstand)
%Für mögliche spätere Anwendungsfälle wurde außerdem ein Quarz für die Realtime-Clock des XMC4500 vorgesehen

%Reset taster
%LEDs
Um die Ausgabe von aktuellen Systemzuständen zu ermöglichen, wurden sieben Status-LEDs an freien Ausgängen des XMC4500  angeschlossen. Diese ermöglichten in active-low Ansteuerung eine Anzeige verschiedener im Mikrocontroller ablaufender Prozesse. Für vier der verwendeten Leuchtdioden wurde grün als Farbe gewählt, für die drei weiteren rot. Zur Vereinfachung eines Resets der Hardware wurde ein entsprechender Taster vorgesehen, mit dem der dafür vorgesehene  $\overline{\text{PORST}}$-Pin des Mikrocontrollers auf das 0V Potential gezogen wird und somit die Hardware zurückgesetzt wird.
Die Programmierung des Mikrocontrollers erfolgt über das \ac{JTAG}-Interface, über welches auch das Debuggen möglich ist. Der XMC4500 stellt dafür ein \ac{JTAG}-Modul bereit, welches mit den in IEEE 1149.1 festgelegten Standards übereinstimmt. Verwendet wird hierfür die achtpolige Variante des Debug-Steckers, bei dem der Platine vom \ac{JTAG}-Adapter Versorgungsspannung und Masse sowie Signale für Reset, Systemtakt und die Steuerleitung übergeben werden \cite{XMC-DataSheet}.  % nur zwei angeschlossen?

%Abblockkondensatoren

\subsection{USB}
Für die Kommunikation des Mikrocontrollers mit einem Computer wird die im XMC bereitgestellte Peripherie genutzt. Zur Verbindung mit einem anderen Gerät wurde deshalb eine kombinierte Micro-USB-Buchse verwendet, welche sowohl für Typ A- oder Typ B-Stecker geeignet ist.
Um sowohl den Mikrocontroller als auch einen an die Basisstation angeschlossenen Computer gegen Fehlerströme über die USB-Leitung zu schützen wurden die Datenleitungen mit so genannten \ac{TVS}-Dioden, welche gegen Masse geklemmt sind, geschützt. Sowohl positive als auch negative Spannungsspitzen werden dadurch gegen Masse kurzgeschlossen, was dem Schutz des XMC bzw. des angeschlossenen Computer dient. Um eine Verpolung bei Stromversorgung über die USB-Buchse und somit eine Zerstörung von Bauteilen zu vermeiden wurde eine Schottky-Diode im Strompfad zum Spannungsregler vorgesehen. Diese soll einen Stromfluss im Verpolungsfall unterbinden. Für den Fall, dass zeitgleich ein Netzteil sowie eine stromversorgende USB-Verbindung angeschlossen sind, dienen die Schottky-Dioden ebenfalls dem Schutz der Bauteile. Da der Mikrocontroller für die Kommunikation über das USB-Interface die aktuelle Busspannung auf der USB-Leitung benötigt, muss der extra dafür vorgesehene Pin des XMC direkt und ohne schützende Schottky-Diode mit der 5-V-Leitung der USB-Buchse verbunden werden. Die umgesetzte Beschaltung ist in Abbildung \ref{fig:schemSupply} auf Seite \ref{fig:schemSupply} zu erkennen.
\begin{figure}[h]
\centering

\caption[Layout der USB-Buchse mit der entsprechenden Schutzbeschaltung]{Layout der USB-Buchse (links) auf der Basisstation mit der entsprechenden Schutzbeschaltung. In der Mitte des XMC sind die Thermal Vias zum Abführen der Wärme zu erkennen}
\label{fig:usb-und-xmc}
\end{figure}

\subsection{Ethernet}
Die Ethernetschnittstelle der Basisstation basiert auf dem  Relax Kit von Infineon. Genau wie im Evaluations Board des Herstellers Infineon wurde der Ethernet-Controller KSZ8031RNL von Mircel Inc. verwendet. Dieser stellt alle wichtigen Peripherien selbst zur Verfügung und muss somit nur noch durch ein Schwingquarz und diverse Kapazitäten und Induktivitäten an den Versorgungsleitungen ergänzt werden. Da die im Controller verbaute Stufe zur Interruptgenerierung nur über einen schwachen Pull-Up Widerstand verfügt, musste ein externer Widerstand von \unit[1]{k$\Omega$} verbaut werden. Am Reset-Eingang wurde ebenfalls ein Pull-Up Widerstand verbaut. Dieser wurde um zwei Dioden sowie einen Kondensator zu der im Datenblatt empfohlenen Verschaltung erweitert. So kann sichergestellt werden, das sowohl beim Anlegen einer Spannung an das Gesamtsystem als auch bei einem Reset des Ethernetbausteins durch den steuernden Mikrocontroller alle Spannungen im sicheren Bereich liegen und die Funktion gewährleistet ist. Die dreizehn zum XMC4500 notwendigen Verbindungen wurden zur besseren Übersicht im Schaltplan in einem Signal-Kabelbaum zusammengefasst. Wegen der Gefahr von Rissen in Lötstellen durch die Platinenbelastung beim Ein- und Ausstecken wurde im Bereich um den Netzwerkstecker die Anordnung von Bauteilen vermieden. 
Da der KSZ8031RNL  nicht lieferbar war und die anfallende Datenmenge nur von geringem Umfang ist, wurden der Controller und die entsprechende Netzwerkbuchse von Würth Electronics zunächst nicht bestückt. Somit wurde eine Verwendung des Ethernet-Controllers auch in der Software des XMC-Mikrocontrollers nicht umgesetzt. Da jedoch ein entsprechendes Softwareprojekt für das Relax Kit von Infineon zur Verfügung gestellt  wird, wäre eine Netzwerkkommunikation vermutlich mit wenigen Anpassungen schnell umzusetzen \cite{DAVE-3-Example-}. 
\begin{figure}[h]
\centering

\caption{Layout für den Ethernetcontroller von Mircel und die Anbindung an den XMC4500 Mikrocontroller}
\label{fig:ethernet}
\end{figure}

\subsection{Spannungsversorgung}
Die Bereitstellung der notwendigen Spannung sollte wahlweise über den zur Datenerfassung angeschlossenen Computer oder über ein externes Netzteil erfolgen. Zum Anschluss eines externen Netzteils wurden Lötanschlüsse für eine Steckerleiste im Rastermaß \unit[2,54]{mm} vorgesehen. Genau wie bei der Stromversorgung über die USB-Buchse wurde auch hier eine Schottky-Diode zum Verpolungsschutz der Schaltung integriert. Ausgelegt ist die Basisstation für ein Gleichspannungsnetzteil mit einer Ausgangsspannung von \unit[5]{V}, durch den Aufbau mit den beiden verwendeten Schottky-Dioden und die mögliche Eingangsspannung des nachfolgenden Reglers wäre jedoch auch eine angeschlossene 6-V-Versorgungsspannung (bei vernachlässigtem Spannungsabfall an der Diode) unproblematisch.
Wegen der bereits erwähnten notwendigen Versorgungsspannung von \unit[3,3]{V} für den XMC4500 und die Transceiver wurde diese mit einem \ac{LDO}-Regler aus der externen, angeschlossenen Spannungsversorgung generiert. Dieser verwendete Spannungsregler der Bauart MCP1826S von Microchip Technology Inc. sollte die Eingangsspannung auf das gewünschte Niveau herunterregeln.
Als Gehäusetyp wurde das dreibeinige \ac{SOT}-Package gewählt, da keine Variante des \ac{LDO} mit einstellbarer Ausgangsspannung und somit keine Variante des \acp{IC} mit mehr Anschlusspins benötigt wurde.
\begin{figure}[h]
	\centering
	
	\caption{Schaltplan der Spannungsversorgung und der USB-Verbindung des Mikrocontrollers}
	\label{fig:schemSupply}
\end{figure}

Statt des \ac{LDO} von Microchip war zunächst ein gleichwertiger Spannungsregler von Infineon, der IFX1117MEV33, vorgesehen. Die beiden \acp{LDO} unterscheiden sich in der elektrischen Belegung der Kühlfahne des \ac{SOT}-223: beim Spannungsregler von Infineon ist diese mit dem 3,3-V-Output kontaktiert, beim verwendeten \ac{LDO} mit Ground. Da es sich bei dem Spannungsregler um ein \ac{SMD}-Bauteil handelt, ist die Verwendung von Kühlkörpern schwer möglich. Die Abführung der im Spannungsregler erzeugten Verlustwärme erfolgt deshalb üblicherweise durch das Anlöten der Kühlfahne an eine genügend große Kupferfläche, die als Wärmesenke dient. So wird die erzeugte Wärme gespreizt und kann gut an die Umgebung abgegeben werden. 

Die im Spannungsregler umgesetzte Verlustleistung ergibt sich aus der vernichteten Spannungsdifferenz mal dem Strom zu
\begin{equation}
P_V = (U_{Eingang} - U_{Ausgang}) \cdot I_{Basisstation}\, ,
\end{equation} 
wobei für den Gesamtstrom der Basisstation $I_{Basisstation}$ eine maximale Stromaufnahme des Mikrocontrollers von \unit[122]{mA} sowie bei den Transceivern eine Stromaufnahme von \unit[26]{mA} angenommen werden kann \cite{TDA-DataSheet}\cite{XMC-DataSheet}. Mit einem Spannungsabfall von \unit[0,37]{V} an der Diode ergibt sich die Verlustleistung im \ac{LDO} zu
\begin{equation}
P_V = ((\unit[5]{V} - \unit[0,37]{V}) - \unit[3,3]{V}) \cdot ( \unit[122]{mA} + 6 \cdot \unit[26]{mA}) \approx \unit[370]{mW}\, .
\end{equation} 
Beide Spannungsregler dürfen nur bis zu einer Temperatur des Halbleiters von \unit[125]{$^\circ$C} betrieben werden. Bei der Verwendung des \ac{SOT}-223-Gehäuses ohne eine Kupferfläche zum Abführen der Wärme würde die Chip-Temperatur $T_{j}$ sogar bei einer Umgebungstemperatur von \unit[25]{$^\circ$C} schnell  Werte erreichen, die kritisch werden können, wie Gleichung \ref{eq:Tjunction} zeigt. Der dabei zugrundeliegende Wärmewiderstand $R_{th,j-amb} = \unit[164]{K/W}$ zwischen dem Halbleiter und der Umgebung wird durch das Gehäuse bestimmt und ist dem Datenblatt des Infineon Spannungsreglers entnommen.
\begin{equation}
T_{j} = T_{amb} + \Delta T_{j-amb} = T_{amb} + P_V \cdot R_{th,j-amb} = \unit[85,68]{^\circ C}
\label{eq:Tjunction}
\end{equation}
Bei Verwendung des zuerst eingeplanten IFX1117MEV33 wäre wegen der elektrischen Belegung der Kühlfinne eine Kupferfläche auf \unit[3,3]{V} Potential zum Kühlen notwendig, welche elektrisch isoliert sein müsste. Wegen des Platzbedarfs durch den XMC4500 und andere Bauteile wäre somit nur eine Kupferfläche mit Abmessungen von etwa \unit[15]{mm} auf \unit[16]{mm} möglich, da die elektrischen Verbindungen bestehender Bauteile des Bereiches nicht unterbrochen werden sollten. Auf diese Weise wäre nicht einmal die im Datenblatt empfohlene Kühlfläche von \unit[300]{mm$^2$} erreichbar. 

Durch die Verwendung des entsprechenden Bauteils von Microchip konnte auf eine abgetrennte Kupferinsel verzichtet werden und somit die bereits erwähnte \acs{GND}-Kupferfläche um den Mikrocontroller als gemeinsame Masse- und Kühlfäche verwendet werden.
Wegen der vorderseitigen Bauteilbestückung war die verfügbare Kupferfläche auf der Platinenrückseite  größer. Um dies beim Ableiten der Wärme vom Bauteil zu nutzen, wurden vor allem im Bereich um die Kühlfinne des \ac{SOT}-223-Gehäuses Durchkontaktierungen angebracht. Diese parallelen \enquote{Thermal Vias} konnten als Wärmepfad zur unteren Kupferfläche dienen. Außerdem wurde der \ac{JTAG}-Stecker des XMC absichtlich im Bereich neben dem Spannungsregler angebracht. Durch die große Oberfläche stellt auch dieser eine gute Wärmesenke dar. %sicher?
% Rechnung Thermischer widerstand

\section{Generierte Dokumente}
Altium Designer kann aus den erstellten \ac{PCB}-Daten die für die weitere Verarbeitung benötigten Dateien generieren. Im dazu vorgesehenen Output-Job-Manager können entsprechende Outputs gewählt werden und einem Output-Container zugeordnet werden. Dies ist vor allem zum Erstellen gewünschter Dateistrukturen bei größeren Projekten notwendig um diese übersichtlich zu halten. In der vorliegenden Arbeit wurde dies jedoch nur bedingt benötigt.
Für die Bestückung der Basisstation wurde zunächst eine \enquote{Bill of materials}, also eine Materialliste, exportiert, mit deren Hilfe die entsprechenden Bestellnummern des Lieferanten Digi-Key herausgesucht und sortiert werden konnten. Mit Hilfe der ebenfalls generierten \enquote{Assembly Drawings} war die Ausgabe aller Bauteile und deren Platzierung auf der Platine möglich. Ebenfalls wurden in diesem Menü die strukturierten Schaltpläne ausgegeben.

Zur dreidimensionalen Visualisierung wurde die fertige Platine mit den in den Footprints enthaltenen Bauteilabmessungen und Höhen als 3D-Modell im \ac{STEP}-Format ausgegeben. Mithilfe des \ac{CAD}-Programms \enquote{SolidWorks} wurde daraus ein Gehäuse mit Deckel für die Basisstation erstellt. Dieses wurde anschließend mit einem 3D-Drucker ausgedruckt und dient dazu, die Platine zu schützen. In Anhang \ref{app:Gehause} ist dieses Gehäuse abgebildet, das in Altium Designer erstellte 3D-Modell ist in Abbildung \ref{fig:3D} zu erkennen.

\begin{figure}[h] 
	\centering
	
	\caption{3D-Modell der Basisstation in Altium Designer}
	\label{fig:3D}
\end{figure}

Die Fertigung der Platine durch den Hersteller erfolgte durch sogenannte Gerber Daten, die ebenfalls aus dem Output-Job-Manager generiert wurden. Dabei wird für jedes Layer des \ac{PCB}-Editors eine Gerberdatei erstellt, in der die Geometrie der entsprechenden Lage angegeben ist. Jede Lage entspricht dabei in der Herstellung einem Fertigungsschritt. Um Bohrungen in der Platine zu setzen, werden zusätzliche \enquote{NC Drill-Files}, also Daten für die \ac{NC} der automatischen Maschinen zum Setzen von Bohrungen, generiert. Diese enthalten den Bohrdurchmesser, die Art der Bohrung sowie den Ort auf der Platine und müssen zusätzlich aus Altium Designer exportiert werden. Solche Bohrungen sind sowohl für Vias als auch für Befestigungsbohrungen notwendig.

\section{Bestückung}
Die gefertigte Platine wurde vor der Programmierung mit den notwendigen Bauteilen bestückt. Dabei wurde zuerst der XMC4500 mit einer Bestückungsmaschine auf dem vorgesehenen Footprint der Platine verlötet. Im Folgenden wurden alle weiteren Bauteile sowie die sechs Transceiver mit Lötpaste auf der Platine befestigt und anschließend durch Erhitzen der Platine auf der Heizplatte verlötet. Das Kontaktieren durch die Heizplatte wurde in mehreren Schritten durchgeführt. Dabei wurden zunächst Bauteile einer guten Toleranz hoher Temperaturen wie Stecker und Widerstände bestückt. Temperaturanfällige Bauteile wie Leuchtdioden und integrierte Schaltkreise wurden nach Möglichkeit zu einem späteren Zeitpunkt befestigt. Wie bereits erwähnt wurde der Ethernet-Controller nicht bestückt.

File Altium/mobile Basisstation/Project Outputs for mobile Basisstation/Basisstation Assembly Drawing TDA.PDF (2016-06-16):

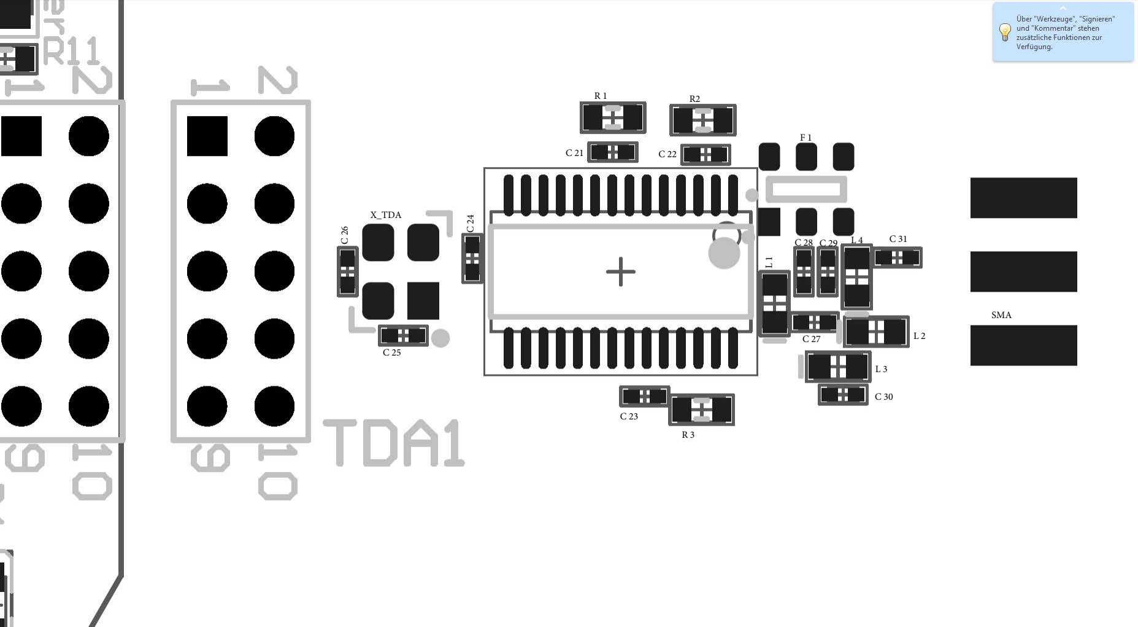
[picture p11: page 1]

C 26

C 25

X_TDA
C 24

C 23
R 3
R 1 | R2
C 21 | C 22

F 1

C 31

L 2

L 3

C 30

C 27

C 28 C 29

L 4

L 1

SMA

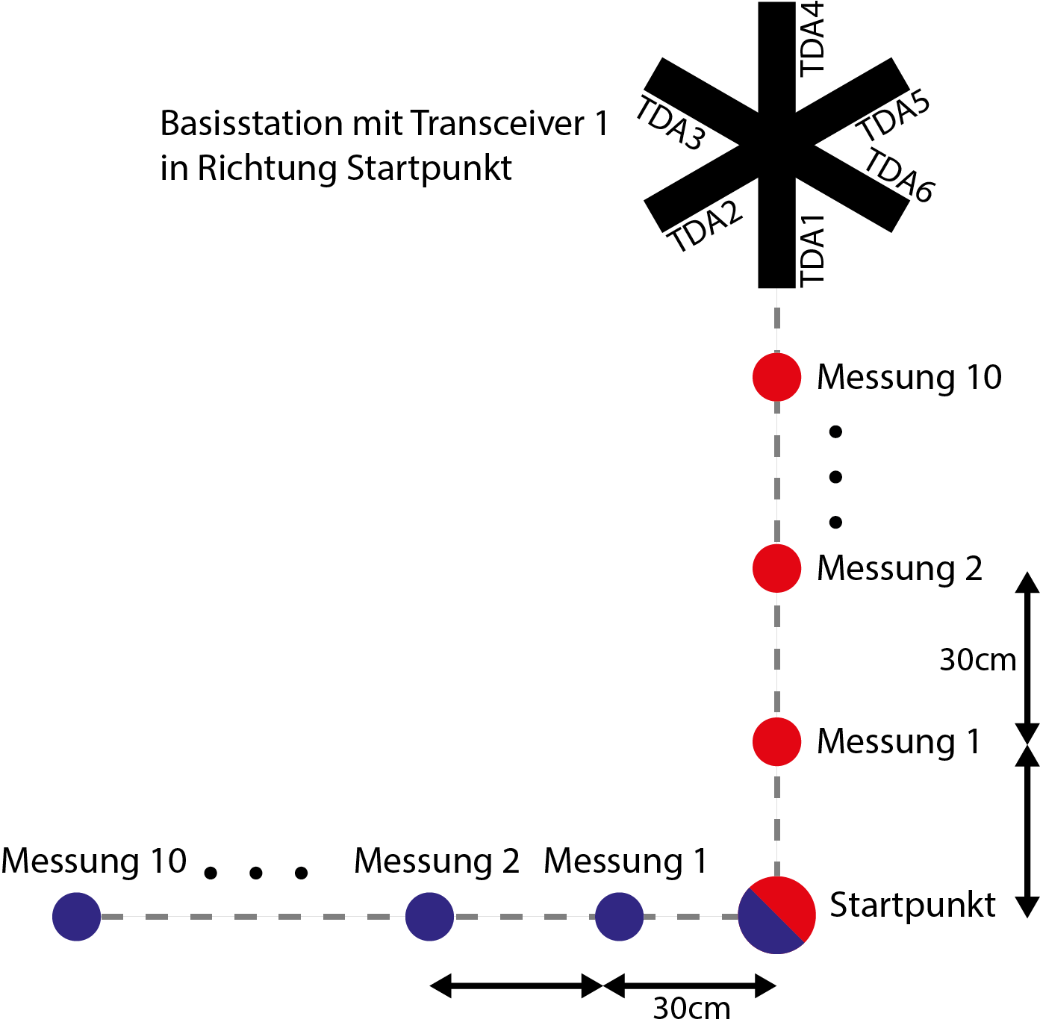
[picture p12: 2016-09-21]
Latex/Bachelorarbeit/Abbildungen/Aufbau Feldtest/Aufbau Feldtest.png

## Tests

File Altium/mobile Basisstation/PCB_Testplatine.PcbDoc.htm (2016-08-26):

Altium Reporting Options

# File in Newer Format

Date | : | 24.08.2016
Time | : | 12:06:26
Filename | : | Y:\Documents\Uni\Fächer\Bachelorarbeit\Altium\mobile Basisstation\PCB_Testplatine.PcbDoc

Version | Warning
Release 10 | CAUTION - New Custom Grids and Guides were introduced. Be aware that your design might contain Custom Grids and Guides that cannot be read in previous versions.
Release 10 | CAUTION - New Structured Clusters were introduced. Be aware that your design might contain Structured Clusters that cannot be read in previous versions.
Release 10 | CAUTION - New PCB 3D Movie Manager was introduced. Be aware that your design might contain 3D PCB movie that cannot be read in previous versions.
Release 10 update 1 | CAUTION - New Clearance Rule subscopes targeting differential pairs were introduced. Be aware that your design might contain Clearance Rules using those subscopes that cannot be read in previous versions.
Release 10 update 15 | CAUTION - Support of Solder Mask and Paste Mask expansions for Tracks, Arcs, Fills and Regions was introduced. Be aware that your design might contain Solder Mask and Paste Mask expansions for these types of primitives that cannot be read in the version of Altium Designer you are currently using.
Release 12 | CAUTION - Air Gap Width previously controlled by Clearance rule is now controlled by Polygon Connect Style rule's newly introduced Air Gap Width (set to default value). Suggest reviewing each Polygon Connect Style rule's Air Gap Width attribute for correctness.
Release 13 | CAUTION - Silk To Solder Mask Clearance Rules are converted to Silkscreen Over Component Pads Rules.
Release 14 | CAUTION - The Differential Pairs Routing rule added support for control of the width. Be aware that these widths must be manually entered as Width rules in this version.
Release 15 | CAUTION - Support of separate solder masks for top & bottom of pads added.
Release 15.1 | CAUTION - Support Multi-line PCB Text added.
Release 16.0 | CAUTION - Pad/Via hole size tolerance value added.

This file was generated by a later version of the software

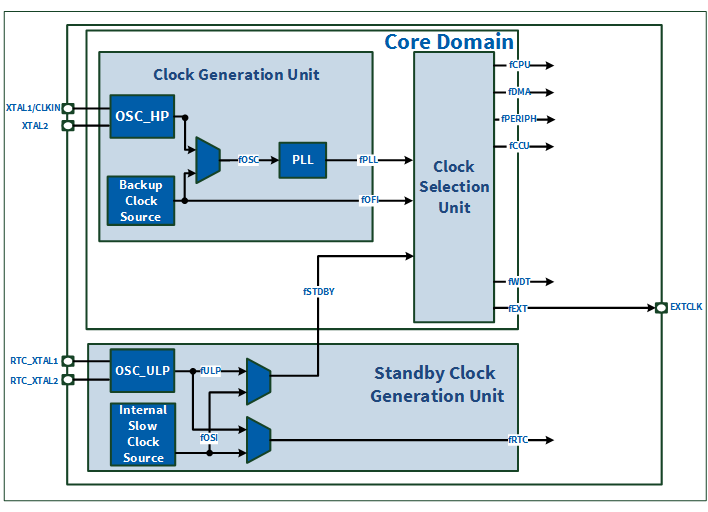
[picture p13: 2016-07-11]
Dave/Basisstation/TDA_XMC4500_PMA_testtrans/Dave/Model/APPS/CLOCK_XMC4/v4_0_6/doc/ClockTree_NO_USBPLL_USB_SDMMC_ETH_EBU.png

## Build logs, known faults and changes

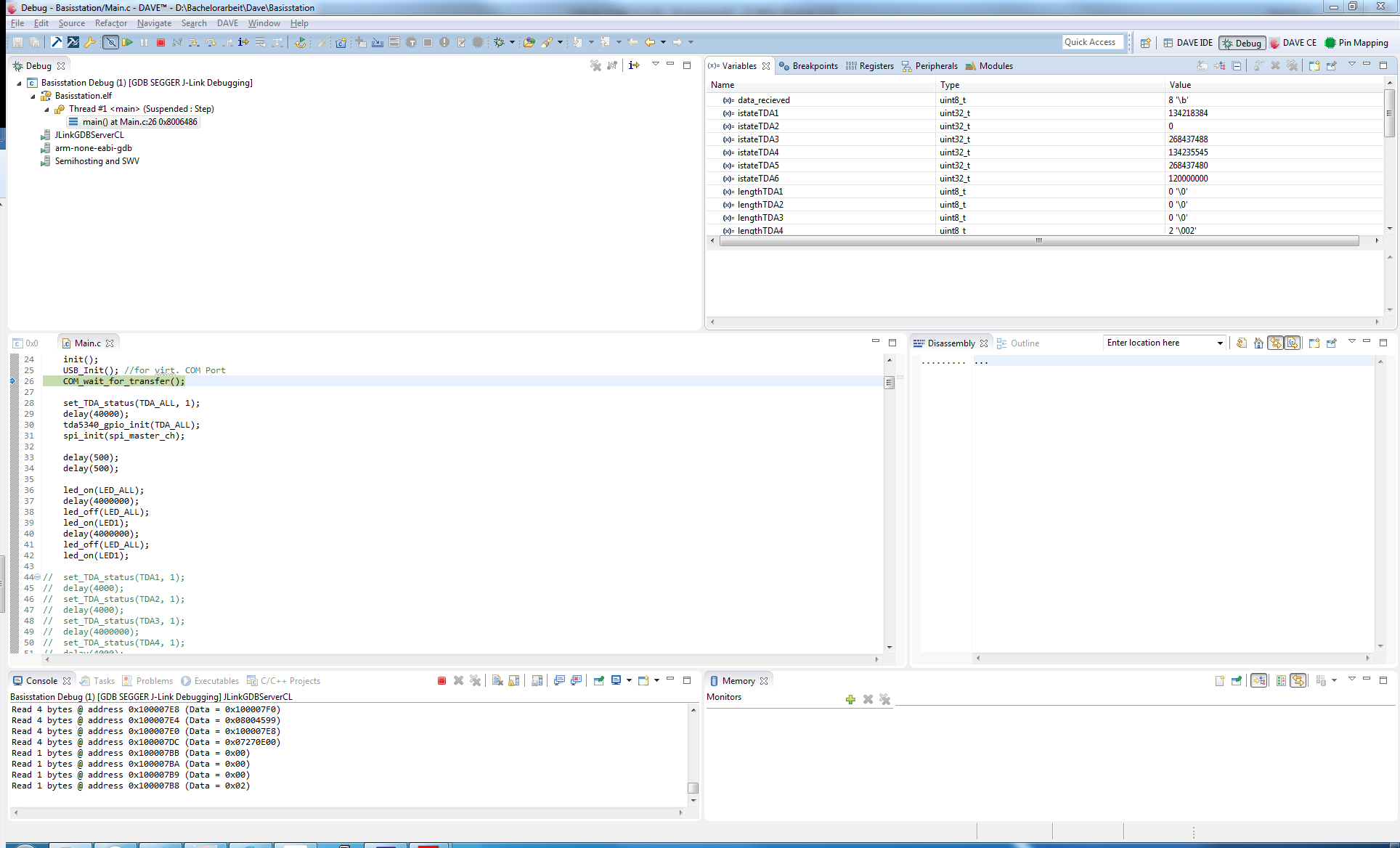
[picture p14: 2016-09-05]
Latex/Bachelorarbeit/Abbildungen/Aufnahmen/Bilder/Dave/Dave Debugg.PNG

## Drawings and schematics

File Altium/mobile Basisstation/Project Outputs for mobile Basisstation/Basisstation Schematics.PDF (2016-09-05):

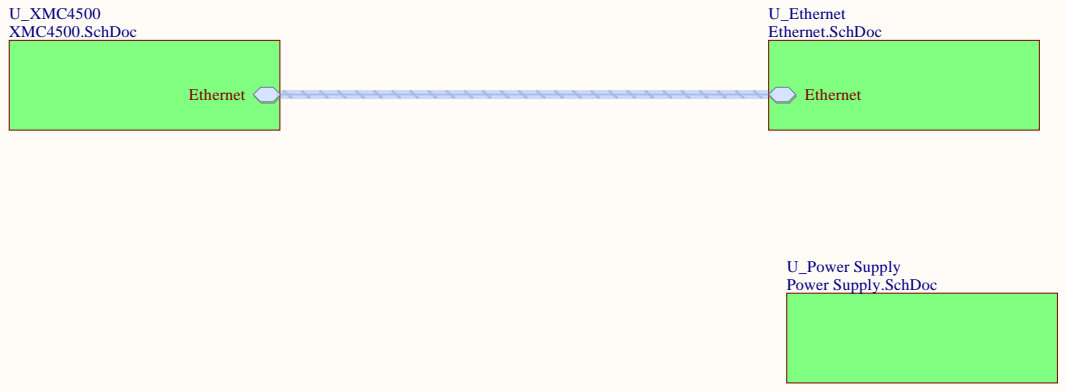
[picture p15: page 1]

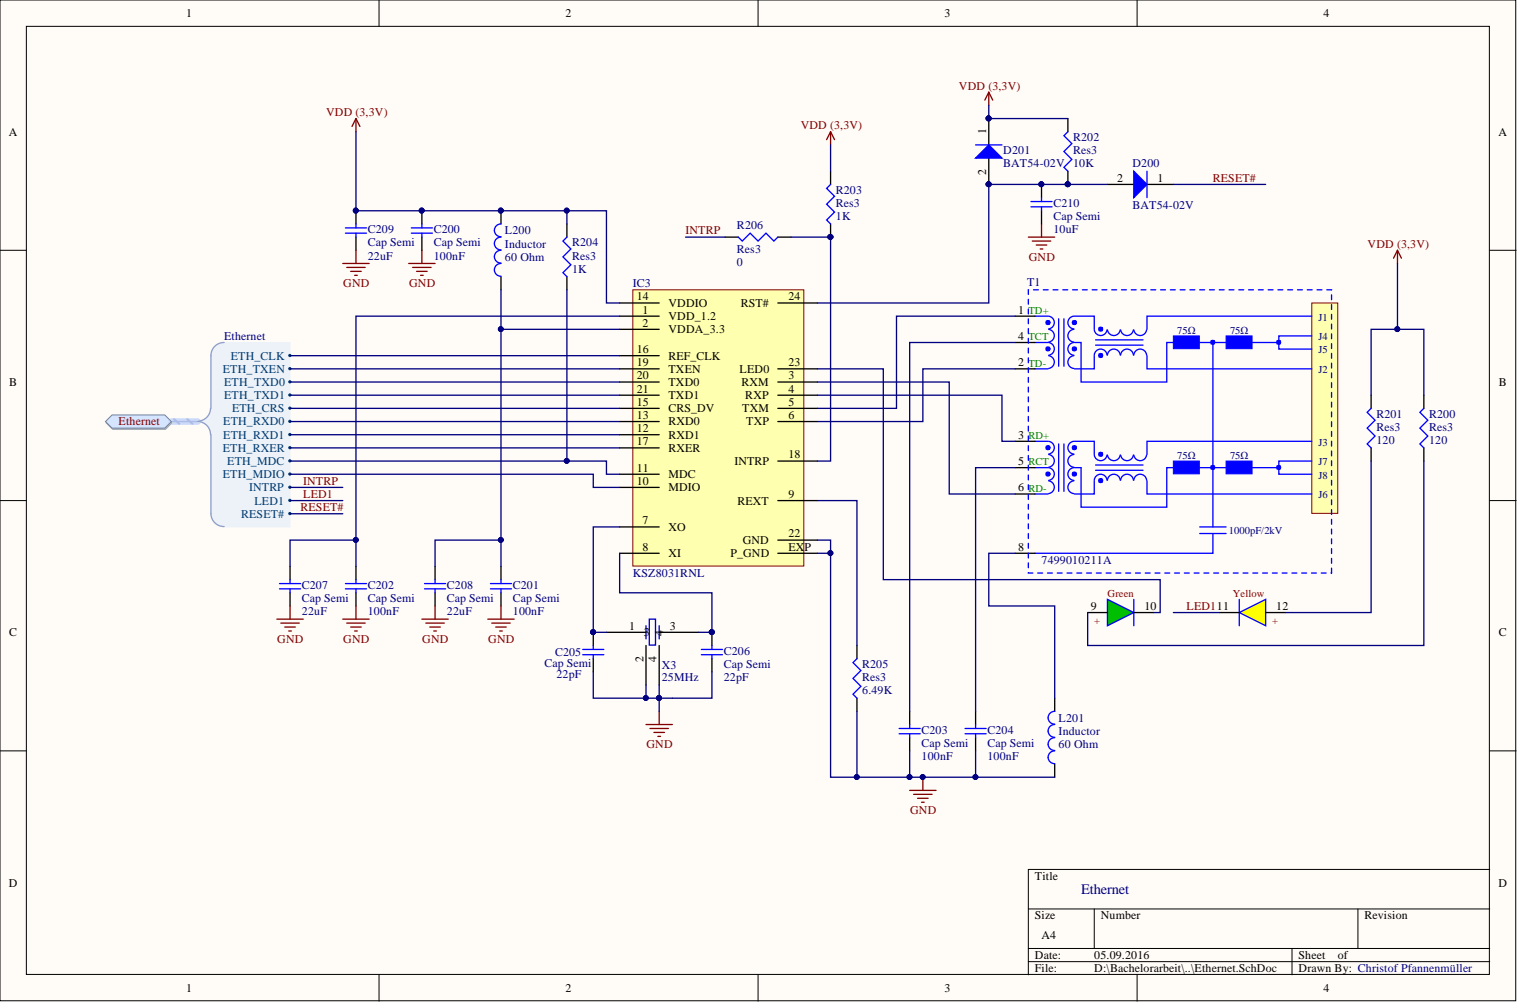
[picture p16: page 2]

REF_CLK 16
TXEN 19
TXD0 20
TXD1 21
CRS_DV 15
RXD1 12 RXD0 13

RXER 17

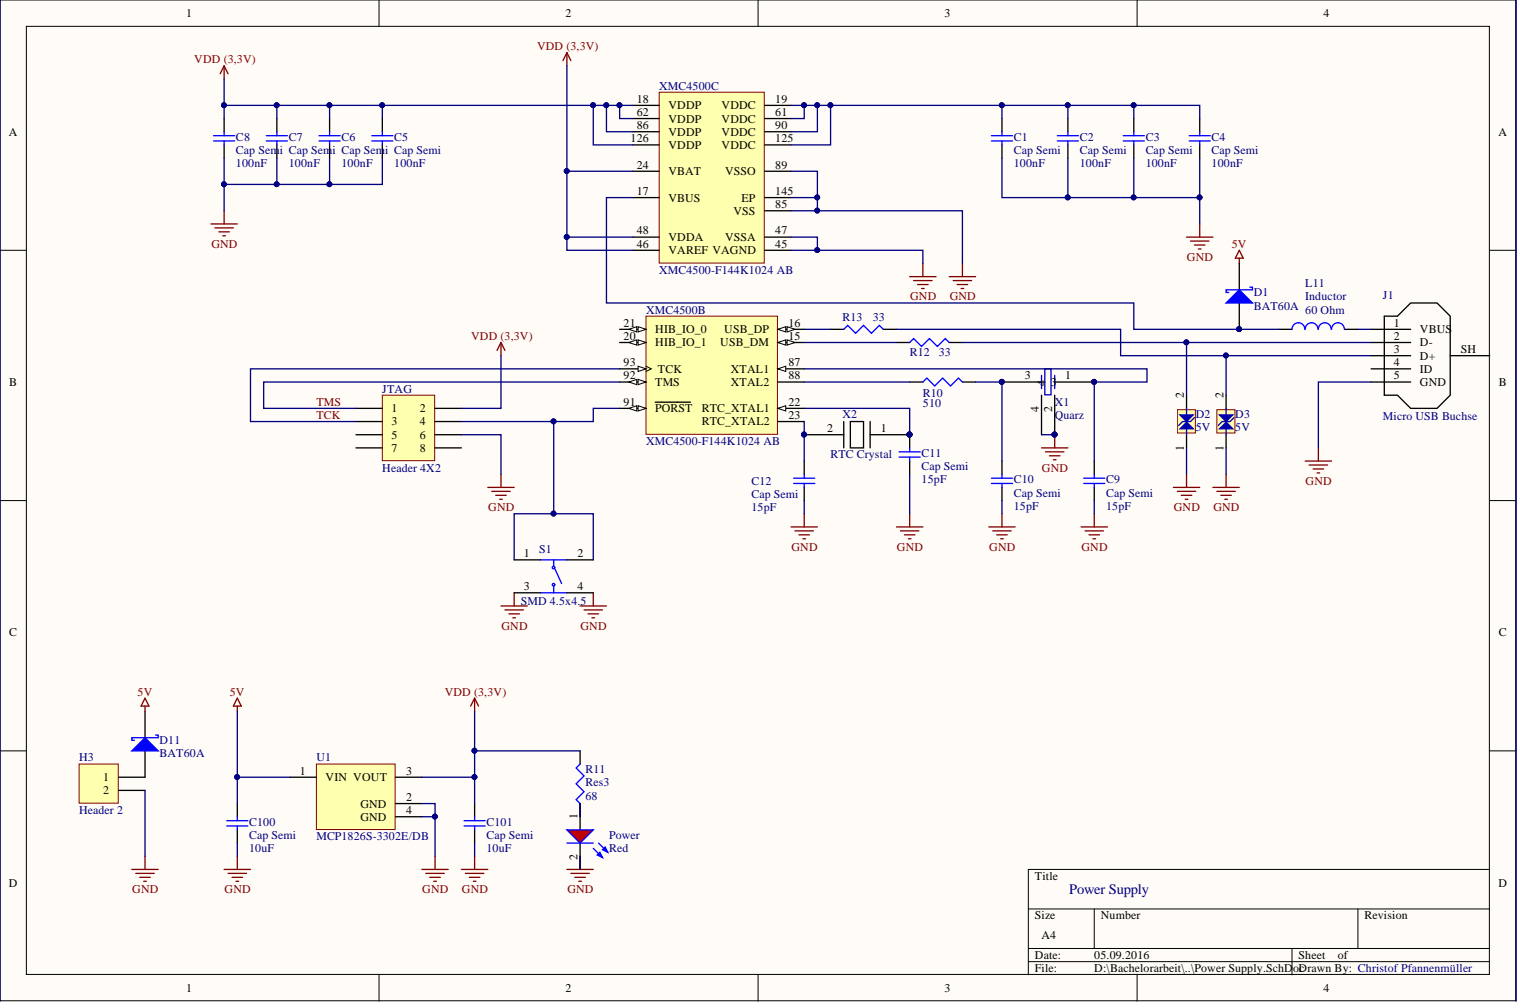
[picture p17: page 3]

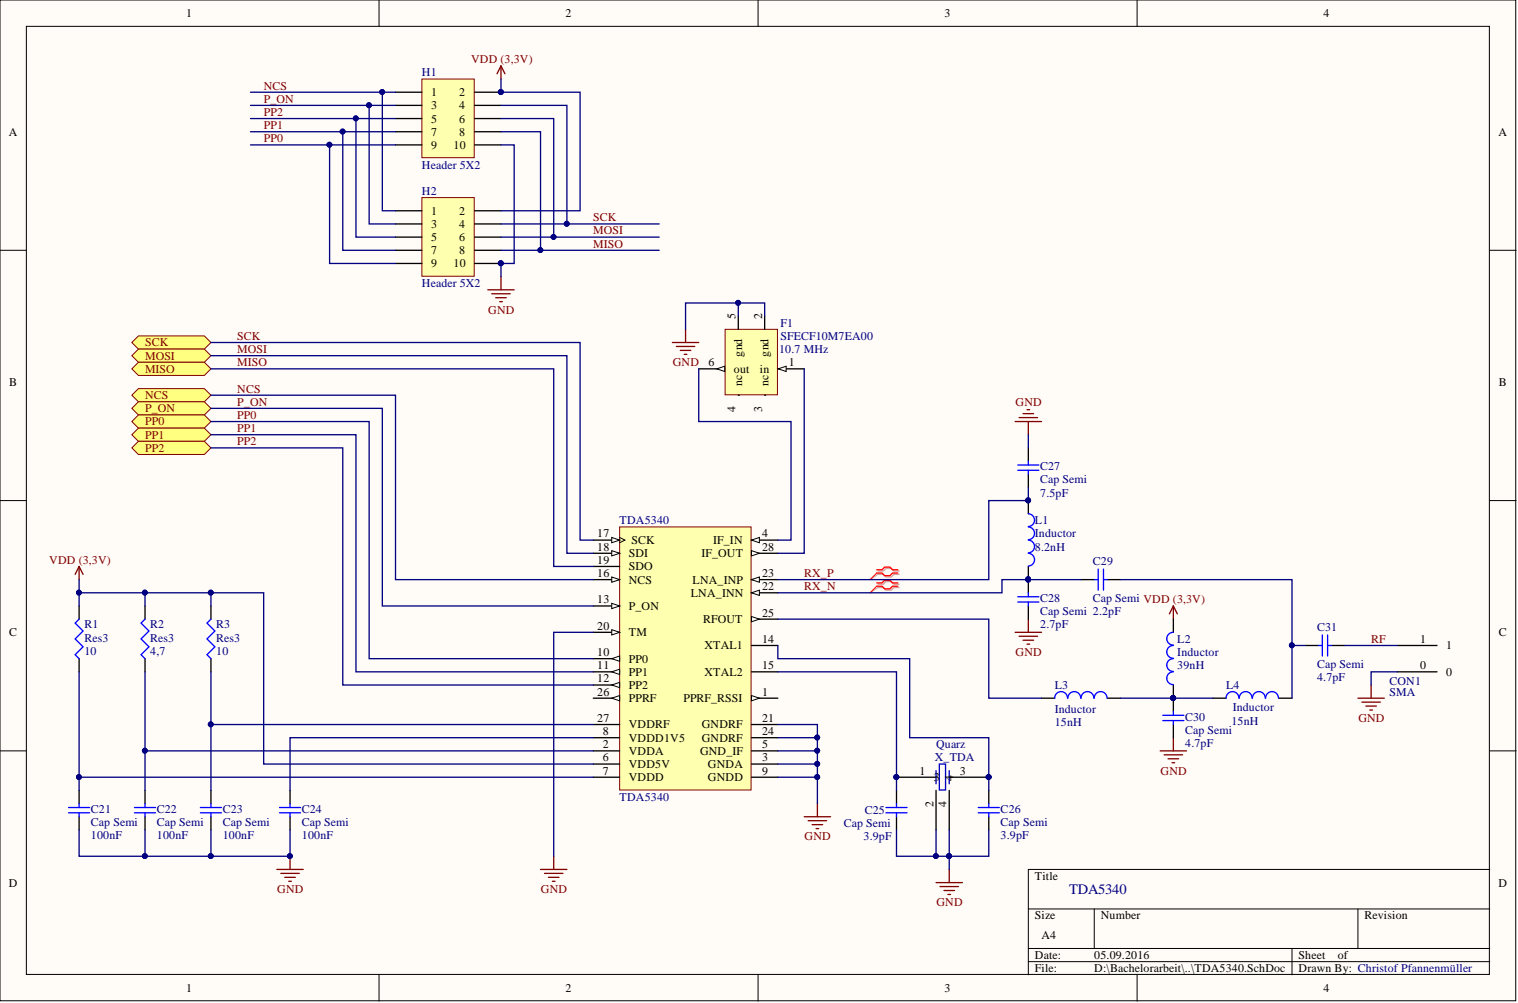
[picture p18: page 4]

NCS 16
P_ON 13 | RX_N | Cap Semi | VDD (3,3V) L2 Inductor 39nH

R3 Res3 10 | | TM 20

PPRF 26

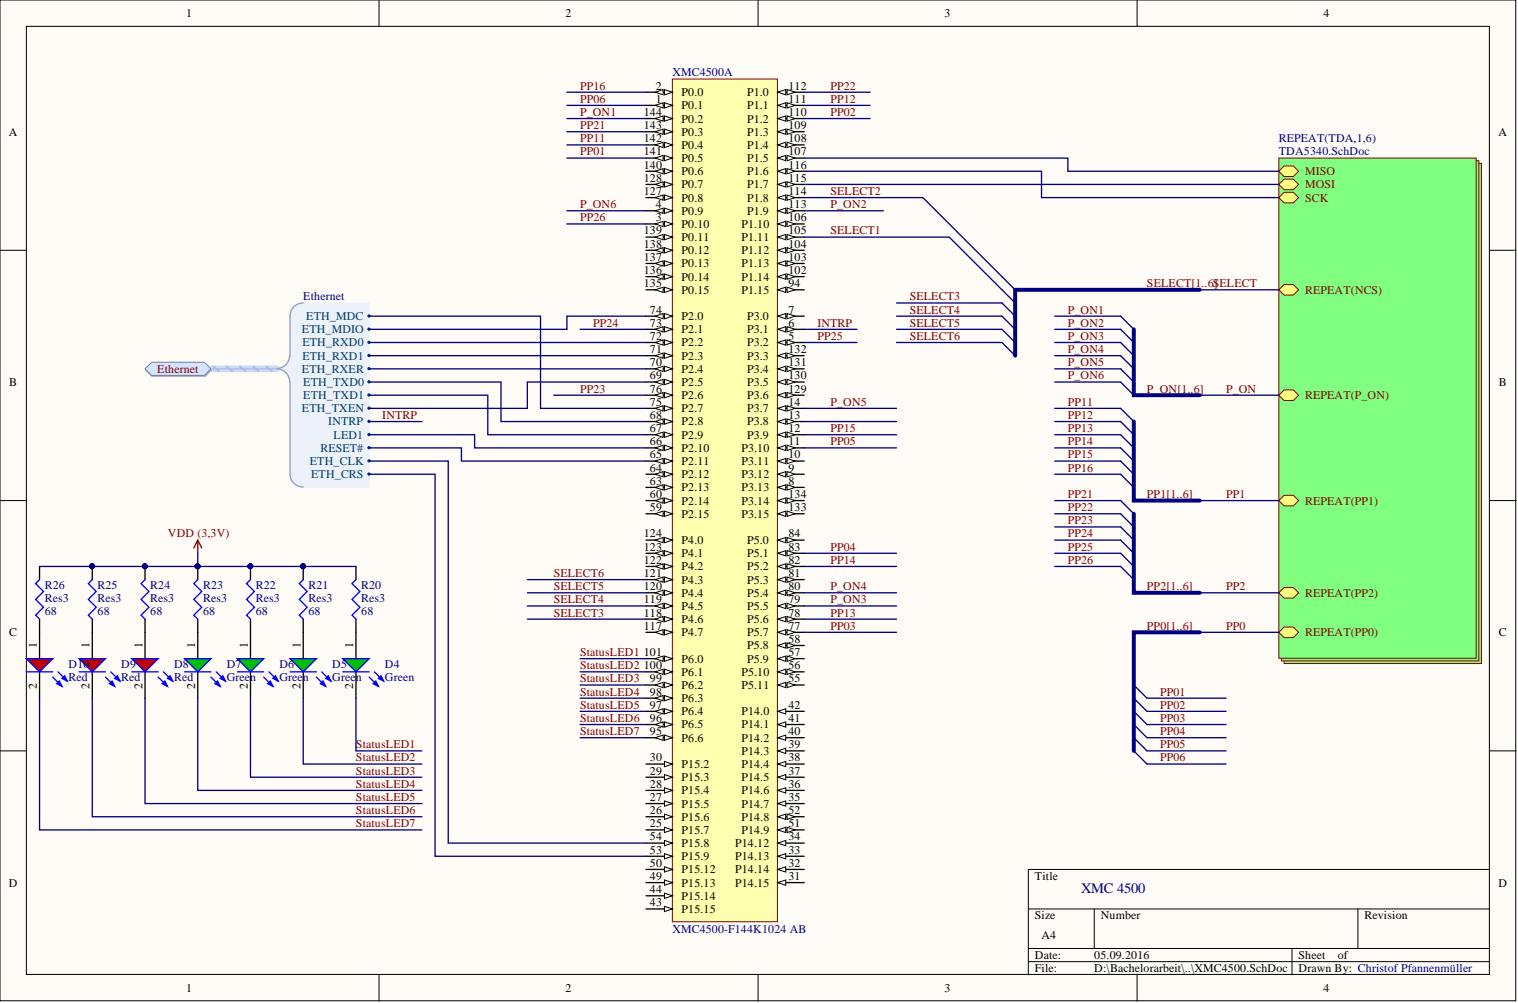
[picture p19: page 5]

SE L ECT 2

IN TRP | 6 8

0 3 8 D 4 Green | 6

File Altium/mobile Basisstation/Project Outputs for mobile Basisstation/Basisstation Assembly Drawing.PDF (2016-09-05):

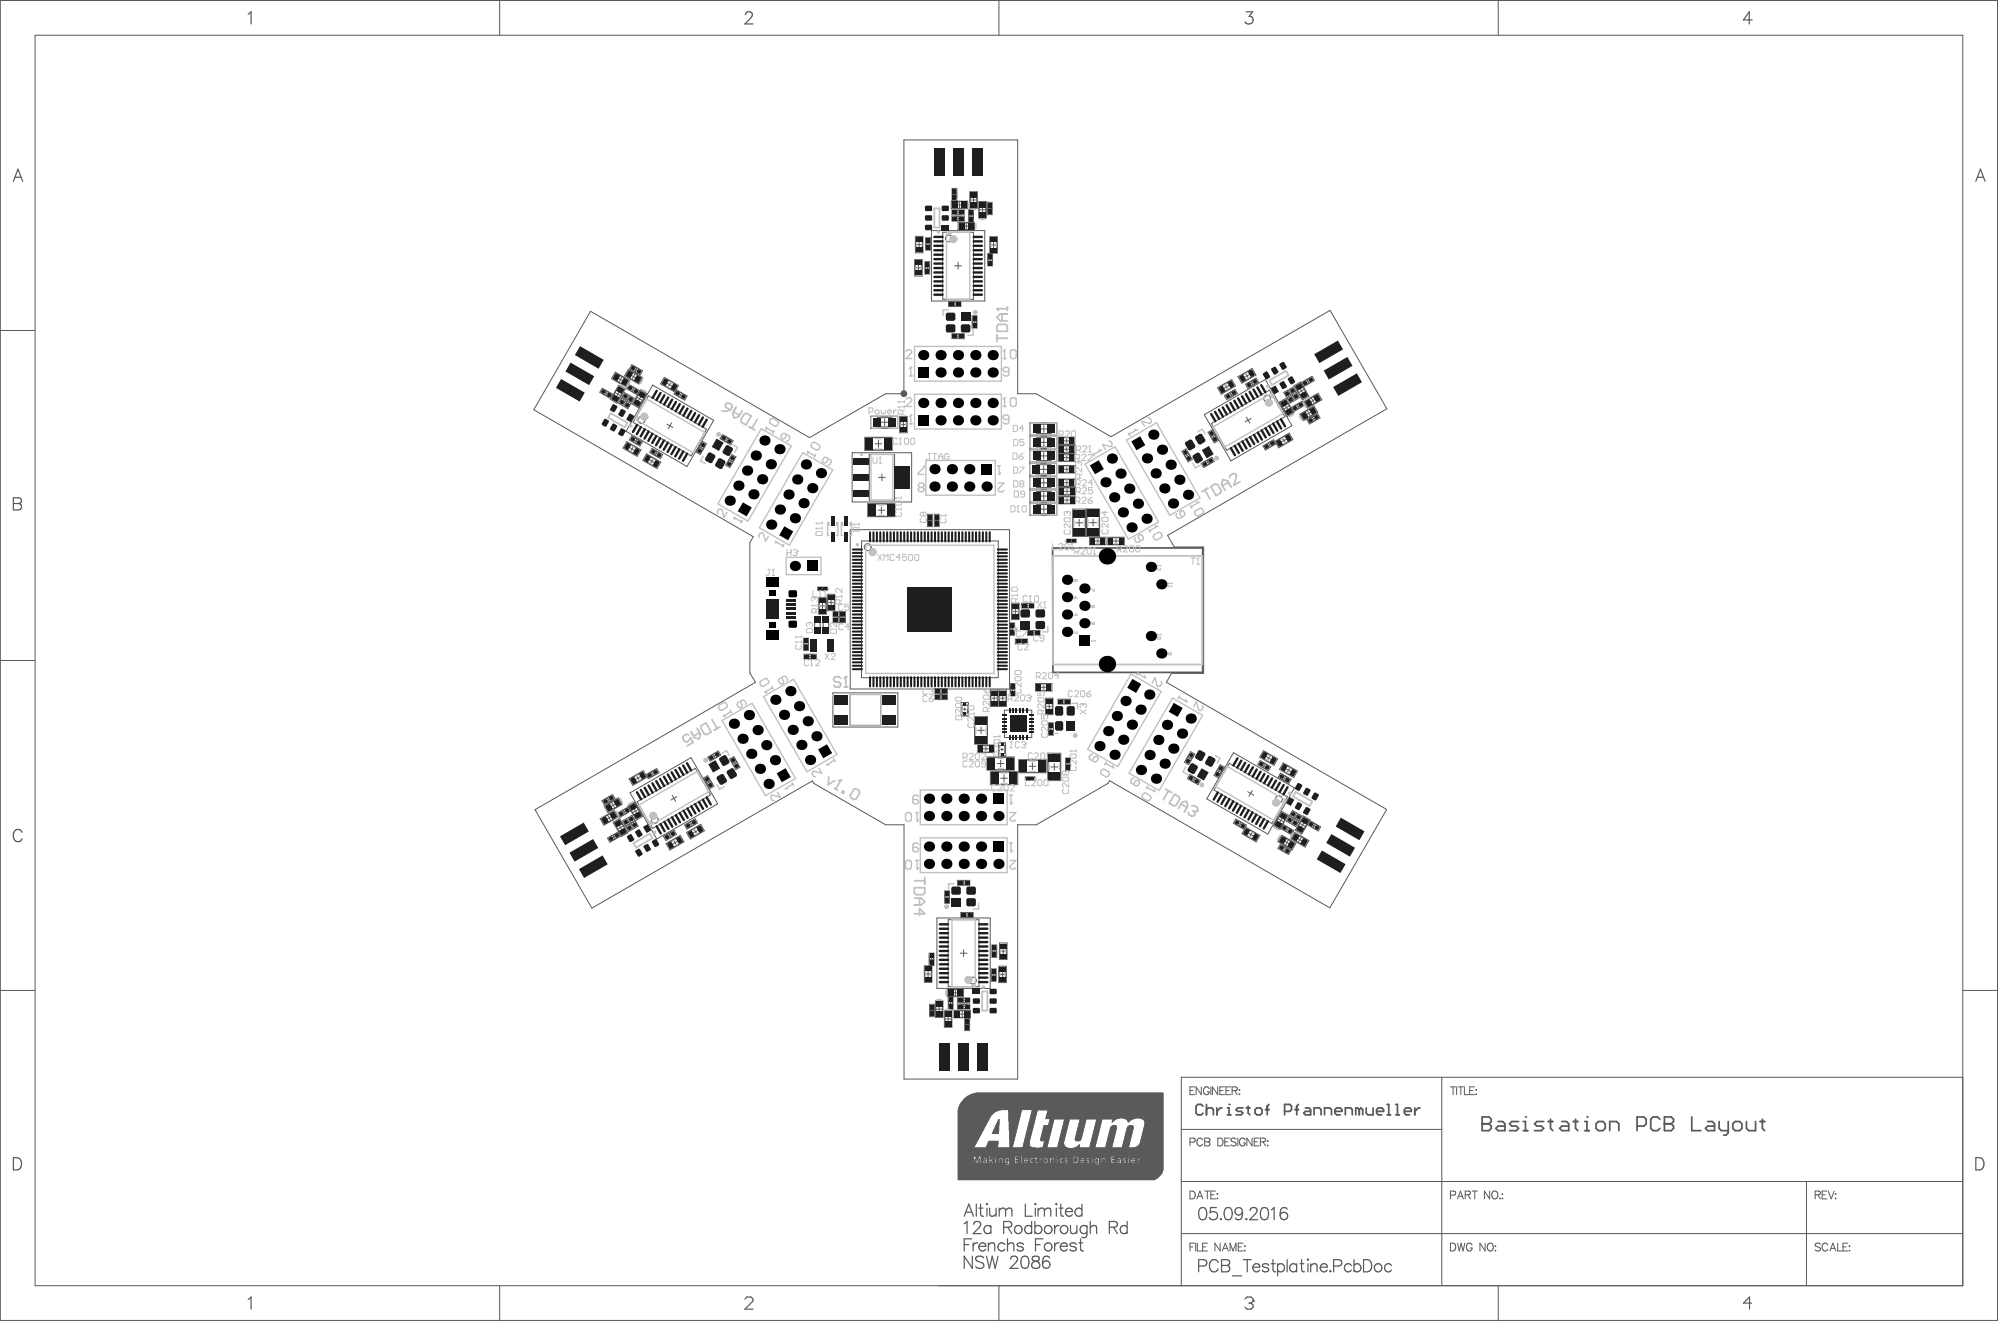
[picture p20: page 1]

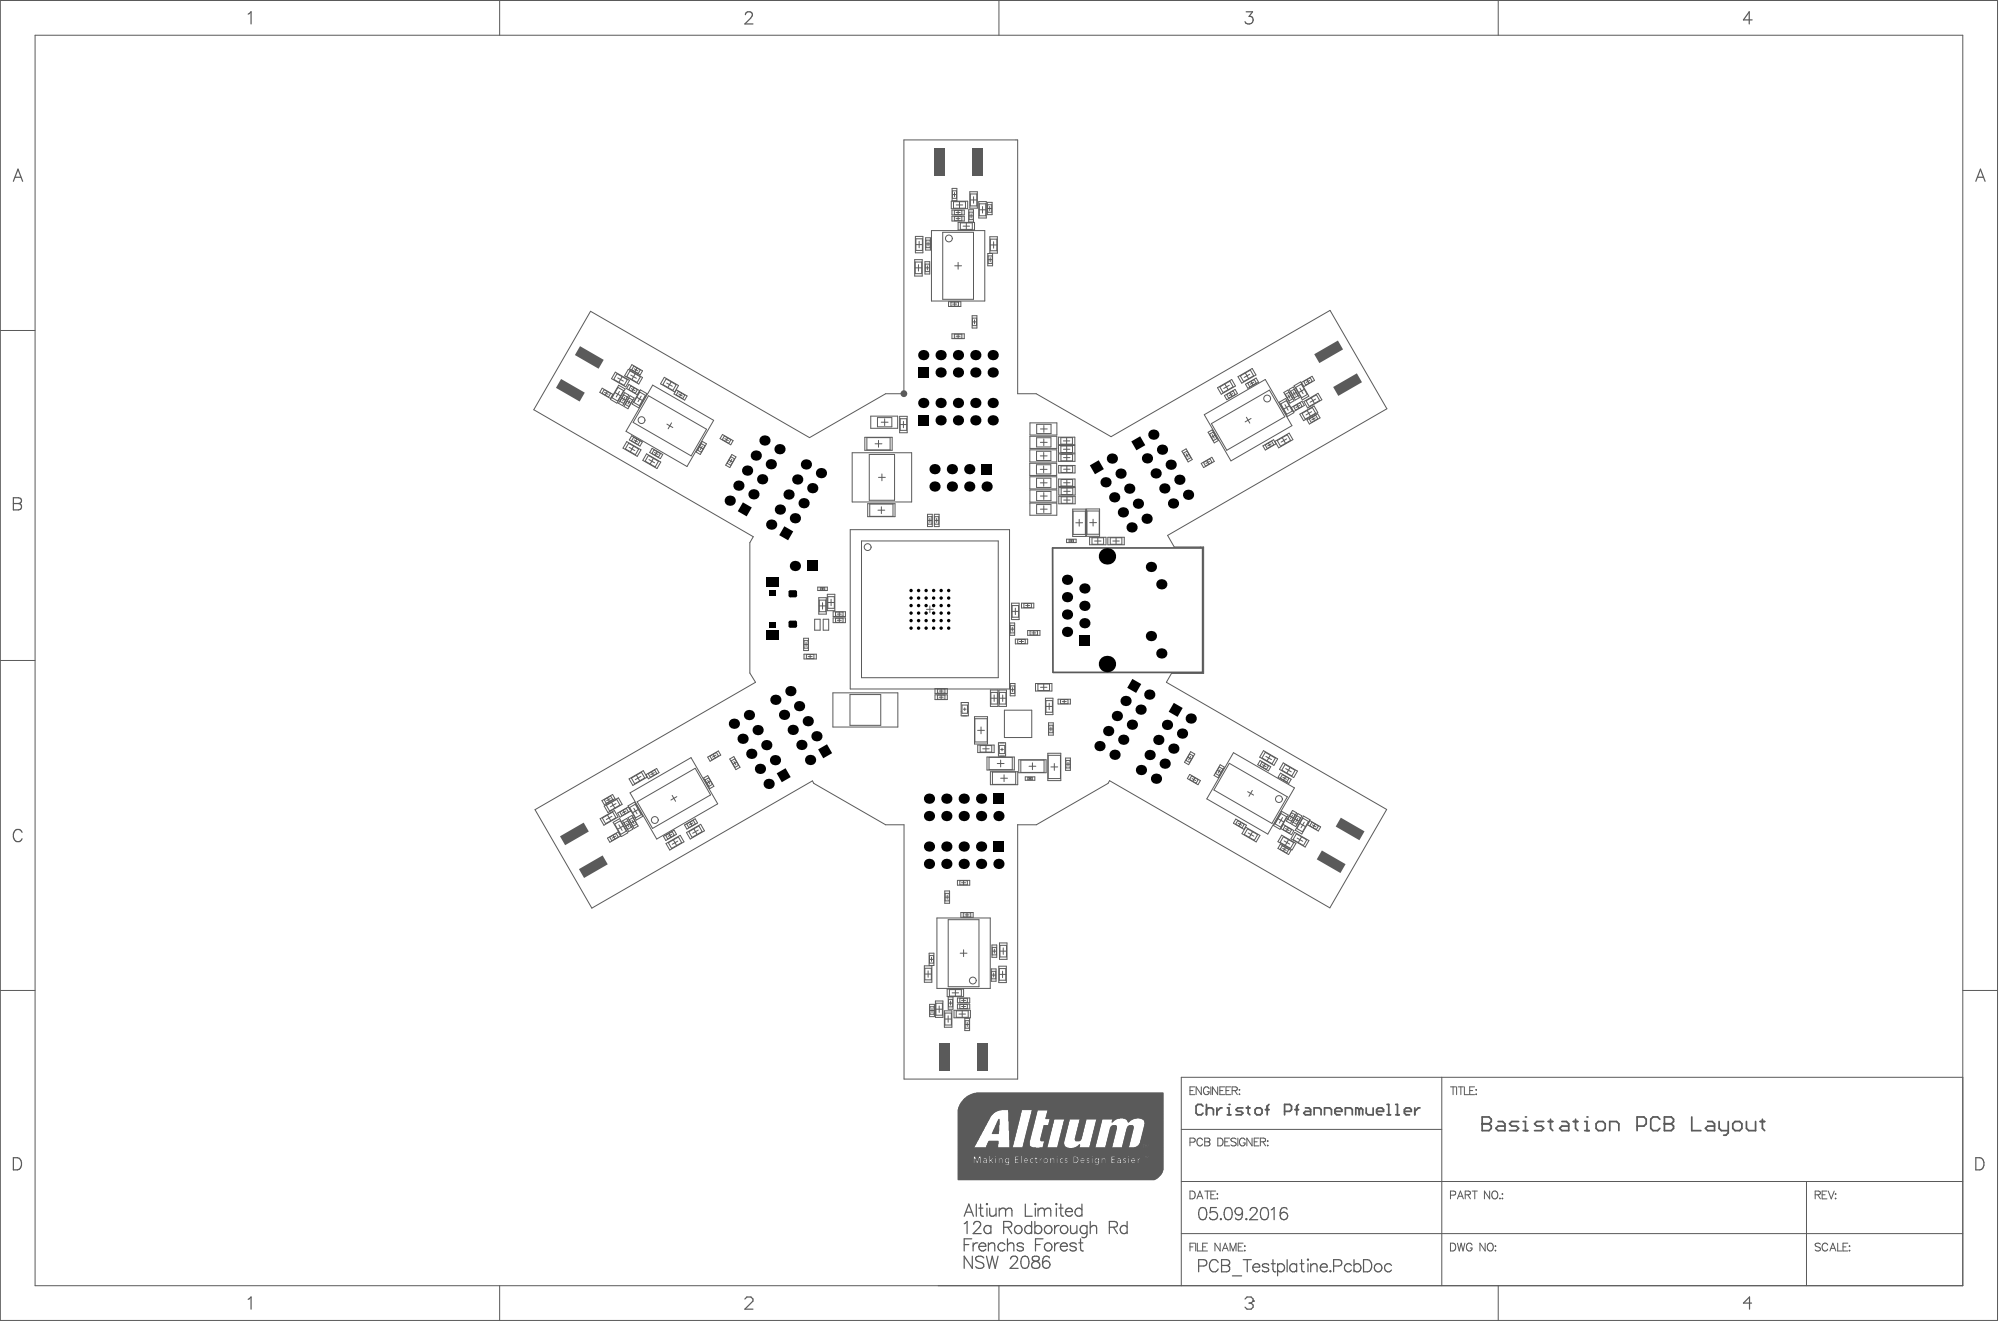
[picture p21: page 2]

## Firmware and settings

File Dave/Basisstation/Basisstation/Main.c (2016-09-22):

/*
 * Main.c
 *
 *  Created on: Jun 13, 2016
 *      Author: Christof Pfannenmüller
 */
#include "Header_general.h" //including all Header files

// Global variables
uint8_t query_interruptTDA1_flag = 0;
uint8_t query_interruptTDA2_flag = 0;
uint8_t query_interruptTDA3_flag = 0;
uint8_t query_interruptTDA4_flag = 0;
uint8_t query_interruptTDA5_flag = 0;
uint8_t query_interruptTDA6_flag = 0;

int16_t dig_to_dbm(uint8_t dig, uint8_t agc) {
	int32_t dbm_val = (712L * dig - 231628L + 3289L * agc) / 2048UL;
	return (int16_t) dbm_val;
}

int main(void) {

	init();
	USB_Init(); //for virt. COM Port
	COM_wait_for_transfer();

	set_TDA_status(TDA_ALL, 1);
	delay(40000);
	tda5340_gpio_init(TDA_ALL);
	spi_init(spi_master_ch);

	delay(1000);


	led_on(LED_ALL);
	delay(4000000);
	led_off(LED_ALL);
	led_on(LED1);
	delay(4000000);
	led_off(LED_ALL);
	led_on(LED1);   //greet user


	delay(40000);
	tda5340_init(TDA1); //Verzoegerung nach set_TDA_status bis TDA in Sleepmode
	tda5340_set_mode_and_config(TDA1, RX_MODE, 0);

	delay(40000);

	//für gesamte Platine:
	tda5340_init(TDA2);
	tda5340_set_mode_and_config(TDA2, RX_MODE, 0);
	tda5340_init(TDA3);
	tda5340_set_mode_and_config(TDA3, RX_MODE, 0);
	tda5340_init(TDA4);
	tda5340_set_mode_and_config(TDA4, RX_MODE, 0);
	tda5340_init(TDA5);
	tda5340_set_mode_and_config(TDA5, RX_MODE, 0);
	tda5340_init(TDA6);
	tda5340_set_mode_and_config(TDA6, RX_MODE, 0);

//	Ablaufschleife START++++++++++++++++++++++++++++++++++++++++++++++++++++++++++++++++++++++++++
	COM_send_string("Initialisierung beendet - ");
	uint8_t data_recieved = 0;
	uint32_t istateTDA1 = 0, istateTDA2 = 0, istateTDA3 = 0, istateTDA4 = 0, istateTDA5 = 0, istateTDA6 = 0;
	uint8_t lengthTDA1 = 0, lengthTDA2 = 0, lengthTDA3 = 0, lengthTDA4 = 0, lengthTDA5 = 0, lengthTDA6 = 0;
	uint32_t transfernumber = 0;
	uint32_t led_ctr = 0;
	char rx_data_TDA1[36] = { 1, 0, 3, 0, 5, 6, 7, 8, 9 };// wurde so initialisiert damit auffällt wenn keine neuen Messwerte eingetragen werden
	char rx_data_TDA2[36] = { 1, 0, 3, 0, 5, 6, 7, 8, 9 };
	char rx_data_TDA3[36] = { 1, 0, 3, 0, 5, 6, 7, 8, 9 };
	char rx_data_TDA4[36] = { 1, 0, 3, 0, 5, 6, 7, 8, 9 };
	char rx_data_TDA5[36] = { 1, 0, 3, 0, 5, 6, 7, 8, 9 };
	char rx_data_TDA6[36] = { 1, 0, 3, 0, 5, 6, 7, 8, 9 };
	struct rssi {
		uint8_t pmf;
		uint8_t prx;
		uint8_t rx;
		uint8_t ppl;
		uint8_t agc;
	};

	struct rssi rssiTDA1 = { .pmf = 0, .prx = 0, .rx = 0, .ppl = 0, .agc = 0 };
	struct rssi rssiTDA2 = { .pmf = 0, .prx = 0, .rx = 0, .ppl = 0, .agc = 0 };
	struct rssi rssiTDA3 = { .pmf = 0, .prx = 0, .rx = 0, .ppl = 0, .agc = 0 };
	struct rssi rssiTDA4 = { .pmf = 0, .prx = 0, .rx = 0, .ppl = 0, .agc = 0 };
	struct rssi rssiTDA5 = { .pmf = 0, .prx = 0, .rx = 0, .ppl = 0, .agc = 0 };
	struct rssi rssiTDA6 = { .pmf = 0, .prx = 0, .rx = 0, .ppl = 0, .agc = 0 };

	query_interruptTDA1_flag = 0;
	query_interruptTDA2_flag = 0;
	query_interruptTDA3_flag = 0;
	query_interruptTDA4_flag = 0;
	query_interruptTDA5_flag = 0;
	query_interruptTDA6_flag = 0;

//-----------------------------------------------------------------
	COM_send_string("Warte auf Übertragungen\r\n");
	while (1) {
		if (query_interruptTDA1_flag) {
			query_interruptTDA1_flag = 0;
			istateTDA1 = tda5340_interrupt_readout(TDA1);
		}
		if (query_interruptTDA2_flag) {
			query_interruptTDA2_flag = 0;
			istateTDA2 = tda5340_interrupt_readout(TDA2);
		}
		if (query_interruptTDA3_flag) {
			query_interruptTDA3_flag = 0;
			istateTDA3 = tda5340_interrupt_readout(TDA3);
		}
		if (query_interruptTDA4_flag) {
			query_interruptTDA4_flag = 0;
			istateTDA4 = tda5340_interrupt_readout(TDA4);
		}
		if (query_interruptTDA5_flag) {
			query_interruptTDA5_flag = 0;
			istateTDA5 = tda5340_interrupt_readout(TDA5);
		}
		if (query_interruptTDA6_flag) {
			query_interruptTDA6_flag = 0;
			led_on(LED3);
			istateTDA6 = tda5340_interrupt_readout(TDA6);
		}
//-----------------------------------------------------------------

		if (istateTDA1 & (1 << 1)) {
			rssiTDA1.pmf = tda5340_transfer(TDA1, READ_FROM_CHIP, RSSIPMF, 0xFF);
			rssiTDA1.rx = tda5340_transfer(TDA1, READ_FROM_CHIP, RSSIRX, 0xFF);
			rssiTDA1.agc = (tda5340_transfer(TDA1, READ_FROM_CHIP, AGCADRR, 0xFF) & 0x06) >> 1;
			istateTDA1 &= ~(1 << 1);
		}
		if (istateTDA2 & (1 << 1)) {
			rssiTDA2.pmf = tda5340_transfer(TDA2, READ_FROM_CHIP, RSSIPMF, 0xFF);
			rssiTDA2.rx = tda5340_transfer(TDA2, READ_FROM_CHIP, RSSIRX, 0xFF);
			rssiTDA2.agc = (tda5340_transfer(TDA2, READ_FROM_CHIP, AGCADRR, 0xFF) & 0x06) >> 1;
			istateTDA2 &= ~(1 << 1);
		}
		if (istateTDA3 & (1 << 1)) {
			rssiTDA3.pmf = tda5340_transfer(TDA3, READ_FROM_CHIP, RSSIPMF, 0xFF);
			rssiTDA3.rx = tda5340_transfer(TDA3, READ_FROM_CHIP, RSSIRX, 0xFF);
			rssiTDA3.agc = (tda5340_transfer(TDA3, READ_FROM_CHIP, AGCADRR, 0xFF) & 0x06) >> 1;
			istateTDA3 &= ~(1 << 1);
		}
		if (istateTDA4 & (1 << 1)) {
			rssiTDA4.pmf = tda5340_transfer(TDA4, READ_FROM_CHIP, RSSIPMF, 0xFF);
			rssiTDA4.rx = tda5340_transfer(TDA4, READ_FROM_CHIP, RSSIRX, 0xFF);
			rssiTDA4.agc = (tda5340_transfer(TDA4, READ_FROM_CHIP, AGCADRR, 0xFF) & 0x06) >> 1;
			istateTDA4 &= ~(1 << 1);
		}
		if (istateTDA5 & (1 << 1)) {
			rssiTDA5.pmf = tda5340_transfer(TDA5, READ_FROM_CHIP, RSSIPMF, 0xFF);
			rssiTDA5.rx = tda5340_transfer(TDA5, READ_FROM_CHIP, RSSIRX, 0xFF);
			rssiTDA5.agc = (tda5340_transfer(TDA5, READ_FROM_CHIP, AGCADRR, 0xFF) & 0x06) >> 1;
			istateTDA5 &= ~(1 << 1);
		}
		if (istateTDA6 & (1 << 1)) {
			rssiTDA6.pmf = tda5340_transfer(TDA6, READ_FROM_CHIP, RSSIPMF, 0xFF);
			rssiTDA6.rx = tda5340_transfer(TDA6, READ_FROM_CHIP, RSSIRX, 0xFF);
			rssiTDA6.agc = (tda5340_transfer(TDA6, READ_FROM_CHIP, AGCADRR, 0xFF) & 0x06) >> 1;
			istateTDA6 &= ~(1 << 1);
		}
//-----------------------------------------------------------------
		if (istateTDA1 & (1 << 3)) {

			rssiTDA1.prx = tda5340_transfer(TDA1, READ_FROM_CHIP, RSSIPRX, 0xFF);
			rssiTDA1.ppl = tda5340_transfer(TDA1, READ_FROM_CHIP, RSSIPPL, 0xFF);
			tda5340_set_mode_and_config(TDA1, SLEEP_MODE, 0);
			if (!tda5340_receive(TDA1, rx_data_TDA1, &lengthTDA1)) {
				if (lengthTDA1 > 32)
					lengthTDA1 = 32;
			}
			tda5340_set_mode_and_config(TDA1, RX_MODE, 0);
			data_recieved = 1;
			istateTDA1 &= ~(1 << 3);
		}
		if (istateTDA2 & (1 << 3)) {

			rssiTDA2.prx = tda5340_transfer(TDA2, READ_FROM_CHIP, RSSIPRX, 0xFF);
			rssiTDA2.ppl = tda5340_transfer(TDA2, READ_FROM_CHIP, RSSIPPL, 0xFF);
			tda5340_set_mode_and_config(TDA2, SLEEP_MODE, 0);
			if (!tda5340_receive(TDA2, rx_data_TDA2, &lengthTDA2)) {
				if (lengthTDA2 > 32)
					lengthTDA2 = 32;
			}
			tda5340_set_mode_and_config(TDA2, RX_MODE, 0);
			data_recieved = 1;
			istateTDA2 &= ~(1 << 3);
		}
		if (istateTDA3 & (1 << 3)) {

			rssiTDA3.prx = tda5340_transfer(TDA3, READ_FROM_CHIP, RSSIPRX, 0xFF);
			rssiTDA3.ppl = tda5340_transfer(TDA3, READ_FROM_CHIP, RSSIPPL, 0xFF);
			tda5340_set_mode_and_config(TDA3, SLEEP_MODE, 0);
			if (!tda5340_receive(TDA3, rx_data_TDA3, &lengthTDA3)) {
				if (lengthTDA3 > 32)
					lengthTDA3 = 32;
			}
			tda5340_set_mode_and_config(TDA3, RX_MODE, 0);
			data_recieved = 1;
			istateTDA3 &= ~(1 << 3);
		}
		if (istateTDA4 & (1 << 3)) {

			rssiTDA4.prx = tda5340_transfer(TDA4, READ_FROM_CHIP, RSSIPRX, 0xFF);
			rssiTDA4.ppl = tda5340_transfer(TDA4, READ_FROM_CHIP, RSSIPPL, 0xFF);
			tda5340_set_mode_and_config(TDA4, SLEEP_MODE, 0);
			if (!tda5340_receive(TDA4, rx_data_TDA4, &lengthTDA4)) {
				if (lengthTDA4 > 32)
					lengthTDA4 = 32;
			}
			tda5340_set_mode_and_config(TDA4, RX_MODE, 0);
			data_recieved = 1;
			istateTDA4 &= ~(1 << 3);
		}
		if (istateTDA5 & (1 << 3)) {

			rssiTDA5.prx = tda5340_transfer(TDA5, READ_FROM_CHIP, RSSIPRX, 0xFF);
			rssiTDA5.ppl = tda5340_transfer(TDA5, READ_FROM_CHIP, RSSIPPL, 0xFF);
			tda5340_set_mode_and_config(TDA5, SLEEP_MODE, 0);
			if (!tda5340_receive(TDA5, rx_data_TDA5, &lengthTDA5)) {
				if (lengthTDA5 > 32)
					lengthTDA5 = 32;
			}
			tda5340_set_mode_and_config(TDA5, RX_MODE, 0);
			data_recieved = 1;
			istateTDA5 &= ~(1 << 3);
		}
		if (istateTDA6 & (1 << 3)) {

			rssiTDA6.prx = tda5340_transfer(TDA6, READ_FROM_CHIP, RSSIPRX, 0xFF);
			rssiTDA6.ppl = tda5340_transfer(TDA6, READ_FROM_CHIP, RSSIPPL, 0xFF);
			tda5340_set_mode_and_config(TDA6, SLEEP_MODE, 0);
			if (!tda5340_receive(TDA6, rx_data_TDA6, &lengthTDA6)) {
				if (lengthTDA6 > 32)
					lengthTDA6 = 32;
			}
			tda5340_set_mode_and_config(TDA6, RX_MODE, 0);
			data_recieved = 1;
			istateTDA6 &= ~(1 << 3);
		}
//-----------------------------------------------------------------
		//send to COM
		if (data_recieved) {
			transfernumber++;
			COM_send_string("#################### Übertragung erkannt ####################\r\n");
			COM_send_string("Übertragung Nummer ");
			COM_send_int_as_string(transfernumber);
			COM_send_string("\r\n\r\n");
			COM_send_string("TDA1:");
			COM_send_string("\r\nPMF:");
			COM_send_int_as_string(rssiTDA1.pmf);
			COM_send_string("\r\nPRX:");
			COM_send_int_as_string(rssiTDA1.prx);
			COM_send_string("\r\nRX:");
			COM_send_int_as_string(rssiTDA1.rx);
			COM_send_string("\r\nPPL:");
			COM_send_int_as_string(rssiTDA1.ppl);
			COM_send_string("\r\nAGC:");
			COM_send_int_as_string(rssiTDA1.agc);
			COM_send_string("\r\nEmpfangsleistung (dBm):");
			if (dig_to_dbm(rssiTDA1.ppl, rssiTDA1.agc) < 0) {
				COM_send_string("-");
			}
			COM_send_int_as_string(abs(dig_to_dbm(rssiTDA1.ppl, rssiTDA1.agc)));
			COM_send_string("\r\n");
			COM_send_string("Empfangene Daten:");
			for (int i = 0; i <= lengthTDA1; ++i) {
				COM_send_int_as_string(rx_data_TDA1[i]);

			}
			COM_send_string("\r\n\r\n");

			COM_send_string("TDA2:");
			COM_send_string("\r\nPMF:");
			COM_send_int_as_string(rssiTDA2.pmf);
			COM_send_string("\r\nPRX:");
			COM_send_int_as_string(rssiTDA2.prx);
			COM_send_string("\r\nRX:");
			COM_send_int_as_string(rssiTDA2.rx);
			COM_send_string("\r\nPPL:");
			COM_send_int_as_string(rssiTDA2.ppl);
			COM_send_string("\r\nAGC:");
			COM_send_int_as_string(rssiTDA2.agc);
			COM_send_string("\r\nEmpfangsleistung (dBm):");
			if (dig_to_dbm(rssiTDA2.ppl, rssiTDA2.agc) < 0) {
				COM_send_string("-");
			}
			COM_send_int_as_string(abs(dig_to_dbm(rssiTDA2.ppl, rssiTDA2.agc)));
			COM_send_string("\r\n");
			COM_send_string("Empfangene Daten:");
			for (int i = 0; i <= lengthTDA2; ++i) {
				COM_send_int_as_string(rx_data_TDA2[i]);

			}
			COM_send_string("\r\n\r\n");

			COM_send_string("TDA3:");
			COM_send_string("\r\nPMF:");
			COM_send_int_as_string(rssiTDA3.pmf);
			COM_send_string("\r\nPRX:");
			COM_send_int_as_string(rssiTDA3.prx);
			COM_send_string("\r\nRX:");
			COM_send_int_as_string(rssiTDA3.rx);
			COM_send_string("\r\nPPL:");
			COM_send_int_as_string(rssiTDA3.ppl);
			COM_send_string("\r\nAGC:");
			COM_send_int_as_string(rssiTDA3.agc);
			COM_send_string("\r\nEmpfangsleistung (dBm):");
			if (dig_to_dbm(rssiTDA3.ppl, rssiTDA3.agc) < 0) {
				COM_send_string("-");
			}
			COM_send_int_as_string(abs(dig_to_dbm(rssiTDA3.ppl, rssiTDA3.agc)));
			COM_send_string("\r\n");
			COM_send_string("Empfangene Daten:");
			for (int i = 0; i <= lengthTDA3; ++i) {
				COM_send_int_as_string(rx_data_TDA3[i]);

			}
			COM_send_string("\r\n\r\n");

			COM_send_string("TDA4:");
			COM_send_string("\r\nPMF:");
			COM_send_int_as_string(rssiTDA4.pmf);
			COM_send_string("\r\nPRX:");
			COM_send_int_as_string(rssiTDA4.prx);
			COM_send_string("\r\nRX:");
			COM_send_int_as_string(rssiTDA4.rx);
			COM_send_string("\r\nPPL:");
			COM_send_int_as_string(rssiTDA4.ppl);
			COM_send_string("\r\nAGC:");
			COM_send_int_as_string(rssiTDA4.agc);
			COM_send_string("\r\nEmpfangsleistung (dBm):");
			if (dig_to_dbm(rssiTDA4.ppl, rssiTDA4.agc) < 0) {
				COM_send_string("-");
			}
			COM_send_int_as_string(abs(dig_to_dbm(rssiTDA4.ppl, rssiTDA4.agc)));
			COM_send_string("\r\n");
			COM_send_string("Empfangene Daten:");
			for (int i = 0; i <= lengthTDA4; ++i) {
				COM_send_int_as_string(rx_data_TDA4[i]);

			}
			COM_send_string("\r\n\r\n");

			COM_send_string("TDA5:");
			COM_send_string("\r\nPMF:");
			COM_send_int_as_string(rssiTDA5.pmf);
			COM_send_string("\r\nPRX:");
			COM_send_int_as_string(rssiTDA5.prx);
			COM_send_string("\r\nRX:");
			COM_send_int_as_string(rssiTDA5.rx);
			COM_send_string("\r\nPPL:");
			COM_send_int_as_string(rssiTDA5.ppl);
			COM_send_string("\r\nAGC:");
			COM_send_int_as_string(rssiTDA5.agc);
			COM_send_string("\r\nEmpfangsleistung (dBm):");
			if (dig_to_dbm(rssiTDA5.ppl, rssiTDA5.agc) < 0) {
				COM_send_string("-");
			}
			COM_send_int_as_string(abs(dig_to_dbm(rssiTDA5.ppl, rssiTDA5.agc)));
			COM_send_string("\r\n");
			COM_send_string("Empfangene Daten:");
			for (int i = 0; i <= lengthTDA5; ++i) {
				COM_send_int_as_string(rx_data_TDA5[i]);

			}
			COM_send_string("\r\n\r\n");

			COM_send_string("TDA6:");
			COM_send_string("\r\nPMF:");
			COM_send_int_as_string(rssiTDA6.pmf);
			COM_send_string("\r\nPRX:");
			COM_send_int_as_string(rssiTDA6.prx);
			COM_send_string("\r\nRX:");
			COM_send_int_as_string(rssiTDA6.rx);
			COM_send_string("\r\nPPL:");
			COM_send_int_as_string(rssiTDA6.ppl);
			COM_send_string("\r\nAGC:");
			COM_send_int_as_string(rssiTDA6.agc);
			COM_send_string("\r\nEmpfangsleistung (dBm):");
			if (dig_to_dbm(rssiTDA6.ppl, rssiTDA6.agc) < 0) {
				COM_send_string("-");
			}
			COM_send_int_as_string(abs(dig_to_dbm(rssiTDA6.ppl, rssiTDA6.agc)));
			COM_send_string("\r\n");
			COM_send_string("Empfangene Daten:");
			for (int i = 0; i <= lengthTDA6; ++i) {
				COM_send_int_as_string(rx_data_TDA6[i]);

			}
			COM_send_string("\r\n\r\n");

			led_ctr = 400000;
			led_on(LED7);
			data_recieved = 0;
		}

		if (led_ctr) {
			led_ctr--;

			if (!led_ctr)
				led_off(LED7);
		}
	}
//	Ablaufschleife ENDE++++++++++++++++++++++++++++++++++++++++++++++++++++++++++++++++++++++++++

//ab hier nur zum Testen
//function for general test purposes
//general_test();

	while (1) {

	}

}

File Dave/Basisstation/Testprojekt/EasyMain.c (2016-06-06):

/******************************************************************************
 * @file     Main.c
 * @brief    Easy Start project: reads potentiometer in XMC4500 Hexagon
 *           Application Kit (Port 14.1) and uses this value for changing
 *           the blinking speed of LED located in port 3.9.
 *           ADC is converting continuously Ch1 in group 0 in background source
 *           The different blinking delays are implemented using a
 *           system timer that decrements a counter on each timer overflow
 *           This counter is controlled by the ADC result value (potentiometer)
 * @version  V1.0
 * @date     20. February 2015
 * @note
 * Copyright (C) 2015 Infineon Technologies AG. All rights reserved.
 ******************************************************************************
 * @par
 * Infineon Technologies AG (Infineon) is supplying this software for use with
 * Infineon’s microcontrollers.
 * This file can be freely distributed within development tools that are
 * supporting such microcontrollers.
 * @par
 * THIS SOFTWARE IS PROVIDED "AS IS".  NO WARRANTIES, WHETHER EXPRESS, IMPLIED
 * OR STATUTORY, INCLUDING, BUT NOT LIMITED TO, IMPLIED WARRANTIES OF
 * MERCHANTABILITY AND FITNESS FOR A PARTICULAR PURPOSE APPLY TO THIS SOFTWARE.
 * INFINEON SHALL NOT, IN ANY CIRCUMSTANCES, BE LIABLE FOR SPECIAL, INCIDENTAL,
 * OR CONSEQUENTIAL DAMAGES, FOR ANY REASON WHATSOEVER.
 *****************************************************************************/


#include <XMC4500.h>                    //SFR declarations of the selected device
#include "GPIO.h"

#define TICKS_PER_SECOND 10000

unsigned long timingdelay, adc_result;

void ADC0_Init(void);
void Delay100US (unsigned long time);
void SysTick_Handler(void);

int main(void)
{
	/* Setup the system timer to tick every 100us */
	SysTick_Config(SystemCoreClock / TICKS_PER_SECOND);

	/* Configure P3.9 (LED) */
	// P3.9 is used as GPIO for LED indication. Macros can be find in GPIO.h
	P3_9_set_mode(OUTPUT_PP_GP);
	P3_9_set_driver_strength(STRONG);
	P3_9_reset();

	/* Initialize and start ADC */
	ADC0_Init();

	/* Infinite loop */
	for(;;){
		do{
			adc_result =  VADC_G0->RES[1];
		} while (!(adc_result >> VADC_G_RES_VF_Pos));
                                        // wait until ADC result register 0 value is valid
                                        // VADC.G0RES1.VF = 1: Valid Flag
                                        // Indicates a new result in bitfield RESULT or bit FCR.
                                        // 1B = Bitfield RESULT has been updated with new
                                        // result value and has not yet been read, or bit
                                        // FCR has been updated

		adc_result &= 0xFFF;           // mask ADC result
		Delay100US((adc_result << 1) + 500);
                                       // tune minimum and maximum flashing time

		P3_9_toggle();
                                       // toggle P3.9 (toggle LED) using GPIO.h macros
	}
	return 0;
}


/**
 * @brief This function is to initialize the VADC peripheral to continuous conversion with background source\n
 * Channel 1 in group 0 takes part in the scan sequence. The result is sent to RESREG[0]\n
 * @param[in]   none \n
 * @return none\n
 *
 * <b>Reentrancy:  no</b><BR>
 *
 */
void ADC0_Init(void)
{
	SCU_RESET->PRCLR0 |= ((1 << SCU_RESET_PRSET0_VADCRS_Pos) & SCU_RESET_PRSET0_VADCRS_Msk);
                                        // De-assert reset: VADC Reset Clear Reset Clear = 1

	//Global ADC Initialization

	VADC->CLC         =  ((0 << VADC_CLC_DISR_Pos) & VADC_CLC_DISR_Msk) |
                                        // DISR = 0: Module Disable Request Bit
                                        // 0B On request: enable the module clock
                       	 ((0 << VADC_CLC_DISS_Pos) & VADC_CLC_DISS_Msk) |
                                        // DISS = 0: Module Disable Status Bit
                                        // 0B Module clock is enabled
                       	 ((0 << VADC_CLC_EDIS_Pos) & VADC_CLC_EDIS_Msk);
                                        // EDIS = 0: Sleep Mode Enable Control
                                        // 0B Sleep mode request is enabled and functional
	// Wait for module clock enabled
	while(VADC->CLC!=0);                  // DISS: Module Disable Status Bit
                                        //  0B Module clock is enabled

	VADC->GLOBCFG     =  ((6 << VADC_GLOBCFG_DIVA_Pos) & VADC_GLOBCFG_DIVA_Msk) |
                                        // DIVA = 6: Divider Factor for the Analog Internal Clock
                                        // fADCI = fADC / (DIVA + 1) = fADC / 7
                       	 ((1 << VADC_GLOBCFG_DIVWC_Pos) & VADC_GLOBCFG_DIVWC_Msk);
                                        // DIVWC = 1: Write Control for Divider Parameters
                                        // Bitfields DIVA, DCMSB, DIVD can be written

	//Arbitration
	VADC_G0->ARBCFG   =  ((VADC_G0->ARBCFG &
                       	 ~(VADC_G_ARBCFG_ANONC_Msk | VADC_G_ARBCFG_ARBRND_Msk | VADC_G_ARBCFG_ARBM_Msk)) |
                                        // Clear relevant bits
                       	 (((3 << VADC_G_ARBCFG_ANONC_Pos) & VADC_G_ARBCFG_ANONC_Msk) |
                                        // ANONS = 11B: Analog Converter Control: Normal Operation
                                        //  The converter is active, conversions are started immediately.
                                        //  Requires no wakeup time.
                       	 ((0 << VADC_G_ARBCFG_ARBRND_Pos) & VADC_G_ARBCFG_ARBRND_Msk)|
                                        // ARBRND = 00B: Arbitration Round Length
                                        //  00B: 4 arbitration slots per round (tARB = 4 / fADCD)
                         ((0 << VADC_G_ARBCFG_ARBM_Pos) & VADC_G_ARBCFG_ARBM_Msk)));
                                        // ARBM = 0B: Arbitration Mode: The arbiter runs permanently
  
	VADC_G0->ARBPR    =  ((VADC_G0->ARBPR &
                         ~(VADC_G_ARBPR_ASEN2_Msk | VADC_G_ARBPR_PRIO0_Msk)) |
                                        // clear relevant bits
                         (((1 << VADC_G_ARBPR_PRIO0_Pos) & VADC_G_ARBPR_PRIO0_Msk) |
                                        // PRIO0 = 1: Priority of Request Source x (x = 0)
                                        //  Arbitration priority of request source x (in slot x)
                         ((1 << VADC_G_ARBPR_ASEN2_Pos) & VADC_G_ARBPR_ASEN2_Msk)));
                                        // ASEN2 = 1: Arbitration Slot 2 Enable

	//Conversion result storage
	VADC_G0->CHCTR[1] =  ((0x1 << VADC_G_CHCTR_RESREG_Pos) & VADC_G_CHCTR_RESREG_Msk);
                                        // Channel 1 is directed to RESREG1
                                        //  0001B Store result in group result register GxRES1
                                        //  = VADC_G0->RES[1]
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

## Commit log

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2016-05-09 ICs in Altium eingefügt
    [Power Supply.SchDoc, TDA5340.SchDoc, XMC4500.SchDoc]
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2016-05-10 SPI Signal Harness eingefügt
    [Power Supply.SchDoc, TDA5340.SchDoc, XMC4500.SchDoc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]
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2016-05-11 TDA verbunden Testplatine erstellt
    [PCB_Testplatine.PcbDoc, Power Supply.SchDoc, TDA5340.SchDoc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]
2016-05-11 Würth lib addded und JTAG hinzugefügt
    [PCB_Testplatine.PcbDoc, Power Supply.SchDoc, mobile Basisstation.PrjPcb]
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2016-05-13 Vor Wechsel zu Package 144
    [PCB_Testplatine.PcbDoc, Power Supply.SchDoc, XMC4500.SchDoc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]
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2016-05-18 Fehler in SPI korrigiert
    MOSI MISO waren vertauscht
    [Power Supply.SchDoc, TDA5340_1.SchDoc, XMC4500.SchDoc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]
2016-05-18 Anpassnetzwerk und Antenne angebaut; Quarze getauscht und alle Bauteiel umbenannt
    [PCB_Testplatine.PcbDoc, Power Supply.SchDoc, TDA5340_1.SchDoc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]
2016-05-18 ESD Diode von Würth hinzugefügt
    [Power Supply.SchDoc, mobile Basisstation.PrjPcb]
2016-05-18 Beginn Layout DR Datei added
    [PCB_Testplatine.PcbDoc, TDA-sma_rev2.PcbDoc, TDA5340_1.SchDoc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]
2016-05-19 Ethernet begonnen, Würth Buchse eingefügt
    [Ethernet.SchDoc, PCB_Testplatine.PcbDoc, mobile Basisstation.PrjPcb]
2016-05-19 KSZ8031RNL in Lib erstellt
    [Ethernet.SchDoc, mobile Basisstation.PrjPcb]
2016-05-19 Ethernetcontroller erstellt und eingefügt
    [Ethernet.SchDoc, mobile Basisstation.PrjPcb]
2016-05-19 Ethernet fertig
    sollte noch geprüft werden
    [Ethernet.SchDoc, Power Supply.SchDoc, mobile Basisstation.PrjPcb]
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2016-05-19 Ethernet connected mit XMC
    [XMC4500.SchDoc]
2016-05-20 TDA Sheet angepasst und umbenannt
    noch vor Erstellen Multi Sheet design
    [Bank TDA5340.SchDoc, TDA5340.SchDoc, TDA5340_1.SchDoc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]
2016-05-20 Projekt ist nun MultiChannelprojekt
    [Bank TDA5340.SchDoc, PCB_Testplatine.PcbDoc, TDA5340.SchDoc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]
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2016-05-20 made Basisstation to hierarchical design
    [Basisstation.SchDoc, Ethernet.SchDoc, PCB_Testplatine.PcbDoc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]
2016-05-20 Versehentliches Verschieben des SMA Anschlusses im Original von Stefan Erhard wieder entfernt
    [TDA-sma_rev2.PcbDoc]
2016-05-20 Pin Header auf je 10 Pins reduziert
    [PCB_Testplatine.PcbDoc, TDA5340.SchDoc]
2016-05-20 PPRF and PPRF_RSSI not connected
    [Power Supply.SchDoc, TDA5340.SchDoc]
2016-05-20 Ports von PPRF(_RSSI) auch im Überdockument entfernt
    [XMC4500.SchDoc]
2016-05-20 restliche Verbindungen mit XMC hinzugefügt
    [XMC4500.SchDoc]
2016-05-20 Erste Schritte Layout
    Room angepasst, bauteile grob angeordnet
    [PCB_Testplatine.PcbDoc, TDA-antenna_rev2.PcbDoc, XMC4500.SchDoc]
2016-05-23 größe Ind. Anpassnetzwerk geändert und einen überflüssigen widerstand aus PWR Supply TDA entfernt
    [PCB_Testplatine.PcbDoc, TDA5340.SchDoc]
2016-05-23 Bauteile vorerst fertig plaziert
    [PCB_Testplatine.PcbDoc]
2016-05-23 Routing supply und erste teile am Connector
    [PCB_Testplatine.PcbDoc]
2016-05-23 Pins PP2 und PP0 am Header getauscht
    [TDA5340.SchDoc]
2016-05-23 GND und VDD größtenteils gerouted
    [PCB_Testplatine.PcbDoc]
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2016-05-24 Libraries chanched and XMC Layout
    [PCB_Testplatine.PcbDoc, Power Supply.SchDoc, mobile Basisstation.PrjPcb]
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2016-05-24 Anordnen der Componenten Ethernet
    [PCB_Testplatine.PcbDoc, Power Supply.SchDoc]
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2016-05-24 Anordnung der Rooms grob
    [PCB_Testplatine.PcbDoc]
2016-05-25 Layout PWR und USB
    [Ethernet.SchDoc, PCB_Testplatine.PcbDoc, Power Supply.SchDoc]
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2016-05-25 bevor Layout Ethernet an große Platine angepasst
    [PCB_Testplatine.PcbDoc]
2016-05-25 Falsches Pad in eigener PCB lib ausgebessert
    [Ethernet.SchDoc, PCB_Testplatine.PcbDoc]
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2016-05-25 Anordnung der TDA im Kreis
    [PCB_Testplatine.PcbDoc]
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2016-05-25 TDA 6 &1 Pins getauscht
    [PCB_Testplatine.PcbDoc, XMC4500.SchDoc]
2016-05-25 Alles außer GND und VDD gerouted
    [PCB_Testplatine.PcbDoc, Power Supply.SchDoc, XMC4500.SchDoc]
2016-05-25 Beginn GND und VDD
    [PCB_Testplatine.PcbDoc]
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2016-05-27 entfernen der Hilfszeichnnungen TDA
    [PCB_Testplatine.PcbDoc]
2016-05-30 RTC Quarz getauscht
    das gewählte Gehäuse war für ein RTC Quarz nicht verfügbar
    [PCB_Testplatine.PcbDoc, Power Supply.SchDoc]
2016-05-30 Pins PP2 getauscht auf Interrupt
    Alle PP2 Pins müssen auf einen Interrupt-Kanal des XMC gelegt werden.
    Dies wurde umgesetzt und andere Pins/Netze entsprechend getauscht
    [PCB_Testplatine.PcbDoc, XMC4500.SchDoc]
2016-05-30 Polgon um VDD erstellt
    [PCB_Testplatine.PcbDoc]
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2016-05-30 Top nund Bottom GND Metalisierung eingbracht
    [PCB_Testplatine.PcbDoc]
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2016-05-31 TDA GND Polygon over same net
    GND Poly over all same net objects on all TDAs
    [PCB_Testplatine.PcbDoc]
2016-05-31 mehr LEDs und Power Supply über Stiftleiste hinzugefügt
    [Power Supply.SchDoc, XMC4500.SchDoc]
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2016-05-31 Led Würth
    LEDs durch Würth ersetzt, entsprechende Lib hinzugefügt
    [XMC4500.SchDoc, mobile Basisstation.PrjPcb]
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2016-06-01 GND Netze entfernt und GND auf TDAs mit Poly connected
    [PCB_Testplatine - GND mit Tracks.PcbDoc, PCB_Testplatine.PcbDoc]
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2016-06-02 Tracks an Übergang zu TDAs nun nicht mehr rechtwinklig
    [PCB_Testplatine.GBL, PCB_Testplatine.GBP, PCB_Testplatine.GBS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]
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2016-06-02 Bestückungsdruck angeordnet und DRC Fehler behoben
    [PCB_Testplatine.PcbDoc]
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2016-06-16 Änderungen von Felix übernommen
    Änderungen wurden übernommen: Taster für Reset, verschieben der
    Leiterbahnen, andere Bauteilwerte im Anpassnetzwerk
    [PCB_Testplatine.PcbDoc, Power Supply.SchDoc, TDA5340.SchDoc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]
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2016-07-01 Abfrage mit allen TDAs geglückt. Fehler in TDA set_status korrigiert
    [TDA.c]
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2016-08-09 Globale Interrupt Flag variablen Angepasst
    volatile entfernt (funktioniert das ohne Probleme? oder wird dann nicht
    jedesmal ausgelsen)
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
